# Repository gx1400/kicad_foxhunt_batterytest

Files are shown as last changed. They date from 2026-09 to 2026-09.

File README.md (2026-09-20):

# Fox Hunt Controller — Hardware Design

Custom amateur radio fox hunt (hidden transmitter) controller, aimed at being a flexible, dynamic platform for a wide range of fox-hunt formats — not just a fixed single-mode beacon. Built around an ESP32-S3, u-blox GPS module (MAX-M10S), and SA818S 2m RF module, with a WiFi/BLE web UI for configuration and "found" logging, RTOS-based scheduling, RTC-driven wake and precise TX timing, GPS-disciplined timekeeping, and APRS output capability. Firmware developed in PlatformIO. Boards fabricated and assembled via JLCPCB (including their SMT assembly service). Planned as an iterative multi-revision build, proving out core software before locking down hardware.

**Note:** this initial revision is a dev/learning board — built to test out the design, get hands-on with the parts and tooling, and work out mistakes before committing to a more polished revision.

## Contents

- [Setup](#setup)
- [Power architecture overview](#power-architecture-overview) (diagram — full detail in `_docs/`)
- **[Full docs index →](_docs/README.md)** — hardware design detail, controller/peripheral platform decisions, BOM sourcing/datasheets, open items

## Setup

All KiCad design files live under [`pcb/`](pcb/) — project file, schematics, PCB, and the vendored libraries. This project depends on three external symbol/footprint libraries, vendored as git submodules under `pcb/libs/` so the project is self-contained and doesn't require any machine-specific KiCad library setup. Project-level `sym-lib-table` and `fp-lib-table` files reference them via `${KIPRJMOD}`, so they resolve automatically once the submodules are checked out — no manual library registration needed.

Clone with submodules:

```sh
git clone --recurse-submodules https://github.com/gx1400/kicad_foxhunt_batterytest.git
```

The KiCad project file is at `pcb/foxhunt1.kicad_pro`.

Or, if already cloned:

```sh
git submodule update --init --recursive
```

Everything else (standard KiCad libraries: `Device`, `power`, `Resistor_SMD`, etc.) ships with any stock KiCad 10 install — no extra setup required.

## Power Architecture Overview

Two independent power sources feed the board, combined safely before regulation, then split into two independently-regulated rails:

```
18650 pack ──[MAX17320 protector]── +7.5V ──┐
                                              ├─[TPS2121 VCOMP]── VRAW ──[soft-latch FET]──┬─[Buck+LDO]── 5V  (SA818S)
12–14.5V input ──[fuse]── +12V ──────────────┘                                            └─[Buck+LDO]── 3.3V (ESP32-S3, GPS)
```

Full detail (battery protection, dual-input combining, regulation, the whole planned controller/peripheral platform, BOM sourcing, and open items) lives in **[`_docs/`](_docs/README.md)**.

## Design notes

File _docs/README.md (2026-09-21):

# Docs Index

Everything below the top-level [README](../README.md). Grouped by topic — add new docs to the
matching folder and list them here.

## Hardware (`hardware/`)

Design decisions and reference detail for the PCB. Start with the architecture overview, then
drill into whichever subsystem you need.

- [Power architecture overview](hardware/power_architecture.md) — the two-source-combine-then-regulate diagram, links to the three sections below
- [Battery protection & fuel gauge (MAX17320)](hardware/battery_protection.md)
- [Dual-input power combining](hardware/power_input_combining.md)
- [Regulation — VRAW → 5V/3.3V rails, downstream loads](hardware/regulation.md)
- [Controller & peripheral platform](hardware/controller_platform.md) — VRAW soft-latch, PCF8563 RTC, PCA9555 I2C GPIO expander, WS2812 status LED, CAT24C32YI-GT3 EEPROM, SD card (SPI), MCU (ESP32-S3 + dual-USB), USB power path, GPS, and audio/PTT DAC path implemented; SA818S itself, the external-HT jack, RF sensing, TX safety, frequency/tone plan, LoRa (skipped), enclosure still planned
- [ESP32-S3 pinout & interconnect plan](hardware/esp32s3_pinout.md)
- [Audio / PTT path — I2S DAC, ESP32-S3, SA818S, external HT](hardware/audio_ptt_path.md) — PCM5102A DAC + attenuator + switched external-HT jack (J11) + PTT FET (Q10) implemented
- [SA818S-V pinout & interconnect plan](hardware/sa818_pinout.md) — module placed with UART/PTT/MIC_IN wired; VBAT, ANT, PD, H/L still open
- [VHF matching network & RF forward-power detector](hardware/vhf_matching_detector.md) — parts, layout, and sourcing for the antenna matching ladder and diode-detector power-sensing tap; not yet in the schematic
- [GPS — u-blox MAX-M10S, ESP32-S3, backup power, SMA antenna](hardware/gps_path.md) — implemented, including the CR2032/supercap backup network and RF bias-tee
- [I2C bus — devices & addresses](hardware/i2c_bus.md)
- [IC inventory & alternatives](hardware/ic_inventory.md) — every IC/module used or planned, LCSC MPN/price/stock, and 1-4 scored alternates per chip
- [Open items / next steps](hardware/open_items.md) — living checklist

## Sourcing (`sourcing/`)

BOM verification and part-sourcing records — datasheets, 3D models, LCSC cross-reference.

- [Task 1 — LCSC/MPN/manufacturer cross-reference](sourcing/task1_lcsc_crossreference.md) — action-item checklist
- [kicad_gx_library datasheets](sourcing/kicad_gx_library_datasheets.md)
- [project_library datasheets](sourcing/project_library_datasheets.md)
- [3D models — search & download status](sourcing/3d_models.md)

## Firmware (`firmware/`)

Reserved for once the PlatformIO project (`src/`) exists — see [firmware/README.md](firmware/README.md).

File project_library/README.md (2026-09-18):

# Project Library

Local library resources for parts used in this project that are **not** part of the shared
`libs/kicad_gx_library/` (which holds reusable custom symbols/footprints/3D models
maintained across projects). Everything here is specific to `foxhunt1`.

## Structure

- `datasheets/` — PDF datasheets for placed components, organized into per-manufacturer
  subfolders (e.g. `Murata_Electronics/`, `YAGEO/`, `TI/`). Schematic component `Datasheet`
  fields reference these files via `${KIPRJMOD}`-relative paths. See
  `_docs/sourcing/project_library_datasheets.md` for the full part-to-file mapping, including two
  parts (BH-18650-PC, 1377G12-BK) with no available datasheet source.
- `symbols/` — reserved for project-specific KiCad symbols not in `kicad_gx_library`.
  Not yet populated.
- `footprints/` — reserved for project-specific KiCad footprints not in `kicad_gx_library`.
  Not yet populated.
- `3dmodels/` — downloaded 3D models (STEP preferred) for manual placement/alignment.
  Not linked to schematic/footprint parts automatically — see
  `_docs/sourcing/3d_models.md` for status (covers both `kicad_gx_library` and this directory).

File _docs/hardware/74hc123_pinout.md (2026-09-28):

# 74HC123 — Dual Retriggerable Monostable — Pinout & Planned Interconnects

Covers the dual retriggerable monostable multivibrator (Nexperia **74HC123D,653**, LCSC
`C5597`, SOIC-16/SOT109-1 — see `ic_inventory.md`) with **two independent planned uses on
this board**: one section as the TX-safety PTT hardware timeout (`controller_platform.md`
§ TX safety), the other — the "spare half" — as the hardware force-off failsafe
(`open_items.md`). KiCad symbol `74xx:74HC123` / footprint
`Package_SO:SOIC-16_3.9x9.9mm_P1.27mm` (stock libraries, both pin-verified against
Nexperia's own datasheet — no library fix needed).

**This part is not placed in the schematic yet** (`open_items.md`: "the 74HC123 isn't
placed in the schematic either way"). Everything below is a planning document, same rigor
level as `vhf_matching_detector.md` before that ladder existed: real pin functions from the
datasheet, but "planned tie/connection" is intent pulled from `controller_platform.md` /
`open_items.md` / `audio_ptt_path.md`, not something to treat as already wired. Two of the
four trigger nets involved (the retrigger source for the TX-timeout half, and the level of
    `POWER_PB_SIGNAL` feeding the force-off half) depend on design decisions that aren't made
yet either — flagged individually below, and again in § 4.

## 1. Full pin table

Reference: Nexperia `74HC_HCT123` datasheet Rev. 13 (2024-02-21), Table 2 (pin
description) and Table 3 (function table), SO16/SOT109-1 pinout.

| Pin | Name | I/O | Function (per Nexperia's own datasheet) | Planned tie/connection |
| --- | --- | --- | --- | --- |
| 1 | 1A | I | Negative-edge triggered input, unit A (Schmitt) | **Unit A = TX-safety timeout.** Not yet decided whether A or B is the active retrigger input for this half — see § 3. If unused, tie to the level the function table calls for with the other input active (function table: triggering needs `nRD`=H; with `nB`=H, a falling edge on `nA` triggers — so if B is the active input instead, tie `1A` low). |
| 2 | 1B | I | Positive-edge triggered input, unit A (Schmitt) | Mutual with `1A` above — whichever of A/B carries the periodic MCU "keep transmitting" pulse from the PTT-intent path; the other ties to its inactive level. |
| 3 | 1R̄D | I | Direct reset LOW (async, overrides everything) + positive-edge triggered input | Planned: pulled to VCC (inactive) unless a system-level "kill PTT now" reset source is defined. Also see the datasheet's own power-up-glitch note (§ Application information, Fig. 12) — an R̄D-side RC network held low briefly after power-up avoids a spurious startup pulse, which here would mean a spurious momentary PTT key. Not yet designed. |
| 4 | 1Q̄ | O | Active-LOW output, unit A | Planned, with `13`/`1Q`: series-gates the existing PTT path (`IO16` → `Q10` → `J11` → SA818S/HT `PTT`, see `sa818_pinout.md`/`audio_ptt_path.md`) per `controller_platform.md` § TX safety — "gates the PTT line in series with the MCU's own PTT-intent GPIO." Exact insertion point (ahead of `Q10`'s gate, in series with its drain, or ahead of the still-unselected PTT-keying optocoupler) is undecided — open item. |
| 13  | 1Q | O | Active-HIGH output, unit A | See `1Q̄` above — whichever polarity fits the eventual gate implementation. |
| 14  | 1CEXT | — | External timing capacitor connection, unit A | Planned RC timing network for the **2-minute hard TX ceiling** — see § 3 for calculated starting values. Per the datasheet's own app-note (Fig. 11): cap goes between this pin and `15`/`1REXT/CEXT`. |
| 15  | 1REXT/CEXT | — | External timing resistor+capacitor connection, unit A | Resistor to VCC, per the same app-note figure. See § 3 for values. |
| 5 | 2Q | O | Active-HIGH output, unit B | **Unit B = spare-half hardware force-off failsafe** (`open_items.md`). Planned to assert an override of `PWR_LATCH`/`Q6`'s hold (`controller_platform.md` § Power sequencing) if the software hold-to-power-off timeout is exceeded. The actual override mechanism — how a one-shot output edge forces `PWR_LATCH` low against a possibly-still-asserting `Q6` — is the main undecided piece here, not just an RC value. |
| 6 | 2CEXT | — | External timing capacitor connection, unit B | RC target: "longer than the software hold threshold" (`open_items.md`). That firmware threshold isn't documented yet (hold-to-power-off firmware is itself still TBD per the same doc), so no concrete value can be calculated for this half yet — blocked on a firmware constant, unlike unit A's timing. |
| 7 | 2REXT/CEXT | — | External timing resistor+capacitor connection, unit B | Same block as `2CEXT` above. |
| 8 | GND | — | Ground | Planned: `GND`. |
| 9 | 2A | I | Negative-edge triggered input, unit B (Schmitt) | Planned force-off trigger, per `open_items.md`'s leading option: "triggered directly by SW3 (or its isolated `POWER_PB_SIGNAL` node)." **See the voltage-domain flag in § 4 — this can't actually be direct.** |
| 10  | 2B | I | Positive-edge triggered input, unit B (Schmitt) | Mutual with `2A` — same flag applies. |
| 11  | 2R̄D | I | Direct reset LOW (async) + positive-edge triggered input, unit B | Same treatment as `1R̄D` (tie inactive, consider the Fig. 12 power-up RC). Also the natural place to let firmware abort the hardware failsafe once a normal software power-off succeeds in time, if that's ever wanted — not yet decided. |
| 12  | 2Q̄ | O | Active-LOW output, unit B | See `2Q` above. |
| 16  | VCC | — | Supply, 2.0–6.0V (74HC) | Planned: not yet decided which rail — see § 4. |

## 2. Trigger logic (datasheet Table 3, function table)

For either unit, with `nR̄D` = HIGH: a falling edge on `nA` while `nB` is HIGH triggers a
new pulse, or a rising edge on `nB` while `nA` is LOW triggers a new pulse — either
re-triggers (extends) an already-running pulse the same way. `nR̄D` = LOW forces `nQ` LOW /
`nQ̄` HIGH immediately regardless of `nA`/`nB`, overriding any in-progress pulse. This is
what makes it *retriggerable*: as long as the active input keeps getting valid edges before
the RC-timed pulse would otherwise end, the output stays asserted indefinitely — exactly
the property the TX-safety design in `controller_platform.md` depends on ("the MCU must
periodically retrigger it during a legitimate transmission").

## 3. Unit A — TX-safety timeout: starting RC values

Target: **2-minute (120s) hard ceiling** per `controller_platform.md` § TX safety.

Datasheet's own pulse-width formula (§10, footnote [2], valid for `CEXT` > 10nF):

```
tW (ns) = K × REXT (kΩ) × CEXT (pF)
K ≈ 0.45 at VCC = 5.0V, ≈ 0.55 at VCC = 2.0V (Fig. 6 — K drifts with VCC, "typical" only)
```

Recommended `REXT` range per the datasheet's own dynamic-characteristics table: 2kΩ–1000kΩ
at VCC = 5.0V. Solving for `tW` = 120s = 1.2×10¹¹ ns at K = 0.45:

| REXT | Required CEXT | Notes |
| --- | --- | --- |
| 470kΩ | ≈ 560µF | Mid-range R, needs a real electrolytic/tantalum at this value — not a ceramic. |
| 1MΩ (datasheet's own max) | ≈ 270µF | Smaller, cheaper cap; R right at the recommended ceiling. |

**Rigor note, same as this board's other tuned RC/LC values (matching network, mic
attenuator):** this is a calculated starting point from the datasheet's typical-K formula,
not a bench-verified number — `K` itself is only characterized at the 2V/6V endpoints in
the datasheet (Fig. 6), and electrolytic/tantalum tolerance at these values is loose.
Populate one of the pairs above, then verify the actual timeout against a bench timer
before trusting it for the real 2-minute ceiling. Per the datasheet's own app-note (Fig.
11): `CEXT` connects between pins 14/6 and 15/7, `REXT` from pin 15/7 to VCC.

Also relevant to the retrigger-pulse firmware: the datasheet gives a **minimum retrigger
interval** formula (§10, footnote [3]) — `t_rtrig ≈ 30 + 0.19×REXT×CEXT^0.9 +
13×REXT^1.05` ns (REXT in kΩ, CEXT in pF) — the MCU's periodic "still transmitting" pulses
need to be spaced at least this far apart to reliably retrigger rather than being missed;
at the values above this works out to a floor far below any sane firmware polling
interval, but it's a real constraint worth having in the design record.

## 4. Open design questions (nothing here is schematic yet)

- **`POWER_PB_SIGNAL` can't feed unit B directly, despite how `open_items.md` phrases it.**
  `POWER_PB_SIGNAL` is pulled up to `VRAW` through R45 (`controller_platform.md`), so it
  swings across `VRAW`'s full range (up to ~14.4V) — not a 3.3V/5V logic level. The
  74HC123's own absolute-max rating is `VI` ≤ `VCC` + 0.5V with `VCC` capped at 7V (Table 4,
  limiting values). Raw `POWER_PB_SIGNAL` already couldn't go straight into `GPIO38` for
  the same reason — that's exactly why `Q9` (BSS138) exists as a level-shift stage there
  (`esp32s3_pinout.md`, pin 31). Unit B's trigger will need the same kind of level-shift
  stage in front of it, not a direct wire.
- **VCC rail choice — 3.3V vs 5V — not yet decided.** Both are within the datasheet's
  2.0–6.0V recommended range. 3.3V would match the MCU GPIO logic that both trigger paths
  ultimately originate from (unit A's retrigger pulse, and a level-shifted `POWER_PB_SIGNAL`
  for unit B via a `Q9`-style stage); 5V would match the SA818S/`VBAT` domain the PTT
  circuit downstream of unit A ultimately touches. Pick one before laying out the timing
  RC networks, since it also shifts `K` slightly (§ 3).
- **Stale cross-reference:** `audio_ptt_path.md` § 3 still describes a "MCU PTT-intent GPIO
  (`IO15`) → 74HC123 TX-safety gating" chain. `esp32s3_pinout.md`'s own live-schematic audit
  (item 7 in its notes) says that two-GPIO AND-gate scheme isn't what got built — PTT today
  is a single GPIO (`IO16`) straight into `Q10`, and `IO15` is free again. Worth updating
  `audio_ptt_path.md` § 3 once the real 74HC123 gating point is designed, so it stops citing
  a scheme that was already abandoned.
- **Exact PTT-gating insertion point** (unit A) — series with `Q10`'s gate, its drain, or
  ahead of the still-unselected PTT-keying optocoupler (`ic_inventory.md`) — undecided.
- **Exact force-off override mechanism** (unit B) — how the output edge actually forces
  `PWR_LATCH` low against a possibly-still-asserting `Q6` — undecided; flagged in
  `open_items.md` as "next thing being worked on," not yet started.
- **Power-up glitch handling** (both halves) — the datasheet's own Fig. 12 circuit (an RC
  network holding `nR̄D` low briefly after power-up) prevents a spurious pulse at boot; for
  unit A that would mean a spurious momentary PTT key, for unit B a spurious force-off
  assertion. Not yet designed either.

## 5. Reference documents

- [`ic_inventory.md`](ic_inventory.md) — Nexperia `74HC123D,653` sourcing (LCSC `C5597`,
  SOIC-16/SOT109-1, $0.33 5pc).
- [`controller_platform.md`](controller_platform.md) § TX safety, § Power sequencing — the
  two design intents this part serves.
- [`open_items.md`](open_items.md) — the force-off item that names this part as the leading
  option.
- [`audio_ptt_path.md`](audio_ptt_path.md) § 3 — the PTT chain this gates into (see the
  staleness flag in § 4 above).
- [`esp32s3_pinout.md`](esp32s3_pinout.md) — `IO16`/`IO15` (PTT-intent), `IO38`/`IO48`
  (hold-to-power-off / self-latch) pin assignments.
- **[Nexperia 74HC123;74HCT123 datasheet](https://assets.nexperia.com/documents/data-sheet/74HC_HCT123.pdf)**,
  Rev. 13 (2024-02-21) — pin table (§5), function table (§6), timing/retrigger formulas
  (§10, footnotes [2]/[3]), application info and power-up circuit (§11, Fig. 11/12).

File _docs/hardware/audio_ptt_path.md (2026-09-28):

# Audio / PTT Path — I2S DAC ↔ ESP32-S3 ↔ SA818S / External HT

Not yet in the schematic — this is the interconnect plan for the next placement pass,
covering the I2S DAC (PCM5102APWR, already chosen — see `ic_inventory.md`), its link to the
ESP32-S3, and how its output (and the PTT-keying signal) reach both the onboard SA818S
footprint and the external-HT 3.5mm jack. See `controller_platform.md` § Audio / PTT path
for why this is one shared subsystem serving two destinations, not two separate designs.

## 1. DAC ↔ ESP32-S3 (I2S bus)

**Part: TI PCM5102A** (20-pin TSSOP, `C107671`). Real pin table, from TI's own datasheet
(PCM5100A/5101A/5102A family, SLAS859A):

| Pin | Name | Function | Planned tie/connection |
| --- | --- | --- | --- |
| 12 | SCK | System clock input | **Tie to GND.** Selects the DAC's internal PLL auto-clock mode — no master clock (MCLK) needed from the MCU. ESP32-S3's I2S peripheral doesn't need to supply one either; this is the standard simplified hookup used by every hobbyist PCM5102 breakout (Adafruit's included — see § 4). |
| 13 | BCK | Bit clock input | ESP32-S3 IO14 (`esp32s3_pinout.md` — currently documented as I2S BCLK) |
| 14 | DIN | Serial audio data input | ESP32-S3 IO47 (documented as I2S DOUT — MCU transmits, DAC receives) |
| 15 | LRCK | Word clock (L/R select) input | ESP32-S3 IO21 (documented as I2S LRCLK/WS) |
| 16 | FMT | Audio format select (Low = I2S, High = left-justified) | **Tie to GND** — I2S format, matches ESP32-S3's I2S peripheral default |
| 10 | DEMP | De-emphasis control (Low = off) | **Tie to GND** — no de-emphasis needed |
| 11 | FLT | Filter select (Low = normal latency, High = low latency) | **Tie to GND** — normal latency; nothing in this design needs low-latency monitoring |
| 17 | XSMT | Soft-mute control (Low = mute, High = un-mute) | **Needs a decision** — simplest is tie to `+3.3V` (always un-muted, matches PCM5102A's own DirectPath output design which needs no external mute circuit for pop-free power-up per TI's datasheet), but see § 3 for why the switching mechanism might want to drive this from a spare GPIO instead |
| 6 | OUTL | Analog output, 2.1V<sub>RMS</sub> line level | → level-matching network → SA818S/HT (§ 2) — SA818S is mono, only one channel is needed (confirmed: its `MIC_IN` and `AF_OUT` are each a single pin, no L/R pair, per its own datasheet) |
| 7 | OUTR | Analog output, 2.1V<sub>RMS</sub> line level | → standard RC output filter only (no attenuator — nothing mic-level on this leg) → spare JST breakout (§ 2), for future use |
| 1, 8, 20 | CPVDD, AVDD, DVDD | Power, 3.3V | `+3.3V` |
| 18 | LDOO | Internal LDO decoupling (or external 1.8V) | Decoupling cap only, per datasheet — not using external 1.8V supply mode |
| 3, 9, 19 | CPGND, AGND, DGND | Grounds | `GND` |
| 2, 4 | CAPP, CAPM | Charge-pump flying cap | Per datasheet's charge-pump cap network |
| 5 | VNEG | Charge-pump negative rail (-3.3V) | Decoupling only |

Recommended output filter, straight from TI's own datasheet (footnote on the dynamic
performance table): **470Ω series resistor + 2.2nF shunt cap** per channel, into a ≥10kΩ
load. This is the standard simple RC low-pass already anticipated in
`controller_platform.md` ("I2S DAC → RC filter").

**ESP32-S3 side**: IO14/IO21/IO47 already reserved in `esp32s3_pinout.md`. No MCLK pin
reserved — confirmed not needed per SCK-tied-low above.

## 2. DAC output ↔ SA818S / external HT (level matching + switching)

**Confirmed: SA818S is mono** — `MIC_IN` (pin 18) and `AF_OUT` (pin 3) are each a single
pin in its datasheet, no L/R pair. Only `OUTL` is needed for the SA818S/HT path. `OUTR`
is otherwise unused, so it gets the standard 470Ω + 2.2nF output filter (same as `OUTL`,
no attenuator — there's no mic-level target on this leg) and is broken out to its own
spare JST connector for future use.

**Now placed in the schematic** (`audio.kicad_sch`, verified 2026-09-20): both channels'
output filters and the charge-pump network are built and match this doc's plan —

- `OUTR` → R47 (470Ω) → C63 (2.2nF to GND) → **J9** (spare 3-pin JST, pins 2/3 to GND) — done.
- `OUTL` → R48 (470Ω) → C64 (2.2nF to GND) → currently ends at an open node, awaiting the
  attenuator network (§ below) and the SA818S/HT connection once placed.
- Charge pump: C55 (2.2µF, `CAPP`↔`CAPM` flying cap) and C56 (2.2µF, `VNEG`↔`GND`
  reservoir cap) — matches TI's Figure 39/41 reference circuit.
- `XSMT` is wired to a live hierarchical label (`I2S_XSMT`) back to the ESP32-S3 sheet
  rather than hard-tied — the tie-off decision below is resolved as GPIO-controlled,
  not tied high; not yet confirmed which physical GPIO drives it.

**OUTL → MIC_IN attenuator — now placed** (`audio.kicad_sch`, verified 2026-09-20):
`R49` (100kΩ, top fixed) → `RV1` (Bourns 3314G, 1kΩ single-turn trimmer,
`Potentiometer_SMD:Potentiometer_Bourns_3314G_Vertical` — real stocked footprint;
note it's single-turn, not 10-turn — no genuine 10-turn part in the LCSC list checked
had a matching KiCad footprint) → `R50` (150Ω floor) → GND. Trimmer's full travel spans
roughly 3–24mV (bracketing the SA818S datasheet's ~10mV reference point), never close to
overdriving the mic input even at either extreme. `R_top` at 100kΩ is comfortably above
the 470Ω filter resistor (won't detune its corner) and the PCM5102A's own ≥10kΩ minimum
load spec.

**DC-blocking cap — placed.** C65 (4.7µF, `Device:C_Small` — non-polarized ceramic, 0603)
sits correctly in series between `RV1`'s wiper and the net that will eventually reach
`MIC_IN`. Sized so the high-pass corner stays under ~70Hz even in a pessimistic
(~500Ω) assumption for the divider's output impedance plus `MIC_IN`'s undocumented input
impedance — comfortably below the ~300Hz low end of a voice/NBFM channel.

**`I2C_MIC_OUT` sheet pin — now added.** The net downstream of C65 has a real sheet pin
on the Audio sheet symbol (root level) exposing it out of the sheet. It currently ends
at a `no_connect` stub on the root sheet (nowhere to route it yet, since SA818S isn't
placed) — expected/fine for now, revisit once SA818S is placed. The `I2C_` prefix on
this net name is still misleading (this is analog audio, not the I2C bus) — rename
whenever convenient (e.g. `AUDIO_MIC_OUT`), no rush since nothing depends on the name yet.

**XSMT — now wired to the MCU, decision made and kept.** `I2S_XSMT` is wired across the
hierarchy to **ESP32-S3 GPIO3** (`I2C_MUTE_XSMT` net) — this was the project's one
remaining genuinely-spare GPIO (`esp32s3_pinout.md` previously flagged it as such); it's
now spent on this. `esp32s3_pinout.md`'s summary line and pin table should be updated to
reflect GPIO3 as used, not spare. Net name carries the same misleading `I2C_` prefix as
above — same low-priority rename recommendation.

**XSMT — placed, but the MCU-override path isn't live yet.** `R46` (10kΩ) pulls
`I2S_XSMT` up to `+3.3V` (matches PCM5102A's DirectPath default-unmuted design). The
hierarchical label exists in `audio.kicad_sch`, but the Audio sheet's parent instance
only exposes 3 sheet pins (`I2S_BCK`/`I2S_DIN`/`I2S_LRCK`) — no `I2S_XSMT` pin yet, so
right now this net is local to the sheet and behaves as a hard pull-up. Add a 4th sheet
pin + GPIO route later if MCU-controlled muting is wanted.

**Critical point, easy to miss:** PCM5102A's output is genuine **line level** (2.1V<sub>RMS</sub>
nominal). SA818S's `MIC_IN` (pin 18) is sized for **microphone-level** signals — its own
datasheet's modulation-frequency test table specifies only **~10mV** typical input for a
1.5/2.5kHz deviation test point. Feeding 2.1V<sub>RMS</sub> straight into `MIC_IN` would grossly
overdrive the modulator (excess deviation, splatter) even though the pin is nominally
labeled "Microphone or line in" — that label describes what it'll pass electrically, not
that it's correctly leveled for a line-level source. **A resistor-divider attenuator
between the DAC output (post-RC-filter) and `MIC_IN` is required**, not optional — exact
divider ratio is a TBD depending on the DAC's actual output swing at whatever digital
gain firmware uses; needs bench-tuning against a real deviation measurement, not just a
datasheet-derived guess.

**Switching between SA818S and the external HT jack — superseded plan, 2026-09-21.**
Earlier framing (jumper vs. PCA9555-controlled switch) is replaced by a simpler mechanical
approach using the external jack itself:

**External jack connector plan.** One standard 3.5mm TRS/TRRS jack (not the K1 module's own
2-jack 3.5mm+2.5mm split — that split exists on the *radio* side; off-the-shelf "K1 to
3.5mm" adapter cables, e.g. the BTECH one sold for Baofeng/Kenwood-style radios, bridge
between a standard PC/phone-style 3.5mm plug and the radio's actual K1 socket, so this
board only needs the standard-headset side). Real K1 pinout for reference (Wildtalk's
documented reference; clone radios vary): radio's own 3.5mm jack is Tip=PTT (short to
ground to transmit), Ring=Mic (radio provides phantom power), Sleeve=5V tap; radio's 2.5mm
jack is Ground/Program/Speaker-out — not replicated here since this design doesn't need the
speaker/program functions.

**Planned wiring**: Tip = attenuated mic-level audio (shared with SA818S `MIC_IN`), Ring =
PTT (shared with SA818S `PTT`), Sleeve = `GND`.

**Switching mechanism: a jack with two independent normally-closed switch contacts**, not
a jumper. Plugging in disconnects the SA818S from *both* the audio feed and the PTT feed
simultaneously (one NC contact per conductor) — important because PTT is otherwise wired
in parallel to both destinations, and without this, keying PTT while something's plugged in
would transmit on both the SA818S and the external radio at once (harmless if the SA818S
has no antenna connected, a real mutual-interference risk if it does). Look for a switched
3.5mm jack part (e.g. Cliff/CUI parts marketed with "SW"/detect contacts) with enough
independent switch poles for this. PTT is a direct short-to-ground per the real K1 spec —
compatible with the already-planned optocoupler/relay-style PTT output (not a raw GPIO
logic level), so the same PTT-keying hardware likely drives both destinations unmodified.

**Open assumption**: routing the SA818S-tuned attenuator output to an arbitrary external
radio assumes similar mic sensitivity — reasonable for most cheap HTs (similar electret-
level inputs) but not verified against a specific target radio.

**RX audio (the other direction)**: SA818S `AF_OUT` (pin 3) — typical 700mV amplitude,
200Ω output impedance per its own datasheet — feeds an external amplifier (SA818S's
`Audio ON` pin 1 auto-controls that amp: outputs LOW to enable it, HIGH to disable —
active-low enable, worth remembering when wiring). This project doesn't currently plan to
route RX audio back into the MCU (no on-board speaker amp chosen yet) — flagging as an
open item if audio monitoring/recording is ever wanted, out of scope for TX-path wiring.

## 3. PTT-keying path

**SA818S `PTT` (pin 5)**: active-low input — "0" forces TX, "1" is RX. Matches this
project's already-documented convention ("PTT line defaults to released... pull resistor
sized accordingly," per `controller_platform.md` § TX safety) — needs a pull-up to keep it
released (RX) whenever the driving GPIO/optocoupler output is undriven or in reset.

**Planned chain**: MCU PTT-intent GPIO (IO15, per `esp32s3_pinout.md`) → 74HC123 TX-safety
gating (not yet built — see `open_items.md`) → PTT-keying optocoupler (still unconfirmed
part — `ic_inventory.md` has 3 scored candidates, PC817-class) → `PTT` pin, isolating the
MCU's 3.3V domain from whatever the SA818S/external-HT PTT circuit actually needs
electrically. Same switching consideration as the audio path applies here too — if the
destination (SA818S vs. external HT) is jumper-selected, the keyed PTT signal needs to
reach whichever one is currently active, ideally through the same switching mechanism
rather than a second independent jumper.

**Two other SA818S pins worth remembering during layout** (not part of the audio/PTT path
itself, but adjacent, real constraints from its own datasheet):

- `PD` (pin 6) — power-down control, "0" = power down, "1" = normal work. Needs a defined
  level (not left floating) — likely tied to whatever gates the module's own power, or a
  simple pull-up if the module should always be enabled whenever its VBAT is present.
- `H/L` (pin 7) — output power select. Datasheet explicitly warns: **"this pin can NOT be
  connected to VDD or high level of CMOS output"** — leave open for high power, or pull to
  a level BELOW logic-high explicitly (not a GPIO driven high) if low power is ever wanted.
  Worth a note directly in the schematic once this is placed, since it's an easy-to-violate
  constraint.

## 4. Reference schematics

Real, open-source references worth reviewing before finalizing values:

- **[Adafruit PCM510x I2S DAC breakout](https://github.com/adafruit/Adafruit-PCM510x-I2S-DAC-PCB)**
  — real, fabricated open-hardware board using this exact chip family (PCM5102/PCM5100).
  Confirms the SCK-tied-low, no-MCLK-needed hookup in practice, not just datasheet theory.
  Full write-up: [Adafruit Learn guide](https://learn.adafruit.com/adafruit-pcm510x-i2s-dac)
  (PDF: [here](https://cdn-learn.adafruit.com/downloads/pdf/adafruit-pcm510x-i2s-dac.pdf)).
- **[NiceRF SA818 datasheet](https://logifind.com/u_file/2108/file/91fb17a776.pdf)** —
  manufacturer's own datasheet, includes a typical application schematic (§6, page 4) that
  is the closest thing to a manufacturer reference circuit for the MIC_IN/PTT/AF_OUT wiring
  — worth comparing against once the attenuator network is sized.
- **[jumbo5566/sa818 on GitHub](https://github.com/jumbo5566/sa818)** — a real open-source
  project ("USB audio CM108 Sound Card PTT Controller + SA818/SR-FRS Programming Tool")
  interfacing a sound-card-level audio output and a PTT control line to this exact module —
  a practical, working precedent for the same audio-level + PTT-isolation problem this
  design is solving, from a different host (PC sound card) instead of an I2S DAC, but the
  MIC_IN attenuation and PTT-isolation concerns are the same.
- **[TI PCM5102A/PCM5100A/PCM5101A datasheet](https://www.ti.com/lit/ds/symlink/pcm5102a.pdf)**
  — source for the pin table and output-filter values in § 1.

## Open items

- Attenuator network (`R49`/`RV1`/`R50`/`C65`, § 2) for `OUTL` → `MIC_IN` — placed in
  `audio.kicad_sch`. Exact trimmer setting still needs a real bench deviation measurement
  once SA818S is placed, not just the calculated nominal target.
- External HT jack: pick a real switched 3.5mm TRS/TRRS part (two independent NC contacts,
  one per audio/PTT conductor — see § 2) and verify it against a real datasheet, same rigor
  as this project's other connector choices. Not yet sourced.
- Confirm which ESP32-S3 GPIO drives `I2S_XSMT` (wired as a live net, not hard-tied —
  tie-off decision is resolved, just needs the specific pin documented here and in
  `esp32s3_pinout.md`).
- `PD` and `H/L` pin handling once SA818S is actually placed (DNP per `ic_inventory.md`,
  but still needs real net connections in the schematic).
- PTT-keying optocoupler part finalization (see `ic_inventory.md` § PTT-Keying Optocoupler).

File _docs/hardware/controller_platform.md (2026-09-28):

# Controller & Peripheral Platform

Design decisions for the controller section. **Power sequencing, Timekeeping, status
indication (I2C GPIO expander + WS2812 status LED), the EEPROM (storage), GPS, and the
audio/PTT DAC path are now implemented in the schematic** (`power.kicad_sch`'s soft-latch
stage; the `Peripherals` sheet's PCF8563 RTC, PCA9555 expander, and CAT24C32YI-GT3 EEPROM
circuits; the WS2812 LED on `mcu-esp32.kicad_sch`; the SD card interface, also on
`mcu-esp32.kicad_sch`; the `GPS` sheet's MAX-M10S + backup network + bias-tee; the `Audio`
sheet's PCM5102A + attenuator); the SA818S footprint, the external-HT jack, RF power
sensing, and TX-safety timeout are still planning-only. See [Open Items](open_items.md) for what's left. Target
capabilities:
audio/voice TX, CW ID keying, variable-duration/interval blipping, variable TX power, APRS
TX with GPS (dithered position optional), randomized CTCSS tone, frequency hopping, a
WiFi/BLE "found" log, RTC-scheduled precise-interval TX, and schedulable mode changes
(e.g. more frequent TX the longer a fox goes unfound).

## Power sequencing — discrete soft-latch (implemented)

MAX17320 protects/fuel-gauges the battery but doesn't gate system power — that's a separate circuit. A P-FET soft-latch (Q5, AO3407A — picked over AO3401A for its ±20V Vgs rating, comfortably covering VRAW's 7–14.4V swing with no gate-clamp zener needed) sits between VRAW and Power Regulation's input, gated by the shared wake node:

- **Wake sources are wire-ORed** (not literally diode-ORed — see below) onto one active-low node, pulled up to VRAW through R29 (1MΩ, sized to keep standby bleed in the single-digit µA range across VRAW's full voltage span rather than something that would meaningfully shorten shelf life): the power button (SW3), the RTC interrupt chain, and the MCU's own latch-hold output. Any of them pulling the node toward GND turns Q5 on.
- **MCU self-latch:** GPIO48 (open-drain intent, 3.3V logic) drives Q6 (BSS138) as a voltage-isolating buffer — GPIO48 can never be exposed to VRAW's up-to-14.4V swing, only ever sees 0–3.3V on its own side. Q6 pulls the wake node low to hold power on; releasing it (firmware shutdown housekeeping) lets R29 pull the node back to VRAW and the system goes fully dark — true zero-current off, not MCU sleep.
- **Hold-to-power-off detection — implemented.** SW3 needed its own isolated read of "is the button physically being held," independent of whatever else is currently asserting the shared wake node (RTC INT, or the MCU's own self-latch above) — reading the wake node directly would have made "button held" indistinguishable from "system is just normally running." Solved the same way as the RTC INT path: SW3's pin 2 now lands on its own node (`POWER_PB_SIGNAL`), pulled up to VRAW through R45 (1MΩ, same standby-current reasoning as R29) instead of tying directly to the wake node. D5 (BAS116LT1G, anode on the wake-node side / `PWR_LATCH`, cathode on `POWER_PB_SIGNAL`) diode-ORs SW3's press back into the wake node so it still asserts power-on as before, while blocking the reverse path — so nothing else asserting the wake node can pull `POWER_PB_SIGNAL` down. That isolated signal crosses the hierarchy (`POWER_PB_SIGNAL` → `MCU_IN_PWR_BTN`) to a BSS138 stage (Q9) on the `mcu-esp32` sheet, which level-shifts it into GPIO38 (R44, 10k pull-up) for firmware to poll. Verified: idle → GPIO38 low; SW3 held → GPIO38 high (active-high on this pin specifically, opposite the passive-pull-up-active-low convention used elsewhere — worth flagging clearly in firmware).
- **Still open:** the firmware itself (polling GPIO38, timing the hold, releasing GPIO48) hasn't been written — schematic only exposes the signal. And a **firmware-independent hardware force-off** is still unbuilt — see [Open Items](open_items.md) for the leading option (spare half of the TX-safety 74HC123).
- **RTC wake path:** PCF8563's `INT` is open-drain **active-low**, not active-high, and its own absolute max voltage rating (6.5V) is well under VRAW's range — so it can't be wired to the wake node directly either. The actual chain is `INT` → Q8 (AO3407A, a small 3.3V-domain inverter so the *sense* comes out right — INT low asserts, not releases) → Q7 (BSS138, the same voltage-isolating role as Q6) → wake node. R30 (10k) is INT's own pull-up; R31 (100k) holds Q7's gate at a defined low/off state whenever Q8 isn't actively driving it. This is more circuitry than "diode-ORed" implies, but the earlier plan's instinct was right — INT genuinely can't touch the high-voltage node without protection.
- Bench-test provision: JP24 (`usbc-programming-uart.kicad_sch`) can exclude USB from both TPS2121 rail muxes, so the whole sleep/wake cycle is testable on the bench with a debug USB cable still attached — gating downstream of the muxes instead was rejected because it would leave the
  bucks/LDOs always powered, defeating the standby-current point (this reasoning isn't
  separately written up in [usb_battery_power_mux.md](usb_battery_power_mux.md), noting
  here in case that doc is ever restructured).

## Timekeeping — PCF8563 RTC (implemented)

**PCF8563** (I2C, external 32.768kHz crystal — NDK NX3215SA-32.768K-STD-MUA-9, 9pF, matching the datasheet's CL=8pF characterization condition better than a 12.5pF part would), not DS3231. DS3231's integrated TCXO gives better standalone accuracy (±2ppm) and needs no external crystal, but costs ~15-20x more (~$9-10.50 vs. ~$0.50 at JLCPCB) for a benefit this design doesn't need — accuracy is maintained instead by periodically disciplining the RTC from GPS whenever it has a fix, and drift over a single unattended event is forgiving either way. PCF8563 has an integrated OSCO-side load capacitor, so no discrete load-cap pair is needed — just an optional DNP trim cap (C43) on OSCI if fine-tuning ever proves necessary.

Backup: **coin cell** (CR2032, BT3), diode-ORed at VDD with the main 3.3V rail (D2/D3, Nexperia BAS116 — genuinely low-leakage, ~3pA typical, verified against its own datasheet rather than assumed, since ordinary diode reverse leakage can be comparable to or exceed the RTC's own nanoamp-class backup draw). No supercap option for the RTC specifically — a supercap can't hold time across the months/years this board may sit idle between events (self-discharges in days-to-weeks), where a coin cell holds ~10 years. Losing RTC time after long storage is an accepted, low-consequence tradeoff (resolved for free by GPS resync at next power-up).

**Firmware note:** `CLKOUT` defaults to *enabled* (32.768kHz) at power-on per the register reset table (`CLKOUT_control`, address `0Dh`, bit `FE`) — unused in this design (left unconnected), but firmware must explicitly disable it (`FE=0`) or the RTC's backup current roughly doubles (500–750nA → 950–1700nA per the datasheet) for a pin nothing listens to.

I2C bus (`PERIPH_SDA`/`PERIPH_SCL`, shared with the MAX17320 fuel gauge and the EEPROM) has its one pull-up pair (R32/R33, 10k to 3.3V) on the `mcu-esp32` sheet, not duplicated per device.

## GPS — u-blox MAX-M10S (implemented)

UART+PPS (not I2C — see `gps_path.md`'s judgment call #1), external active antenna via **SMA connector** (not an integrated patch). Backup power kept **separate from the RTC's coin cell** — its own backup domain with a coin-cell holder (`BT4`) and a real supercapacitor (Cornell Dubilier/Knowles EDC474Z5R5V), a 3-diode network (not a straight mirror of the RTC's 2-diode pattern — the supercap needs to charge, so it can't share the coin cell's blocking diode), feeding `V_BCKP` so ephemeris/RTC survive short sleeps for a fast warm-start instead of a full cold-start reacquisition. Now placed and wired in `gps.kicad_sch`.

Full pin-by-pin interconnect plan (real pin table, backup-power sizing math, antenna
bias-tee reference circuit): [gps_path.md](gps_path.md).

## MCU — ESP32-S3-WROOM-1-N8R8

Module (not bare chip) — this board already has one RF section to get right (SA818S); a second self-laid-out antenna-matching problem on the MCU's WiFi/BLE radio isn't worth it for this revision. N8R8 (8MB flash + 8MB PSRAM) — PSRAM matters more than extra flash for the concurrent WiFi + audio buffering + SD card workload. **BLE enabled** alongside WiFi — free with the same radio, gives a lower-power/faster-handshake alternative to the WiFi captive portal for the "found" log.

Full pin-by-pin plan: [esp32s3_pinout.md](esp32s3_pinout.md).

**JTAG comes free over the native USB-C connector** — ESP32-S3's native USB includes a built-in USB Serial/JTAG peripheral (CDC serial + full OpenOCD-compatible debug access, simultaneously, no extra pins). No separate JTAG header needed. BOOT/RESET buttons are still included regardless as a manual fallback.

**Two USB connectors, not a hub chip: native USB direct to the module, plus a separate USB-UART bridge on its own port.** Considered mirroring Espressif's newer DevKitC-1 reference design (single USB-C → onboard USB hub chip → both a USB-UART bridge and the module's native USB), but that pattern earns its keep on a retail dev board where connector count matters to strangers unfamiliar with the board. Here it just adds a hub IC, its own layout/power budget, and another thing that can fail, for no benefit this project needs. Two small connectors is cheaper and simpler:

- **Native USB-C** — direct to IO19/IO20 (USB_D-/D+), as before: JTAG, native USB CDC, and esptool flashing.
- **USB-UART bridge (CP2102N-class), own connector** — solves two real annoyances with native-USB-only boards during active firmware iteration: (1) the native USB CDC device re-enumerates on every reset/flash cycle, which drops/delays the serial monitor and can eat early boot log lines; a UART bridge's virtual COM port stays enumerated across ESP32-S3 resets. (2) auto-reset-into-bootloader over native USB has known version-dependent quirks (esptool/OS-driver dependent) — a real bridge's DTR/RTS auto-reset into EN/IO0 (the standard two-transistor circuit) is reliable and well-established. Manual BOOT/RESET buttons remain as the ultimate fallback either way (e.g. no bridge cable plugged in).

## Audio / PTT path (shared by onboard SA818S and external HT)

Full pin-by-pin interconnect plan (DAC↔ESP32-S3, DAC↔SA818S/HT level matching, PTT
isolation, reference schematics): [audio_ptt_path.md](audio_ptt_path.md).

The SA818S has **no digital baseband input** — its UART is control-only (frequency, squelch, volume, CTCSS/DCS). Voice, CW tone, and AFSK for APRS all have to arrive as analog audio on its MIC pin, so an audio DAC (I2S DAC → RC filter, or PWM+filter) is required regardless of "digital vs. analog" framing.

This is one shared subsystem serving two destinations, not two separate designs: the same DAC output and PTT-keying circuit (optocoupler) route to *both* the onboard SA818S footprint (populated later for eval, unlikely at initial fab per original scope) *and* a 3.5mm jack for an external HT — not jumper-switched as originally planned, but via a jack with two independent normally-closed switch contacts that mechanically disconnect the SA818S's audio and PTT feeds the instant something is plugged in (see `audio_ptt_path.md` § 2 for the real K1-pinout-informed plan; PCM5102A + attenuator are placed in `audio.kicad_sch`, the jack itself is not yet sourced).

## Storage — SD card + EEPROM

- **SD card: SPI mode — implemented.** Not SDIO. No audio *recording* planned, and audio *playback* (voice IDs, custom clips) is a light, bufferable workload (~32KB/s for 16kHz/16-bit mono) well within SPI-mode throughput — SDIO's speed and extra GPIO cost isn't needed.
- **Connector: Molex 472192001** (LCSC `C164170`, ref `Card1` on `mcu-esp32.kicad_sch`) — flip-top/hinged microSD socket, 8-pin SMD, no card-detect pin, 1.9mm height above board, ~13.7k units in stock. Hinged style over push-push specifically requested — easier to swap cards during bench bring-up than a push-push socket's insert-to-eject action.
- **Wiring**: SPI2 (`FSPI`) peripheral, matching this project's IO-matrix pin plan — IO10 (`FSPICS0`) → `CD/DAT3` (CS), IO11 (`FSPID`) → `CMD` (MOSI/DI), IO12 (`FSPICLK`) → `CLK` (SCLK), IO13 (`FSPIQ`) → `DAT0` (MISO/DO). `DAT1`/`DAT2` correctly left unconnected (SD-native-mode-only signals, unused in SPI mode). Shield/mounting tabs (pins 9-12, renamed `SHLD` in the symbol) tied to GND for EMI shielding — the part is explicitly a *shielded* connector, so these are a real shield-ground connection, not inert mechanical pads. Local 0.1µF decoupling cap (C53) on VDD.
- **Open item**: no pull-up on the CS (`CD/DAT3`) line yet. Espressif's own SD pull-up requirements doc specifies 10kΩ on CMD/DAT0-3 for SPI mode — matches every other control-line pull-up already used on this board (I2C, PCA9555 INT, auto-reset network, RTC INT all use 10kΩ). Not strictly required since this SPI bus isn't shared with any other device, but recommended before final layout.
- **Config storage: I2C EEPROM — implemented.** onsemi **CAT24C32YI-GT3** (32Kbit, TSSOP-8, LCSC `C94264`), address pins grounded → `0x50`, placed on the `Peripherals` sheet (U16) with its own local 0.1µF decoupling cap. Picked over the originally-named Microchip AT24C32D-SSHM-T during layout — both are genuine drop-ins on the industry-standard 24Cxx pinout (see `ic_inventory.md`), this was just the one sourced. WP is wired to a solder jumper (open by default, floating → internal pull-down → write-protect disabled; bridge it to +3.3V to hardware-lock the EEPROM) rather than hard-tied, matching this board's bench-testable jumper-isolation convention. Not FRAM — FRAM (FM24C/MB85RC families) isn't available in JLCPCB's catalog, and EEPROM's ~1M write-cycle life is a non-issue for settings that change occasionally (schedule, frequency, TX power, tone), not continuously. Lives on the same I2C bus as the RTC/fuel-gauge, independent of the SD card, so critical operating parameters survive a missing/corrupt card.

## Onboard charging — none; USB powers logic only, via an isolated path

**No battery charging.** Investigated: TI **BQ25792** (I2C-configurable 1-4S buck-boost charger, in stock at JLCPCB) can charge the 2S1P pack directly from 5V USB without PD negotiation (internally boosts as needed) — a real, buildable option, not ruled out for cost/feasibility reasons. Decided against it for this revision anyway; charging stays external/separate as originally designed.

**USB VBUS is not left electrically dangling, though** — every USB connection carries 5V on VBUS regardless of intent, and if that were wired straight into the 3.3V rail or VRAW it would fight the battery-derived supply whenever both are present (e.g. flashing firmware on a board that's already powered — a completely normal case for a board that'll be reflashed constantly during bring-up). So there's a small dedicated path: **VBUS → a 3.3V LDO (TI LM1117IMPX-3.3/NOPB, the part now used for both the main and USB-side 3.3V rails — swapped from the originally-placed AMS1117-3.3, see `ic_inventory.md`) → a Schottky diode → the shared 3.3V rail.** The main regulation's 3.3V LDO output connects to that same shared rail directly, with no diode in series — asymmetric on purpose. If it had a diode too, the main rail would drop by the diode's forward voltage during *every* normal battery-powered run, not just when USB is present. With the diode only on the USB leg: whenever battery power is present, the main regulator's tightly-regulated output sits at or above the USB-LDO's output, which naturally reverse-biases (blocks) the USB diode with no active switching needed — no backfeed, full clean 3.3V preserved. When only USB is present (no battery), the diode conducts and the USB-LDO supplies the rail. This lets the board be flashed/debugged from USB alone on the bench with no battery connected, without any risk when both sources are live at once. Sized for logic-only loads (MCU + peripherals) — not intended to power the SA818S PA at TX current.

## RF power sensing — forward power only, dual-path (ADC + comparator)

Simple diode detector on the antenna line, forward power only (no reflected/SWR) for this revision. The detector's output feeds two parallel paths rather than just an ADC:

- **ADC1 (IO4)** — actual power-level readback, for calibration/verification of "variable TX power" (otherwise the PWM-based power setting is open-loop and unverified). Deliberately ADC1, not ADC2 — ADC2 is unreliable while WiFi is active.
- **Comparator (e.g. LM393-class) → digital GPIO (IO41)** — a fast, software-independent fault flag ("near-zero power leaving, probably an open/damaged antenna"). Reference threshold set via a resistor divider off 3.3V (exact values TBD during detector circuit design). Added specifically because a comparator's digital HIGH/LOW is far more noise-immune near an active RF PA than trying to resolve a precise analog level — the ADC path stays for the number you actually want (power level), the comparator adds a robust independent trip you can trust without relying on ADC averaging/timing.

This is the same pattern used in commercial RF gear: fast comparator trip for fault/protection, slower ADC readout for the calibrated value.

## Status indication

**Hardware debug LEDs** (footprints reserved, DNP by default — populate only for bench bring-up) at key power-section nodes: battery-protected output (`PWR_18650`), `+12V` (post-fuse), `PWR_IN_SELECT` (post-ORing), `5V_BUCK_OUT`, `3V3_BUCK_OUT`. **Exception:** the final `+3.3V` rail LED is hard-populated (always on) — it's the one purely passive "logic power present" indicator, since no MCU-driven LED can report anything if 3.3V never came up in the first place.

**MCU-driven status LEDs:** a dedicated TX-active LED (not folded into a color code — RF safety/awareness deserves an unambiguous indicator), a dedicated heartbeat LED (brief periodic blink, not solid, to confirm firmware is running without a continuous-draw cost), and one RGB/WS2812 LED encoding GPS search/lock, fault conditions (battery critical, antenna fault, SD error), and found-log mode active (WiFi/BLE on).

**I2C GPIO expander — implemented, but as a general-purpose expansion block, not a dedicated LED driver.** TI **PCA9555PWR** (U15, TSSOP-24, address pins grounded → `0x20`) is placed on the `Peripherals` sheet with its own `INT` output wired to the MCU (IO39, see `esp32s3_pinout.md`) so firmware can be notified on any input change instead of polling. What's actually behind it right now: 4 general-purpose LEDs (green/red/blue/yellow, real Vf-matched series resistors, see below) and 8 general-purpose switch inputs (a 4-position onboard DIP switch + 4 onboard pushbuttons + 4 external JST breakouts with pull-ups) — none of the 8 output or 8 input lines are wired to a specific "TX-active"/"heartbeat" role in the schematic; that assignment is now a firmware/config decision rather than a hardware one. This is what freed IO3 back to spare in `esp32s3_pinout.md` (IO39 itself is used by the expander's `INT`, not freed).

**RGB/WS2812 status LED — implemented.** D4, Worldsemi **WS2812B-B/W** (SMD5050-4P, LCSC `C114586`), on its own native GPIO (IO40/pin 33) rather than behind the expander — it needs a real serial protocol with strict bit timing (RMT peripheral), which a static-register expander can't produce. `DIN` wired to IO40; `DOUT` explicitly no-connect flagged since it's the only LED in the chain (safe to leave floating per the part's own datasheet — nothing downstream to feed). Local 0.1µF bypass cap (C52) at VDD/VSS.

## TX safety — watchdog + independent hardware PTT timeout

ESP32-S3's internal watchdog timers cover general firmware-hang protection — no separate general-purpose supervisor IC needed. **But** a stuck-transmitter fault (firmware hang *or* a logic bug that keeps PTT asserted while the CPU is otherwise fine) needs its own independent layer, since an MCU reset doesn't guarantee the PTT line de-asserts, and a pure software watchdog can't catch "firmware is running but wrongly still keying."

- **PTT line defaults to released** whenever its driving GPIO is undriven/in reset (pull resistor sized accordingly), so a reset transient can't leave the radio keyed.
- **Independent hardware TX-timeout:** a 74HC123 dual retriggerable monostable (RC-timed for a **2-minute hard ceiling**) gates the PTT line in series with the MCU's own PTT-intent GPIO. The MCU must periodically retrigger it during a legitimate transmission; if it stops (hang or logic bug), the 74HC123's timeout forces PTT release after 2 minutes regardless of MCU state — independent of whether the MCU's own watchdog even fires.

## Frequency / tone plan

Arbitrary **frequency register** (not a fixed channel list) — matches the "flexible and dynamic" goal. CTCSS/DCS tone supported by default, including **randomizing tone within a valid range** between transmission cycles. Both are SA818S UART commands (`AT+DMOSETGROUP` et al.) — zero hardware impact, pure firmware/config-data-model concerns (same EEPROM config bucket as storage, above).

## LoRa / remote telemetry — skipped

Considered for knowing the fox is still alive without physically visiting it, but skipped entirely for this revision (no reserved footprint) — not useful without a receiver/backbone plan (e.g. Meshtastic) already in place, which doesn't exist yet. Revisit if that infrastructure materializes.

## Board / enclosure

No size constraint for this revision — bare board, no enclosure, decided during layout. GPS antenna is external via SMA (see GPS section above); SA818S antenna presumably SMA as well (TBD at layout).

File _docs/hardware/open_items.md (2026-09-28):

# Open Items / Next Steps

- [ ] Populate downstream loads (SA818S, ESP32-S3, GPS) and re-verify rail current budgets against real hardware.
- [ ] First board bring-up: isolate each stage via the power-section jumpers, verify independently, then re-bridge for full-system test.

- [ ] Once the controller section has real current draws, re-verify the existing 5V/2A and 3.3V/1A [regulation](regulation.md) budget still covers it.

- [ ] Firmware for hold-to-power-off — poll GPIO38, time the hold, release GPIO48 when the threshold is met. Nothing here is schematic work; this is a firmware dependency on the hardware above.
- [ ] Firmware-independent hardware force-off — still open, no hardware built yet. If firmware hangs while GPIO48 is asserted, nothing currently overrides it. Leading option: reuse the *spare half* of the 74HC123 dual monostable already planned for TX-safety timeout (§ TX safety in `controller_platform.md`), triggered directly by SW3 (or its isolated `POWER_PB_SIGNAL` node), RC-timed longer than the software hold threshold — zero added GPIO, and the 74HC123 isn't placed in the schematic yet either way. Next thing being worked on.

See also: [`_docs/sourcing/task1_lcsc_crossreference.md`](../sourcing/task1_lcsc_crossreference.md) for the BOM-verification checklist (blank Value fields, footprint/manufacturer mismatches, missing LCSC data, and the per-sheet capacitor-voltage-is-a-minimum documentation task).

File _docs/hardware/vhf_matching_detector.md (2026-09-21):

# VHF Antenna Matching Network & RF Forward-Power Detector — Parts & Layout

Covers two RF circuits that sit between the SA818S-V (`U19`) and the antenna SMA
connector (`J10`-style, Amphenol 132289): the **7-element low-pass matching network**
(topology borrowed from the open-source [KV4P-HT v2.0e](https://github.com/VanceVagell/kv4p-ht)
reference design) and the **diode-detector forward-power sensing tap** feeding
`esp32s3_pinout.md`'s `IO4` (ADC) / `IO41` (comparator fault flag) pair, per
`controller_platform.md` § RF power sensing. Neither circuit is in the schematic yet —
this is the sourcing/topology plan for the next placement pass.

**Rigor note, read before ordering:** both circuits have values that are *starting
points*, not final — the matching network's element values come from a reference
design at a different board's layout/stray capacitance, and the detector's coupling
ratio depends on parasitics that only a real bench measurement will pin down. Treat
every value here as "populate this, then verify/tune on the bench," the same way this
project's mic-level attenuator trimmer (`audio_ptt_path.md`) needed a real deviation
measurement before the calculated nominal was trusted.

**Package size: 0805 throughout, with one deliberate exception.** Bench tuning means
repeated hand rework, so everything below is spec'd in 0805 rather than 0402 for
easier soldering/swapping. At 145MHz (λ ≈ 2.07m) an 0805 footprint is still a tiny
fraction of a wavelength, so this doesn't introduce a meaningful parasitic penalty —
ESL/ESR/SRF differences between 0402 and 0805 at this frequency are noise next to the
tolerances this whole design already assumes need bench tuning. **The one exception:
`C_couple` (1pF) in the detector circuit stays at 0402.** It's deliberately a tiny
value to set the RF sample ratio, and an 0805 pad's own parasitic capacitance-to-ground
is large enough *relative to 1pF* to meaningfully shift that ratio — the one part here
where package size is a real, not just theoretical, concern.

## 1. VHF matching network — SA818S `ANT` → `J10` (SMA)

7-element LC low-pass ladder, 4 shunt capacitors + 3 series inductors, tuned for
145MHz (2m VHF). Topology and starting values carried over from KV4P-HT v2.0e's own
antenna output stage (a real, fielded ESP32+SA818/DRA818 design), rendered and
inspected directly from its schematic earlier this project.

```
 U19            C1        L1        C2        L2        C3        L3        C4        J10
 ANT  o──────────┬────///────┬────///────┬────///────┬────///────┬──────────────o SMA (50Ω)
                 │    27nH   │    30nH   │    43nH*   │           │
               ──┴──       ──┴──       ──┴──       ──┴──         │
               10pF        18pF        16pF        5.1pF         │
                 │           │           │           │           │
                GND         GND         GND         GND         GND
```

*(ladder read left→right: shunt C1, series L1, shunt C2, series L2, shunt C3,
series L3, shunt C4 — 4 shunt + 3 series = 7 elements)*

| Ref (proposed) | Function | Value | MPN | Package | LCSC | Stock | Notes |
|---|---|---|---|---|---|---|---|
| C1 | Shunt | 10pF | YAGEO CC0805JRNPO9BN100 | 0805, C0G/NP0, 50V | `C107107` | 515,400 | Verified in stock. |
| L1 | Series | 27nH | Murata LQW2BAS-class (0805) | 0805, wirewound, ±5% | *unconfirmed* | — | Murata's `LQW2BAS`/`LQW2BH` 0805 wirewound families cover this value (2.7–820nH range, real product lines) — **exact LCSC C-number for the 27nH variant not confirmed this pass**; search LCSC directly before ordering. |
| C2 | Shunt | 18pF | YAGEO CC0805JRNPO9BN180 | 0805, C0G/NP0, 50V | *unconfirmed* | — | Real Yageo catalog part (multiple distributors confirm it) — **LCSC C-number not confirmed this pass**. |
| L2 | Series | 30nH | Murata LQW2BH-class (0805) | 0805, wirewound, ±5% | *unconfirmed* | — | Same family as L1 — value is within Murata's real 0805 product range, C-number not confirmed this pass. |
| C3 | Shunt | 16pF | YAGEO CC0805JRNPO9BN160 | 0805, C0G/NP0, 50V | *unconfirmed* | — | Real Yageo catalog part — **LCSC C-number not confirmed this pass**; search LCSC directly for `CC0805JRNPO9BN160`. |
| L3 | Series | 43nH* | *(no direct LCSC match found)* | 0805 | — | See note below — recommend substituting **47nH** (below) unless exact 43nH is bench-confirmed necessary. |
| C4 | Shunt | 5.1pF | YAGEO CC0805-class NP0 | 0805, C0G/NP0, 50V | *unconfirmed* | — | Real Yageo value/series — **LCSC C-number not confirmed this pass**. |

**L3 (43nH) substitution note:** no genuine 43nH chip inductor (0402 or 0805) turned up
on LCSC this pass. Coilcraft makes real, purpose-built high-Q parts at exactly 43nH
(`0402CS-43N`, `0402DC-43N`, `0402HP-43N`, and 0805-class equivalents) but Coilcraft
isn't an LCSC-stocked brand — sourcing those means going outside the normal JLCPCB
assembly flow, the same category as the SA818S-V module itself (`ic_inventory.md`'s
"DNP — sourced outside LCSC"). The practical alternative: **Murata LQW15AN47NJ00D**
(47nH, ±5%, 0402, LCSC `C192855`, in stock) is a real, in-stock, confirmed substitute —
about 9% off the reference design's 43nH, well within what a network that already needs
bench retuning can absorb. **This one is worth keeping at 0402** rather than chasing an
unconfirmed 0805 47nH part, since it's the one inductor position with a fully verified
LCSC listing already — a bench-tuning board can mix package sizes on a single part
without issue; populate 47nH unless the bench tuning pass specifically calls for the
exact reference value.

**Inductor sourcing gap, general note:** unlike the caps (Yageo's catalog is
comprehensive and every value above is a genuine, if not always LCSC-confirmed, part),
0805 RF inductors at these exact odd values (27nH, 30nH) didn't turn up specific LCSC
C-numbers this pass, only confirmation that Murata's real 0805 wirewound families cover
the range. Confirm exact part numbers on LCSC directly before ordering, or keep L1/L2 at
their already-fully-verified 0402 listings (`C113112`, `C329622` from the original pass)
if the 0805 lookup doesn't pan out — same "mixed package sizes are fine" reasoning as L3.

## 2. RF forward-power detector — tap after the matching network

Simple diode envelope detector, forward-power only (no reflected/SWR), per
`controller_platform.md`. Taps the antenna line *after* C4/L3 (closer to the actual
radiated signal than the SA818's raw unfiltered PA output), rectifies a small sampled
fraction into a DC level, and feeds both the ADC readback (`IO4`) and the comparator
fault flag (`IO41`, via `U`-tbd LM393).

```
                    C_couple                                    R_load      C_filter
 (after C4/L3) o──────||──────┬── R_series ──▶|── D1 ──┬───────/\/\/\──┬──────||──────┐
   ANT node         1pF       │      470Ω    (anode)   │      100kΩ    │    1nF       │
                               │                        │               │              │
                            C_shunt                     └── detector DC node ─────────┤
                             100pF                            │              │        │
                               │                               ▼              ▼        │
                              GND                         → IO4 (ADC1)   → LM393 (+)  GND
                                                                            │
                                                                     LM393 (−) ← 3.3V ÷ R_ref1/R_ref2
                                                                            │
                                                                            ▼
                                                                     → IO41 (digital fault flag)
```

| Ref (proposed) | Function | Value | MPN | Package | LCSC | Stock | Notes |
|---|---|---|---|---|---|---|---|
| C_couple | RF sample tap (series) | 1pF | YAGEO CC0402CRNPO9BN1R0 | **0402** (kept small — see note above), C0G/NP0, 50V, ±0.25pF | *unconfirmed* | — | Real Yageo part (Farnell/DigiKey/Mouser/RS all list it) — **LCSC C-number not confirmed this pass**; verify directly on LCSC before ordering. **Deliberately not respec'd to 0805** — see the package-size note at the top of this doc. |
| C_shunt | Divider reference (shunt) | 100pF | YAGEO CC0805JRNPO9BN101 | 0805, C0G/NP0, 50V | `C62768` | 630,100 | Sets the coupling ratio with `C_couple` (~1:100, ≈ -40dB) — **starting point only, needs bench tuning** against real measured TX power. |
| R_series | Diode protection/linearization | 470Ω | YAGEO RC0805FR-07470RL | 0805, thick film, ±1% | `C114564` | Verified listed | Same standard 470Ω already used elsewhere on this board (`R47`/`R48`, DAC output filters, though those are likely 0603 — reuse whatever MPN those turn out to already be sourced as, for consistency, if it matters more than the package-size goal here). |
| D1 | Envelope rectifier | — | High Diode BAT54 (or PC817C-S-class Schottky, single) | SOT-23 (discrete diode — package respec doesn't apply the same way) | `C466635` | 2,000 | Small-signal Schottky, not a specialized zero-bias RF part — deliberate: this circuit samples watts of real TX power, not microwatts, so a general-purpose Schottky (fast, low Vf) is the right fit, not an RFID-grade `HSMS-2850` (not LCSC-stocked anyway, and rated for signals far weaker than what's available here). Modest LCSC stock — confirm at build time. |
| R_load | Detector bleed/load | 100kΩ | YAGEO RC0805FR-07100KL | 0805, thick film, ±1% | `C96346` | 787,600 | Sets the RC decay time with `C_filter`. |
| C_filter | Envelope/lowpass filter | 1nF | YAGEO CC0805JRX7R9BB102 | 0805, X7R, 50V | `C277515` (unconfirmed vs. alt listing) | ~2,700 | Modest stock for an X7R part at this common value — worth double-checking at build time. X7R is fine here (this cap is doing DC/envelope filtering, not RF-critical), no need for the NP0 precision the matching network caps want. |
| R_ref1, R_ref2 | Comparator threshold divider | 10kΩ / 10kΩ (start) | YAGEO RC0805FR-0710KL | 0805, thick film, ±1% | `C84376` | Verified listed | Symmetric divider gives a ~1.65V starting threshold off `+3.3V` — **exact trip point is a bench-tuning decision** (per `controller_platform.md`, "exact values TBD during detector circuit design"), not a calculated final value. May end up asymmetric once a real "antenna disconnected" DC level is measured. |
| U (comparator) | Fault-flag comparator | — | onsemi LM393DR2G | SOIC-8 (IC — package respec doesn't apply) | `C7955` | 209,190 | Already the project's selected part for this role — see `ic_inventory.md` § Forward-Power Fault Comparator. Open-drain output needs its own pull-up to `+3.3V` before `IO41`. |

**Optional protection**, not yet in the table above: a small clamp (zener or resistor
sized to limit worst-case voltage) at the `IO4` ADC tap, cheap insurance against an
under-tuned coupling ratio overdriving the ESP32-S3's ADC input during bring-up —
worth adding once the divider's real DC output range is bench-measured.

## 3. Open items

- [ ] Confirm LCSC C-numbers for the 0805 caps flagged `*unconfirmed*` above (`C1`
  10pF's 0805 variant is confirmed; `C2` 18pF, `C3` 16pF, `C4` 5.1pF, and `C_couple`'s
  0402 part are real Yageo catalog parts but not confirmed against LCSC's own listing
  this pass) and for `L1`/`L2`'s 0805 Murata inductors — search LCSC directly rather
  than trusting an assumed number.
- [ ] Decide on `L3`: populate the confirmed 47nH substitute (`C192855`, 0402) or source
  genuine 43nH (Coilcraft, outside LCSC) — bench tuning may make this moot either way.
  This one's deliberately staying 0402 since it's the fully-verified listing.
- [ ] Bench-tune the actual matching network once populated (real VNA/return-loss
  measurement, not just the calculated ladder) — same caveat KV4P-HT's own design
  would have needed on a different board.
- [ ] Bench-tune the detector's coupling ratio (`C_couple`/`C_shunt`) and comparator
  threshold (`R_ref1`/`R_ref2`) against real measured TX power once both circuits are
  populated — this doc's values are calculated starting points, not final.
- [ ] Confirm `R47`/`R48`'s actual sourced 470Ω MPN (`audio_ptt_path.md`) and reuse it
  for `R_series` here if different from `RC0603JR-07470RL`, to avoid two part numbers
  for the same standard value on one board.

## 4. Reference documents

- [`controller_platform.md`](controller_platform.md) § RF power sensing — the
  ADC/comparator dual-path design this detector feeds.
- [`sa818_pinout.md`](sa818_pinout.md) — `ANT` pin, and the shared Amphenol 132289
  SMA connector choice.
- [`esp32s3_pinout.md`](esp32s3_pinout.md) — `IO4` (ADC1_CH3) and `IO41` (MTDI) pin
  assignments.
- [`ic_inventory.md`](ic_inventory.md) § Forward-Power Fault Comparator — `LM393DR2G`
  sourcing detail.
- [KV4P-HT v2.0e](https://github.com/VanceVagell/kv4p-ht) — real, fielded open-source
  ESP32+SA818/DRA818 project this matching network's topology and starting values are
  drawn from.

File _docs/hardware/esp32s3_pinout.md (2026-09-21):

# ESP32-S3-WROOM-1-N8R8 — Pinout & Interconnect Plan

Source: Espressif *ESP32-S3-WROOM-1 & WROOM-1U* datasheet v1.3 (pulled directly from the
module's LCSC-hosted datasheet PDF, not from memory — pin numbers/alt-functions below are
transcribed from the datasheet's own pin table).

**Module variant note:** our pick is the **R8** PSRAM variant (8MB Octal SPI PSRAM,
integrated in-module). On R8/R16V variants, **pins 28–30 (IO35/IO36/IO37) are internally
wired to that PSRAM and are not available for any other use** — they don't appear as
routable nets in the interconnect table below. This is easy to miss and would have been a
real problem if assigned to something.

## 1. Full reference pin table (as datasheet)

| Pin # | Name | Type | Datasheet alt-functions |
|---|---|---|---|
| 1 | GND | P | Ground |
| 2 | 3V3 | P | Supply |
| 3 | EN | I | Chip enable/reset (active high). Must not float. |
| 4 | IO4 | I/O/T | RTC_GPIO4, GPIO4, TOUCH4, ADC1_CH3 |
| 5 | IO5 | I/O/T | RTC_GPIO5, GPIO5, TOUCH5, ADC1_CH4 |
| 6 | IO6 | I/O/T | RTC_GPIO6, GPIO6, TOUCH6, ADC1_CH5 |
| 7 | IO7 | I/O/T | RTC_GPIO7, GPIO7, TOUCH7, ADC1_CH6 |
| 8 | IO15 | I/O/T | RTC_GPIO15, GPIO15, U0RTS, ADC2_CH4, XTAL_32K_P |
| 9 | IO16 | I/O/T | RTC_GPIO16, GPIO16, U0CTS, ADC2_CH5, XTAL_32K_N |
| 10 | IO17 | I/O/T | RTC_GPIO17, GPIO17, U1TXD, ADC2_CH6 |
| 11 | IO18 | I/O/T | RTC_GPIO18, GPIO18, U1RXD, ADC2_CH7, CLK_OUT3 |
| 12 | IO8 | I/O/T | RTC_GPIO8, GPIO8, TOUCH8, ADC1_CH7, SUBSPICS1 |
| 13 | IO19 | I/O/T | RTC_GPIO19, GPIO19, U1RTS, ADC2_CH8, CLK_OUT2, **USB_D-** |
| 14 | IO20 | I/O/T | RTC_GPIO20, GPIO20, U1CTS, ADC2_CH9, CLK_OUT1, **USB_D+** |
| 15 | IO3 | I/O/T | RTC_GPIO3, GPIO3, TOUCH3, ADC1_CH2 — **strapping: JTAG source** (default floating) |
| 16 | IO46 | I/O/T | GPIO46 — **strapping: boot mode / ROM log** (default pull-down) |
| 17 | IO9 | I/O/T | RTC_GPIO9, GPIO9, TOUCH9, ADC1_CH8, FSPIHD, SUBSPIHD |
| 18 | IO10 | I/O/T | RTC_GPIO10, GPIO10, TOUCH10, ADC1_CH9, FSPICS0, FSPIIO4, SUBSPICS0 |
| 19 | IO11 | I/O/T | RTC_GPIO11, GPIO11, TOUCH11, ADC2_CH0, FSPID, FSPIIO5, SUBSPID |
| 20 | IO12 | I/O/T | RTC_GPIO12, GPIO12, TOUCH12, ADC2_CH1, FSPICLK, FSPIIO6, SUBSPICLK |
| 21 | IO13 | I/O/T | RTC_GPIO13, GPIO13, TOUCH13, ADC2_CH2, FSPIQ, FSPIIO7, SUBSPIQ |
| 22 | IO14 | I/O/T | RTC_GPIO14, GPIO14, TOUCH14, ADC2_CH3, FSPIWP, FSPIDQS, SUBSPIWP |
| 23 | IO21 | I/O/T | RTC_GPIO21, GPIO21 |
| 24 | IO47 | I/O/T | SPICLK_P_DIFF, GPIO47, SUBSPICLK_P_DIFF |
| 25 | IO48 | I/O/T | SPICLK_N_DIFF, GPIO48, SUBSPICLK_N_DIFF |
| 26 | IO45 | I/O/T | GPIO45 — **strapping: VDD_SPI voltage** (default pull-down) |
| 27 | IO0 | I/O/T | RTC_GPIO0, GPIO0 — **strapping: boot mode** (default pull-up) |
| 28 | IO35 | I/O/T | **NOT AVAILABLE — internal Octal PSRAM (R8 module)** |
| 29 | IO36 | I/O/T | **NOT AVAILABLE — internal Octal PSRAM (R8 module)** |
| 30 | IO37 | I/O/T | **NOT AVAILABLE — internal Octal PSRAM (R8 module)** |
| 31 | IO38 | I/O/T | GPIO38, FSPIWP, SUBSPIWP |
| 32 | IO39 | I/O/T | MTCK, GPIO39, CLK_OUT3, SUBSPICS1 |
| 33 | IO40 | I/O/T | MTDO, GPIO40, CLK_OUT2 |
| 34 | IO41 | I/O/T | MTDI, GPIO41, CLK_OUT1 |
| 35 | IO42 | I/O/T | MTMS, GPIO42 |
| 36 | RXD0 | I/O/T | U0RXD, GPIO44, CLK_OUT2 |
| 37 | TXD0 | I/O/T | U0TXD, GPIO43, CLK_OUT1 |
| 38 | IO2 | I/O/T | RTC_GPIO2, GPIO2, TOUCH2, ADC1_CH1 |
| 39 | IO1 | I/O/T | RTC_GPIO1, GPIO1, TOUCH1, ADC1_CH0 |
| 40 | GND | P | Ground |
| 41 | EPAD | P | Ground (exposed thermal pad) |

Strapping pins (GPIO0, GPIO3, GPIO45, GPIO46) latch their value at reset and behave as
normal GPIO afterward — avoid strong external pulls on these unless deliberately changing
boot behavior.

## 2. Proposed interconnect assignment

Note on flexibility: except for **USB D+/D-** (hard-wired to IO19/IO20 on this chip) and the
UART0/strapping pins noted above, nearly everything below is GPIO-matrix-assignable —
these are *my proposed* pin choices for layout tidiness (grouping related signals,
matching datasheet alt-function labels where convenient, e.g. SD card on the FSPI-labeled
pins), not silicon requirements. Easy to reshuffle.

**Wired column (far right)** — cross-checked directly against the live `.kicad_sch` files
(pin-level net trace, not assumed from this table), not just this doc's own stated intent.

| Symbol | Meaning |
|---|---|
| ✅ | Wired — pin already lands on a real net in the schematic today |
| *(blank)* | Planned — signal/subsystem doesn't exist in the schematic yet; this doc's assignment is a reservation, not a fact about current hardware |
| ❓ | Not yet assigned — genuinely spare, no purpose decided |
| ❌ | Do not connect — strapping pin or internally-reserved pin that must stay floating/unavailable, not a candidate for wiring |

| Pin # | Signal | Connects to | Notes | Wired |
|---|---|---|---|---|
| 1 | GND | Ground plane | | ✅ |
| 2 | 3V3 | `+3.3V` rail | | ✅ |
| 3 | EN | Reset circuit: 10kΩ pull-up to 3V3 + 1µF to GND (power-on delay) + manual RESET button to GND + auto-reset transistor from the USB-UART bridge's DTR line (§ MCU in controller_platform.md) | Standard practice | ✅ |
| 4 | IO4 | Forward-power detector output (ADC, level readback) | **ADC1** channel — deliberately not ADC2; ADC2 is unreliable while WiFi is active. Paired with a comparator fault-flag on IO41 (pin 34) — see §4.8 in README for the dual-path design | |
| 5 | IO5 | GPS PPS input | Interrupt-capable, precise edge capture. `GPS_1PPS_IN`, confirmed wired to `U18` TIMEPULSE. | ✅ |
| 6 | IO6 | SA818S UART — MCU TX → SA818 RXD | UART2 (software-assigned). Verified correct crossover against the live schematic. | ✅ |
| 7 | IO7 | SA818S UART — MCU RX ← SA818 TXD | UART2 (software-assigned). Verified correct crossover against the live schematic. | ✅ |
| 8 | IO15 | *Spare (freed)* | Was planned as one leg of a PTT AND-gate (with a 74HC123 timeout output on IO16) — that scheme wasn't what got built. See pin 9: PTT ended up as a single direct GPIO into a FET, no second GPIO needed for now. Genuinely spare again until the TX-safety-timeout stage is actually designed. | ❓ |
| 9 | IO16 | SA818S/HT PTT-intent (MCU output) | Drives `Q10` (BSS138) gate directly — a simple low-side FET switch, not the AND-gate/74HC123 scheme originally planned here. `Q10`'s drain feeds the switched-jack circuit (`J11`) that auto-routes PTT to either the onboard SA818S or an external HT — see `audio_ptt_path.md` and `sa818_pinout.md`. TX-safety timeout (74HC123) is still a separate, not-yet-built stage; when added, it'll gate somewhere in this same path rather than needing a second GPIO here. | ✅ |
| 10 | IO17 (U1TXD) | GPS module RXD | UART1, matches datasheet's own U1TXD label. `MCU_GPS_TXD`, verified correct crossover into `U18` RXD. | ✅ |
| 11 | IO18 (U1RXD) | GPS module TXD | UART1. `MCU_GPS_RXD`, verified correct crossover from `U18` TXD. | ✅ |
| 12 | IO8 | I2C SDA | Shared bus: PCF8563 RTC (`0x51`), MAX17320 fuel gauge (`0x36` main / `0x0B` NVM), CAT24C32YI-GT3 EEPROM (`0x50`), and PCA9555PWR I2C GPIO expander (`0x20`) — all four placed and wired | ✅ |
| 13 | IO19 | **USB_D-** | Native USB, fixed pin | ✅ |
| 14 | IO20 | **USB_D+** | Native USB, fixed pin | ✅ |
| 15 | IO3 | I2S DAC `XSMT` mute control | Was TX-active LED, then freed (moved to the I2C GPIO expander), now spent on the audio circuit's XSMT net (`I2C_MUTE_XSMT`) — the board's last genuinely-spare pin, now used up. **Strapping pin (JTAG source, default floating)** — the audio sheet has a 10kΩ pull-up to `+3.3V` on this net (R46); worth double-checking against Espressif's own strapping table that a weak pull-up in this direction doesn't select a non-default JTAG-source state at boot, before this is relied on. | ✅ |
| 16 | IO46 | **Reserved / NC** | Strapping pin (boot mode + ROM log), leave floating for default boot behavior | ❌ |
| 17 | IO9 | I2C SCL | Shared bus, see pin 12 | ✅ |
| 18 | IO10 (FSPICS0) | SD card CS (`Card1` pin 2, `CD/DAT3`) | No CS pull-up yet — see `open_items.md`, recommend 10kΩ to `+3.3V` per Espressif's SD pull-up spec | ✅ |
| 19 | IO11 (FSPID) | SD card MOSI/DI (`Card1` pin 3, `CMD`) | `FSPID` = data-out-from-host per ESP32's SPI-flash-derived naming (D=MOSI, Q=MISO) — not obvious from the datasheet's own pin table | ✅ |
| 20 | IO12 (FSPICLK) | SD card SCLK (`Card1` pin 5, `CLK`) | | ✅ |
| 21 | IO13 (FSPIQ) | SD card MISO/DO (`Card1` pin 7, `DAT0`) | `DAT1`/`DAT2` (native-mode-only signals) correctly left unconnected — SPI mode doesn't use them | ✅ |
| 22 | IO14 | I2S BCLK → audio DAC | DAC is `U17` (PCM5102A), placed in `audio.kicad_sch`. `I2S_BCK`, confirmed wired. | ✅ |
| 23 | IO21 | I2S LRCLK/WS → audio DAC | `I2S_LRCK`, confirmed wired. | ✅ |
| 24 | IO47 | I2S DOUT → audio DAC | `I2S_DIN`, confirmed wired. No MCLK pin needed — PCM5102A runs its internal PLL off `SCK` tied low (see judgment call #2). | ✅ |
| 25 | IO48 | Power-latch hold (MCU output, open-drain) | Diode-ORed with button + PCF8563 INT at the soft-latch enable node (§4.1) | ✅ |
| 26 | IO45 | **Reserved / NC** | Strapping pin (VDD_SPI voltage), leave floating for default (3.3V) behavior | ❌ |
| 27 | IO0 | BOOT button (pull to GND) + auto-reset transistor from the USB-UART bridge's RTS line | Strapping pin (boot mode). Manual BOOT+RESET buttons stay as the fallback when the bridge isn't plugged in; the bridge's RTS/DTR pair drives the standard two-transistor auto-reset circuit for one-command `esptool`/PlatformIO uploads | ✅ |
| 28 | IO35 | — | Not available (internal PSRAM) | ❌ |
| 29 | IO36 | — | Not available (internal PSRAM) | ❌ |
| 30 | IO37 | — | Not available (internal PSRAM) | ❌ |
| 31 | IO38 | Hold-to-power-off detect (input, active-high) | Not a second switch pole — SW3 stays a plain SPST button. Its own node (`POWER_PB_SIGNAL`) is isolated from the shared wake node via R45 (1MΩ pull-up) + D5 (diode-OR back into `PWR_LATCH`), then level-shifted through Q9 (BSS138) into this pin (R44, 10k pull-up) — see § Power sequencing in controller_platform.md. Firmware still needs to poll and time the hold; a firmware-independent hardware force-off is still open (see `open_items.md`) | ✅ |
| 32 | IO39 (MTCK) | PCA9555 `INT` (`PERIPH_IO_INT`, input) | **Corrects an earlier version of this doc**, which called this pin spare/freed for a heartbeat LED that never materialized — live schematic trace shows it's actually wired to the I2C GPIO expander's own interrupt output, so firmware can be notified on any expander input change (DIP switches, buttons) instead of polling over I2C. No JTAG-header tradeoff either way — ESP32-S3's native USB has a built-in USB Serial/JTAG peripheral, full OpenOCD-compatible debug access over the same USB-C connector | ✅ |
| 33 | IO40 (MTDO) | WS2812/RGB status LED data (MCU output) | D4, Worldsemi WS2812B-B/W. `DIN` wired to this pin; `DOUT` explicitly no-connect flagged (last/only LED in the chain, safe to leave floating per the part's own datasheet convention); local 0.1µF bypass cap (C52) | ✅ |
| 34 | IO41 (MTDI) | Forward-power comparator output (input, digital) | Fault-flag path: same diode detector as IO4, through a comparator (e.g. LM393-class) against a fixed threshold — reliable "antenna fault, near-zero power leaving" detection independent of ADC noise/averaging | |
| 35 | IO42 (MTMS) | `IO_IN_ON_BATT` (input) | Status tap off the TPS2121 rail muxes — tells firmware whether the board is currently running on battery or USB, e.g. to gate whether a power-off attempt should even try (no point releasing the latch while USB keeps the rails up regardless) | ✅ |
| 36 | RXD0 | USB-UART bridge (CH340C) TX → MCU RX | Own USB connector, separate from native USB — see § MCU in controller_platform.md | ✅ |
| 37 | TXD0 | MCU TX → USB-UART bridge RX | | ✅ |
| 38 | IO2 | MAX17320 ALRT (input, interrupt) | | ✅ |
| 39 | IO1 | PCF8563 INT/alarm (input, interrupt) | Separate from that same INT line's direct hardware path into the power-latch wake-OR (§4.1) — MCU also wants to read it directly once awake | ✅ |
| 40 | GND | Ground plane | | ✅ |
| 41 | EPAD | Ground plane | Thermal/ground pad, solder down | ✅ |

## Open judgment calls (flagging, not blocking)

1. **GPS is UART-only** (no I2C) — simpler, and UART is the standard/expected interface for NMEA/UBX streams. Flag if you wanted I2C instead for some reason.
2. **I2S MCLK not reserved** — not needed: the chosen DAC (PCM5102A) runs its internal PLL off `SCK` tied low, no MCLK required from the MCU (see `audio_ptt_path.md` § 1). IO3, the one pin this would have used if a future DAC swap ever needed it, is now spent on XSMT mute control instead (item 6 below) — a future MCLK requirement would need to reclaim a GPIO from an existing assignment.
3. **Resolved: added a second USB connector for a USB-UART bridge** (CH340C, own port, DTR/RTS auto-reset into EN/IO0), instead of relying solely on native-USB auto-reset-into-bootloader — see § MCU in controller_platform.md for why (native-USB CDC re-enumerates on every reset, and its auto-reset has known version-dependent quirks). BOOT/RESET buttons stay regardless, as the fallback when the bridge isn't plugged in.
4. **Partially resolved: an I2C GPIO expander (PCA9555PWR, `0x20`) is now placed and wired** — but its actual role landed differently than originally planned. The LEDs behind it (4x, on `IO1_0`–`IO1_3`) and buttons (4x onboard + 4x external JST breakouts, on `IO0_x`) are wired as **generic-purpose I/O**, not specifically assigned to "TX-active" and "heartbeat" roles in the schematic — that mapping is now a firmware/config decision, not a hardware one. **The WS2812/RGB status LED (pin 33, D4) is now placed and wired** — it needed a real serial protocol with strict bit timing (RMT peripheral), which a static-register expander can't produce, so it stayed on its own native GPIO as planned.
5. **`IO42` was incorrectly listed as spare** in an earlier pass of this doc — it's actually already wired to `IO_IN_ON_BATT`, added after this table was first written and never back-filled here. Caught by cross-checking the live schematic rather than trusting this doc; worth remembering that this table can drift out of sync with the actual `.kicad_sch` files and should be spot-checked, not assumed current.
6. **`IO39` was also incorrectly listed as spare**, same root cause as item 5 — live schematic trace shows it's wired to the PCA9555's own `INT` output (`PERIPH_IO_INT`), not freed for a heartbeat LED (see the pin table, pin 32). `IO3` (pin 15, the GPIO reference here) is spent on the audio circuit's XSMT mute control — but see item 7 below, a different pin also freed back up since this was written.
7. **`IO15` (pin 8) is spare again** — originally reserved for one leg of a PTT AND-gate (paired with a 74HC123 retrigger pulse on `IO16`). The PTT circuit that actually got built is simpler: a single GPIO (`IO16`) drives a FET (`Q10`) directly, no second GPIO involved. `IO15` was never wired to anything, so it's genuinely available — worth keeping in mind for the still-unbuilt TX-safety timeout (74HC123) stage, though that may end up gating the existing PTT path in series rather than needing a dedicated GPIO of its own.
8. **SA818S `PD`/`H-L` control will reuse PCA9555 expander pins, not native ESP32-S3 GPIOs** — decided this session, not yet built in the schematic. Two of the expander's existing JST-connected channels (currently switch inputs) get reconfigured as outputs: `PD` direct (its existing pull-up conveniently defaults it safe), `H-L` through a small N-FET so the GPIO can only pull it low or let it float — never drive it high, per the SA818 datasheet's explicit "cannot connect to VDD or high CMOS output" constraint. See `sa818_pinout.md`. Doesn't consume a native GPIO, so no change to this table's pin count.
9. **GPS hardware backup-mode power gating (VCC/V_IO cutoff via a FET)** — discussed as the recommended way to force `U18` into its true low-power backup mode (vs. software standby), not yet built. Would use a spare GPIO or the PCA9555 expander to drive the gate — if a native GPIO ends up being used instead of the expander, that would consume `IO15`, the one currently-spare pin. Flagging so that's not forgotten if/when this gets implemented.

**Fresh audit this pass** (ERC-verified, not just net-name lookups — several genuinely-wired local nets don't resolve to a name via simple net queries and were double-checked against ERC's actual unconnected-pin list): confirmed exactly **4 unconnected pins** — `IO15` (spare), `IO46` (strapping, intentionally floating), `IO4` and `IO41` (forward-power ADC/comparator pair, still planning-only). Six other rows (`IO5`, `IO17`, `IO18`, `IO14`, `IO21`, `IO47`) had drifted stale — wired in the schematic but still shown blank/planning here — now corrected to ✅.

35 of 36 available GPIOs now assigned a purpose; **`IO15` (pin 8) is the one genuinely spare pin**. Cross-checking the live schematic (not just this doc) shows all but 4 pins are actually wired today — see the **Wired** column in the table above for the pin-by-pin breakdown; `IO4`/`IO41` (forward-power ADC/comparator) remain the only planning-only reservations among the assigned pins. `PD`/`H-L` on the SA818S itself are separate, non-ESP32-S3 pins (see item 8 above).

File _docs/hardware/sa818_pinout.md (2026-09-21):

# SA818S-V — Pinout & Interconnect Plan

Covers the onboard VHF transceiver module (G-NiceRF SA818S-V, `U19`, placed as the
`SA818S-V` sheet — `SA818V.kicad_sch`). Real pin table, from NiceRF's own datasheet
(SA818S Rev 1.3 — see § 3). See `audio_ptt_path.md` for the shared DAC/PTT subsystem this
module is one of two destinations for, and `gps_path.md` for the sibling RF module this
board also carries.

## 1. Full real pin table

| Pin | Name | I/O | Function (per NiceRF's own datasheet) | Planned tie/connection |
|---|---|---|---|---|
| 1 | Audio ON | O | Auto-controls an external audio amp — outputs **low** to enable it, **high** to disable. Active whenever the module is powered, regardless of RX/TX state. | Not used this design — no onboard speaker amp. Leave open. |
| 2 | NC | – | Not connected | Leave open |
| 3 | AF_OUT | O | RX audio out (~700mV typ, 200Ω output impedance per earlier research) | Not routed back into the MCU this pass — no onboard speaker amp/audio-monitoring path chosen yet. Leave open; revisit if RX audio monitoring/recording is ever wanted (flagged as an open item in `audio_ptt_path.md`). |
| 4 | NC | – | Not connected | Leave open |
| 5 | PTT | I | Active-low: **"0" forces TX, "1" is RX** | **Wired.** `SA818_PTT_IN` ← shared PTT node (`Q10`/`J11` circuit, see `audio_ptt_path.md`) |
| 6 | PD | I | Power-down control: **"0" = power down, "1" = normal work** | **Not yet wired.** Needs a defined level — floating is not safe (indeterminate power state). Tie high (pull-up to `+3.3V`, or a GPIO if software-controlled power-down is ever wanted) so the module defaults to normal operation. |
| 7 | H/L | I | Output power select. Datasheet's own explicit warning: **"this pin can NOT be connected to VDD or high level of cmos output."** Leave open = high power; pull to a level *below* logic-high (not a GPIO driven high) = low power. | **Not yet wired.** Leave open for high power (simplest, safest choice) unless low-power mode is specifically wanted — and if so, use a passive pull-down/resistor network, never a GPIO output, per the datasheet's explicit constraint. |
| 8 | VBAT | I | Main module supply, **3.3–5.5V** (3.3V min / 4.2V typ / 5.5V max) | **Not yet wired.** Connect to this board's dedicated 5V rail — already sized for this exact module in `regulation.md` (LM1085-5.0, 2A budget, "5V rail (→ SA818S)"). Do not use the 3.3V rail; the 5V rail's current budget was specifically calculated around this module's TX current draw. |
| 9, 10 | GND | – | Ground | **Wired.** → `GND` |
| 11 | NC | – | Not connected | Leave open |
| 12 | ANT | I/O | RF signal, connect to 50Ω antenna | **Not yet wired.** Direct 50Ω trace to the SMA connector (Amphenol 132289, `C3172723`, same part now used for GPS's `J10`) — no bias-tee needed here (unlike GPS's active-antenna feed), this is a passive/direct antenna connection per the datasheet's own "connect 50 ohm antenna" description. |
| 13, 14, 15 | NC | – | Not connected | Leave open |
| 16 | RXD | I | Module UART RX (external TXD → here) | **Wired.** ← `SA818_UART_RXD` ← ESP32-S3 IO6 (verified correct crossover — MCU TX → module RX). **Datasheet caveat**: "before enter sleep mode, user need to pull low RXD pin to prevent current leakage or poor reset in the next time" — a firmware-level requirement (drive this line low before commanding the module to sleep), not a hardware change; worth flagging for firmware. |
| 17 | TXD | O | Module UART TX (→ external RXD) | **Wired.** → `SA818_UART_TXD` → ESP32-S3 IO7 (verified correct crossover — module TX → MCU RX). |
| 18 | MIC_IN | I | Microphone or line in — sized for mic-level signals, **not** line level (see `audio_ptt_path.md`'s attenuator writeup) | **Wired.** ← `SA818_MIC_IN` ← shared DAC/attenuator/jack circuit. |
| EP1, EP2 | — | Exposed pads on the `kicad_gx_library` footprint (`WIRELM-SMD_G-NICERF_SA818S-X`) | Not part of NiceRF's own functional pin table — these look like mechanical/shield-ground tabs, common on shielded RF modules of this type. | **Not yet wired.** Recommend tying to `GND` for proper shield grounding, but this is inferred from common practice for shielded-can modules, not confirmed by NiceRF's datasheet text directly — worth a quick sanity check against the footprint's own land-pattern documentation before committing. |

## 2. What's placed and verified correct so far

Traced directly against the live schematic (`SA818V.kicad_sch` + root-level cross-sheet
wiring), not assumed:

- **UART crossover**: correct. ESP32-S3 IO6 (`MCU_SA818_UART_TXD`) → module `RXD`;
  module `TXD` → ESP32-S3 IO7 (`MCU_SA818_UART_RXD`). Not a straight-through mistake.
- **PTT**: correct. Module `PTT` ← `SA818_PTT_IN` ← the shared PTT node driven by `Q10`
  (BSS138) and routed through the switched jack (`J11`) per `audio_ptt_path.md`.
- **MIC_IN**: correct. Module `MIC_IN` ← `SA818_MIC_IN` ← the shared DAC/attenuator/jack
  audio path.
- **GND**: correct, both ground pins tied.

## 3. Still open

- **`VBAT` unconnected** — needs the board's 5V rail. This is the biggest remaining gap;
  the module has no power yet.
- **`ANT` unconnected** — needs the 50Ω trace to the SMA connector (Amphenol 132289,
  matching `J10` on the GPS sheet).
- **`PD` unconnected** — needs a defined level (recommend tie high).
- **`H/L` unconnected** — needs a defined level (recommend leave open for high power;
  never tie to a GPIO-driven high per the datasheet's explicit warning).
- **`EP1`/`EP2` unconnected** — recommend `GND`, pending a quick footprint-documentation
  sanity check.
- **`AudioON`/`AF_OUT`** — deliberately left open this pass (no onboard speaker amp);
  already tracked as an open item in `audio_ptt_path.md`.
- **TX-safety timeout (74HC123) and PTT-keying optocoupler** — still not in this path;
  PTT currently runs directly from ESP32-S3 IO16 through `Q10`, no gating/isolation stage
  yet. Tracked in `open_items.md` and `ic_inventory.md`.

## 4. Reference documents

- **[NiceRF SA818S datasheet](https://logifind.com/u_file/2108/file/91fb17a776.pdf)**
  (Rev 1.3) — source for the full pin table, electrical specs (VBAT 3.3–5.5V, current
  consumption), and the PD/H-L/RXD-sleep caveats in this doc.
- [`audio_ptt_path.md`](audio_ptt_path.md) — the shared DAC/PTT subsystem feeding this
  module's `MIC_IN` and `PTT` pins.
- [`gps_path.md`](gps_path.md) — the sibling RF module sharing the same SMA connector
  part choice.
- [`regulation.md`](regulation.md) — the 5V rail this module's `VBAT` needs to land on.

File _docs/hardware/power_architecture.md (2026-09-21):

# Power Architecture Overview

**Three** independent power sources feed the board — updated from an earlier two-source
version of this diagram once the USB/battery priority mux (Stages 2/3 below) was built:

1. **2S1P 18650 Li-ion pack** (4.2V/cell max, 8.4V max stack), protected and fuel-gauged by a MAX17320.
2. **External 12–14.5V input** (lead-acid or LiFePO4), arriving via Anderson Powerpoles, fused.
3. **USB VBUS** (via the CH334R hub's upstream port), only able to power the board when no battery is present — see [usb_battery_power_mux.md](usb_battery_power_mux.md).

Sources 1 and 2 are **fully isolated from each other on the charge path** — the 18650 pack is charged externally/separately, not through this circuit. This board's MAX17320 section handles protection and fuel gauging only. Their *outputs* are combined at Stage 1 below; USB is combined separately, downstream of regulation, at Stages 2/3.

```
18650 pack ──[MAX17320]── +7.5V ──┐
                                    ├─[Stage 1: TPS2121 VCOMP]── VRAW ──[soft-latch FET]──┬─[Buck+LDO]──[Stage 2: TPS2121]── SYSTEM_5V   (SA818S)
12–14.5V input ──[fuse]── +12V ────┘                                                      └─[Buck+LDO]──[Stage 3: TPS2121]── SYSTEM_3.3V (ESP32-S3, GPS)
                                                                                                              ↑                    ↑
                                                              USB VBUS (CH334R) ── USB_5V (raw) ──────────────┘                    │
                                                              USB VBUS (CH334R) ──[LM1117-3.3]── USB_3.3V ──────────────────────────┘
```

Stages 2/3 are set to **priority = battery** — a present, healthy battery always wins over
USB (e.g. a debug USB cable plugged in for flashing doesn't silently cut TX power). Details,
including the `ST`-pin USB-detect signal and its AND-gate combiner: [usb_battery_power_mux.md](usb_battery_power_mux.md).

The soft-latch stage (button/RTC-alarm/MCU-latch, gating VRAW before it reaches
regulation) is the mechanism behind the RTC-scheduled wake/sleep behavior described in
[controller_platform.md](controller_platform.md#power-sequencing--discrete-soft-latch) —
implemented, not just planned, as of the RTC peripheral work.

See:
- [Battery protection & fuel gauge (MAX17320)](battery_protection.md)
- [Dual-input power combining — Stage 1](power_input_combining.md)
- [Battery/USB power mux — Stages 2/3](usb_battery_power_mux.md)
- [Regulation — VRAW → 5V and 3.3V rails](regulation.md)
- [Controller & peripheral platform — soft-latch, RTC](controller_platform.md)

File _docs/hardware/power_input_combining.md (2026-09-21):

# Dual-Input Power Combining

- **TPS2121RUXR** (U3 in `power.kicad_sch`) combines the two input branches into VRAW,
  operating in VCOMP (voltage-comparator/priority) mode — it picks whichever of its two
  inputs is higher and passes that through, no external FETs or ORing controller needed.
  Superseded an earlier LM74610-Q1 + external-N-FET (AO3400A) ideal-diode design; this
  doc previously described that superseded approach and was out of date.
- IN1 = `PWR_18650` (2S1P pack, via the battery-sensing divider network), IN2 =
  `PWR_POWERPOLE` (external 12–14.5V input) — see [power_architecture.md](power_architecture.md)
  for the overall signal flow. Output (`OUT`) is VRAW, feeding the [VRAW soft-latch](controller_platform.md#power-sequencing--discrete-soft-latch)
  and then Power Regulation.
- Same TPS2121 part (in a separate VCOMP-mode instance per rail) is reused downstream for
  USB-vs-battery priority muxing on the regulated 5V/3.3V rails — see
  [usb_battery_power_mux.md](usb_battery_power_mux.md).
- Extensive solder-jumper isolation points throughout this section and the regulation
  stages, letting each stage — battery branch, 12V branch, buck input, buck-to-LDO
  handoff — be bench-tested independently before trusting the full chain.

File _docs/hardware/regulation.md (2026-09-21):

# Regulation — VRAW → 5V and 3.3V Rails

Two **independent** buck (TPS563201) + linear-LDO cascades, rather than one shared intermediate rail, so each LDO stage runs close to its own output voltage and wastes minimal power as heat.

| | 5V rail (→ SA818S) | 3.3V rail (→ ESP32-S3, GPS) |
|---|---|---|
| Buck stage | TPS563201, 6.67V intermediate | TPS563201, 4.78V intermediate |
| Inductor | 3.3µH (Chilisin MHCI06030-3R3M-R8) | 3.3µH (same part) |
| Feedback (R_top / R_bottom) | 76.8kΩ / 10kΩ, both ±0.1% thin film (Yageo RT0603, matched tolerance) | 52.3kΩ / 10kΩ, both ±0.1% thin film (Yageo RT0603, matched tolerance) |
| Output caps | 2× 22µF/16V X7R ceramic | 2× 22µF/16V X7R ceramic |
| LDO | LM1085-5.0 | LM1117IMPX-3.3/NOPB |
| LDO output cap | 22µF/16V **aluminum electrolytic** (~200mΩ ESR) | 0.1µF ceramic + 22µF/16V aluminum electrolytic (~200mΩ ESR) |
| Design current | 2A (SA818S TX peak ~750mA + margin) | 1A (real worst-case ~470mA) |
| Peak inductor current | ~2.92A | ~1.82A |
| Inductor RMS current | ~2.07A | ~1.11A |
| Output cap ripple current | ~0.531A | ~0.475A |

**Intermediate voltages were bumped up from the original 6V/4.3V targets** (68.1k/46.4k dividers) after checking LDO dropout margin — LM1085's dropout is 1.5V max (spec'd over the full current range) and LM1117's is 1.2V typ / 1.3V max, but only characterized up to its rated 800mA max output current (this rail's *design-current budget* is 1A, netclass-named `Power_3V3_1A` — see below on what the realistic load actually is). At 6V/4.3V the 5V rail had just 1.0V of raw headroom — under the LM1085's own spec — so both dividers were recalculated for 0.768V·(1+R_top/R_bottom) against actual TPS563201 reference voltage and re-sourced as precision (±0.1%) matched-tolerance pairs rather than the original 1% singles, so the divider itself no longer adds meaningfully to the output-voltage error budget.

**Margin is still tight, worst case:** at the buck's own ±2% feedback tolerance, the 5V rail's worst-case low intermediate (~6.53V) leaves only ~30mV over the LM1085's 1.5V max dropout spec. **The 3.3V rail's LDO (LM1117IMPX-3.3/NOPB) is only rated/characterized up to 800mA output current at all** — verified directly against TI's datasheet: max output current 800mA, dropout 1.2V typ/1.3V max at that same 800mA test point, and current-limit spec'd MIN 800mA (TYP 1200mA, MAX 1500mA at VIN−VOUT=5V) — meaning a worst-case unit could begin current-limiting right at 800mA. This isn't a new problem from the swap (AMS1117-3.3, the part previously used here, shares the same 800mA-family characterization — TI's own recommended AMS1117→LM1117 swap didn't change this), but it's worth being precise about: the rail's real-world worst-case load is **~470mA** (see Downstream Loads below), comfortably inside the LM1117's 800mA rating with margin to spare — it's only the netclass's nominal **1A design-current budget label** that exceeds the part's rated/characterized range, not the actual expected peripheral load. **Bench-verify both rails hold regulation at their real worst-case currents before trusting these margins in the field**, and don't plan for genuine 1A continuous draw on the 3.3V rail without reconsidering the LDO.

**Note on LDO output caps:** both LM1085 and LM1117 rely on the output cap's ESR for loop stability (opposite requirement from the buck stage's low-ESR-ceramic-friendly D-CAP2 topology) — a low-ESR ceramic reused from the buck section risks oscillation. Aluminum electrolytics in the ~100–300mΩ ESR range satisfy both LDOs' requirements.

**Implemented:** 200mA test-load jumpers with an in-line DMM measurement header on each
LDO output, for bench current verification ahead of the real downstream loads reaching
full current draw.
- 5V rail: `R22`, 24.9Ω, 2W
- 3.3V rail: `R23`, 16.5Ω, **2W** (corrected — an earlier version of this doc said 1W;
  the actual placed part is rated 2W, same as the 5V rail's)

## Downstream Loads

| Device | Rail | Typical | Peak | Placement status |
|---|---|---|---|---|
| SA818S (2m RF module) | 5V | ~60mA RX | ~750mA TX | DNP — see `ic_inventory.md` |
| ESP32-S3-WROOM-1-N8R8 | 3.3V | ~20–80mA | ~300–400mA (radio TX burst) | Placed (`mcu-esp32.kicad_sch`) |
| u-blox MAX-M10S GPS | 3.3V | ~25–45mA | ~50–70mA (acquisition) | Placed (`gps.kicad_sch`) |
| PCM5102A I2S audio DAC | 3.3V | low-mA class | — | Placed (`audio.kicad_sch`) |

Controller-section peripherals (RTC, GPS, EEPROM, SD card, audio DAC, status LEDs, 74HC123) are all low-current (µA–low-mA class) individually; a full current budget for the controller section is still TBD once that schematic exists and real component picks are finalized. See [Open Items](open_items.md).

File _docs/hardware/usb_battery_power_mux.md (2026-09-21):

# Battery/USB Power Mux (TPS2121) — Implemented

**Status: implemented.** All three TPS2121s are placed and wired in `power.kicad_sch`:
`U3` (Stage 1, VRAW combining), `U2` (Stage 2, 5V rail), `U1` (Stage 3, 3.3V rail). The
`ST`-combiner AND gate is also placed: `U4` (74LVC1G08). See
[power_input_combining.md](power_input_combining.md) for Stage 1's own write-up (that doc
already reflects the current as-built schematic).

## Why replace the LM74610 pair

The board now has three possible power sources instead of two: the 18650 pack, the
12–14.5V Powerpole input, and USB VBUS (via the CH334R hub's upstream port — see
[controller_platform.md](controller_platform.md)). The requirement driving this change:
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

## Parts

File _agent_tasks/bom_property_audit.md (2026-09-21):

# Agent Task: BOM Property Audit

Recurring task — re-run this whenever asked for a "fresh" BOM/property audit, and periodically
as the design changes (new parts added, reference designators renumbered, etc.). Each run should
treat prior results as stale rather than trusted; re-derive everything against the current
schematic state.

## Goal

For every real component across the schematic: confirm `Manf`, `MPN`, and `LCSC Part #` are set,
and for anything with an `LCSC Part #`, verify the real LCSC/JLCPCB part actually matches what
the schematic's `Value` field (and `MPN`) claims.

## Method

**Do not use `get_schematic_component` or `list_schematic_components`** — neither exposes custom
fields (Manf/MPN/LCSC Part #), only Value/footprint/position.

Instead, for each `.kicad_sch` file in `pcb/` (currently: `foxhunt1.kicad_sch`, `power.kicad_sch`,
`battery_18650_input.kicad_sch`, `battery_powerpole_input.kicad_sch`, `power_regulation.kicad_sch`,
`mcu-esp32.kicad_sch`, `usbc-programming-uart.kicad_sch` — check for new sheets added since):

1. Call `mcp__konnect__generate_netlist(schematic=<path>, output=<scratchpad>/<name>.net, format="kicad")`.
2. Read the resulting `.net` file. Each component appears as a `(comp (ref ...) (value ...)
   (footprint ...) (fields (field (name "Manf") "...") (field (name "MPN") "...")
   (field (name "LCSC Part #") "...") ...))` block — everything needed is right there, no other
   tool call required per component.

## Step 1 — Completeness check

For every real component, note whether `Manf`, `MPN`, and `LCSC Part #` are each present and
non-empty.

**Skip:**
- Power symbols (`#PWR*`, `#FLG*`).
- Pure mechanical items with no sourcing intent (solder jumpers, test points) *unless* they
  already have LCSC/MPN data set, in which case audit them too.

Produce a list of references missing one or more of the three fields, grouped by file.

## Step 2 — Cross-reference

For every component with an `LCSC Part #`, call `mcp__konnect__get_jlcpcb_part(lcsc_id=...)` and
compare the real part's description/specs against the schematic's own `Value` and `MPN` fields.
Flag a genuine mismatch only — e.g. Value says "10k" but the LCSC part is actually 4.7kΩ, or the
`MPN` field names one part but the LCSC ID resolves to something else entirely. Also flag an LCSC
ID that comes back not-found/delisted.

## Standing exceptions — do not flag these

- **Capacitor voltage in `Value` is a documented minimum, not exact.** A part rated higher than
  the labeled value (e.g. Value says "0.1u/25V", sourced part is 50V-rated) is correct.
- **Standard company-name abbreviations are equivalent**: TI/Texas Instruments, muRata/Murata
  Electronics, AOS/Alpha & Omega Semiconductor, MAXIM/Analog Devices-Maxim, and similarly obvious
  abbreviation/full-name pairs. Use judgment; don't nitpick naming style.
- **Non-LCSC-sourced parts are fine as-is** (Digikey/Mouser/Newark/SparkFun, etc.) as long as
  their own `MPN`/`Manf` fields are self-consistent. Note them as non-LCSC-sourced in the
  completeness accounting, don't flag missing `LCSC Part #` as an error for these.
- **BT1: LCSC Part# `C5339083` is delisted/not found in the JLCPCB catalog.** Known and accepted —
  don't re-flag as a "not found" defect until it's deliberately re-sourced.
- **BT2: carries the same LCSC Part# as BT1 (`C5339083`)**, the known-delisted MPD BH-18650-PC
  holder — this is correct/intentional (same physical part), not a completeness gap.
- **The two 2W THT power resistors (bleed/pre-load resistors on the 5V/3.3V LDO outputs —
  R13/R14 as of the 2nd audit pass, R22/R23 as of the 3rd; check current designators each run,
  don't trust either pair blindly) are intentionally sourced via SparkFun's own catalog
  (`PROD_ID`), not LCSC/JLCPCB.** Not JLCPCB-verifiable by design — don't flag missing
  Manf/MPN/LCSC Part# for these. Identify by description/value/position (2W THT, on the
  regulated-output bleed network), not by reference designator alone — this design has been
  through three renumbering passes and counting.

<!--
  Add newly-agreed exceptions above this line as they come up, in the same style as the three
  above (what the exception is, and why it's not a defect) — this is the list a future audit
  pass should treat as settled, not re-litigate every time.
-->

## Reporting

Structured, not narrative:

1. Overall stats — total real components audited, how many have all three fields complete, how
   many are legitimately non-LCSC-sourced.
2. Completeness gaps — references missing Manf/MPN/LCSC Part #, per file, naming which field(s).
3. Genuine mismatches — schematic claim vs. actual LCSC data, specifics only, high confidence.
4. Anything else notable that doesn't fit the above (e.g. a footprint implying one manufacturer's
   pad geometry while the sourced part is from a different manufacturer — a real physical risk,
   not just a naming inconsistency).

## Scale note

This covers ~100+ components across 7 files and one JLCPCB lookup per LCSC-sourced part — treat
as a background/forked task rather than doing it inline, to keep the bulk tool output out of the
main conversation's context.

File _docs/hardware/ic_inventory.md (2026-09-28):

# IC Inventory

Every IC (and RF module, treated the same way here) used or planned in the design.
Pricing/stock snapshotted 2026-09-20 — LCSC prices and stock move constantly, re-check
before actually ordering. Brand-preference rule applied throughout (per your stated
criteria): reputable global brands (TI, onsemi, NXP, Nexperia, Microchip, u-blox, etc.)
preferred over Asian-market-only brands when the price point is reasonable (under ~$1–2)
and the reputable option isn't meaningfully worse on stock. Cheaper Asian-market brands
are kept where the price gap is real and material (WCH's USB-UART/hub parts, already
placed — several dollars cheaper than CP2102N/FTDI-class equivalents for equivalent
function, a good call).

# Inventory

## Placed (in the schematic today)

| Function | Qty | Manufacturer | MPN | Package | LCSC Part # | LCSC Price (unit) | LCSC Stock | Refs |
| --- | --- | --- | --- | --- | --- | --- | --- | --- |
| Battery fuel gauge/protector | 1 | Maxim (Analog Devices) | MAX17320G22+ | TQFN-24 (4×4mm) | `C2914309`  | $5.86 (1pc) | 376 | U5 |
| Battery/PowerPole input mux (VCOMP) | 3 | TI | TPS2121RUXR | VQFN-12 (2.5×2.0mm) | `C485916` | $1.06 (1pc) | 39,768 | U1, U2, U3 |
| Logic AND gate (latch wake-OR support) | 1 | TI | SN74LVC1G08DBVR | SOT-23-5 | `C7666` | $0.049 (10+; MOQ 10) | 88,180 | U4 |
| Buck converter, 5V/3.3V pre-regulation | 2 | TI | TPS563201DDCR | SOT-23-6 | `C116592` | $0.063 (10+; MOQ 10) | 73,660 | U6, U7 |
| LDO, 5V rail cleanup | 1 | HANSCHIP Semiconductor | LM1085IS-5.0RG | TO-263-3 | `C5145336`  | $0.30 (1pc) | 980 | U8 |
| LDO, 3.3V rail cleanup + USB-side 3.3V | 2 | TI | LM1117IMPX-3.3/NOPB | SOT-223-3 | `C23984` | $0.134 (1pc) | in stock | U9, U12 |
| MCU module | 1 | Espressif | ESP32-S3-WROOM-1-N8R8 | RF module | `C2913201`  | $5.04 (1pc) | 722 | U10 |
| USB hub | 1 | WCH | CH334R | QSOP-16 | `C4154405`  | $0.57 (1pc) | 19,833 | U11 |
| USB-UART bridge | 1 | WCH | CH340C | SOIC-16 | `C84681` | $0.59 (1pc) | 106,811 | U13 |
| RTC | 1 | NXP | PCF8563T/5,518 | SOIC-8 | `C7440` | $0.63 (1pc) | 13,425 | U14 |
| I2C GPIO expander | 1 | TI | PCA9555PWR | TSSOP-24 | `C2864778`  | $0.73 (1pc) | 14,239 | U15 |
| I2C EEPROM (config storage) | 1 | onsemi | CAT24C32YI-GT3 | SOIC/TSSOP-8 | `C94264` | $0.187 (1pc) | in stock | U16 |
| RGB status LED (WS2812-class) | 1 | Worldsemi | WS2812B-B/W | SMD5050-4P | `C114586` | $0.1042 (1pc) | 351,335 | D4 |
| GPS/GNSS module | 1 | u-blox | MAX-M10S-00B | Module | `C4153167`  | $9.81 (1pc) | 763 | U18 |
| I2S audio DAC | 1 | TI | PCM5102APWR | TSSOP-20 | `C107671` | $0.83 (1pc) | in stock | U17 |

**Flag on the LDO (U8):** HANSCHIP Semiconductor is a smaller Chinese manufacturer, not in
the same reputation tier as the rest of this list — an existing pick from before this
inventory pass, not something chosen against the stated brand preference. See the LDO —
5V Rail section below for a same-price-tier, reputable-brand swap option. (The equivalent
flag on the 3.3V LDO has since been resolved — swapped from AMS1117-3.3 to TI
LM1117IMPX-3.3/NOPB.)

## Planned (chosen part, not yet placed)

| Function | Qty | Manufacturer  | MPN | Package | LCSC Part # | LCSC Price (unit)  | LCSC Stock | Notes |
| --- | --- | --- | --- | --- | --- | --- | --- | --- |
| VHF RF transceiver module | 1 (DNP) | G-NiceRF | SA818S-V | Module | — | — | — | **DNP — sourced outside LCSC**, not part of the JLCPCB assembly BOM. See below. |
| Dual retriggerable monostable (TX-safety timeout) | 1 | Nexperia | `74HC123D`,653 | SOIC-16 | `C5597` | $0.33 (5pc, MOQ 5) | 24,075 | Genuine dual-section part — needed, since one section is reserved for the hold-to-power-off hardware failsafe. |
| Forward-power fault comparator | 1 | onsemi | LM393DR2G | SOIC-8 | `C7955` | $0.032 (1pc) | 209,190 | Cheapest, best-stocked, and a named-preferred brand — no tradeoff. |
| PTT-keying optocoupler | 1 | *unconfirmed* | *(PC817-class, single-channel)* | SOP-4/DIP-4 | — | ~$0.02–0.06 | varies | Not finalized — see its own section below. |

# Alternatives

**Compatibility rating** used throughout this section: three sub-scores, 0–2 each, summed
to a /6 total.

- **Pin/Footprint** — 2 = identical footprint *and* pinout (true drop-in); 1 = same
  package family but a pin function or pitch differs; 0 = different package entirely.
- **Electrical/Functional** — 2 = same core function and comparable specs, no circuit
  changes needed; 1 = same function, some parameter difference needing minor passive/BOM
  rework (different divider resistors, different caps, etc.); 0 = different topology,
  needs a real redesign.
- **Sourcing** — 2 = well-stocked (>1,000 units) *and* a reputable brand; 1 = one of the
  two but not both; 0 = low stock and/or an unverified/no-name brand.

| Total | Tier |
| ----- | --- |
| 5–6 | **Drop-in** — swap with no board changes |
| 3–4 | **Compatible, minor rework** — same footprint or function, expect small BOM/value changes |
| 1–2 | **Functional alternative, redesign needed** — different footprint or topology |
| 0 | **Not recommended** |

---

## Battery Fuel Gauge / Protector

2S–4S Li-ion pack protection (over/under-voltage, over-current, temperature) plus
ModelGauge m5 EZ fuel gauging, driving external high-side N-FETs for CHG/DIS control.
This is a fairly specialized combined function — genuine drop-in alternates are scarce.

| | Manufacturer | MPN | Package | LCSC Part # | Price | Stock | Compat. |
| --- | --- | --- | --- | --- | --- | --- | --- |
| **Selected** | **Maxim (ADI)** | **MAX17320G22+** | **TQFN-24** | **`C2914309`** | **$5.86** | **376** | — |
| Alt. 1 | Maxim (ADI) | MAX17205 | Different pin-count | *not priced this pass* | — | — | 2/6 — same family, but a monitor/balance IC without the integrated protector; needs a separate protection path. Different pinout, partial function match, sourcing unconfirmed. |
| Alt. 2 | TI | BQ76942 | Different package | *not priced this pass* | — | — | 1/6 — analog front-end architecture, not a fuel gauge; would need a separate gauge IC alongside it. Real redesign, not a substitution. |

**Bottom line:** no real drop-in exists for this exact part at this price/stock tier;
if `MAX17320` ever becomes unavailable, budget for a redesign, not a swap.

## Power Mux (VCOMP)

2:1 priority power multiplexer — automatically selects and seamlessly switches between
two input sources via ideal-diode operation. One instance combines the battery vs.
PowerPole 12V input into VRAW; two more instances mux USB vs. battery-regulated output on
the 5V and 3.3V rails.

| | Manufacturer | MPN | Package | LCSC Part # | Price | Stock | Compat. |
| --- | --- | --- | --- | --- | --- | --- | --- |
| **Selected** | **TI** | **TPS2121RUXR** | **VQFN-12** | **`C485916`** | **$1.06** | **39,768** | — |
| Alt. 1 | TI | TPS2116 | Different package | *not priced this pass* | — | — | 2/6 — newer-generation TI part, but only rated 1.6–5.5V input; fine for the 3.3V/5V rail-mux instances, **not usable** for the raw battery-mux instance (VRAW reaches ~14.4V). Different footprint too. |

**Bottom line:** worth checking `TPS2116` specifically for the two rail-mux instances
(cheaper, lower Rds(on), same brand) as a *partial* swap, but the battery-mux instance
needs `TPS2121`'s higher voltage headroom regardless.

## Logic AND Gate (latch wake-OR support)

Single 2-input AND gate supporting the VRAW soft-latch wake network.

| | Manufacturer | MPN | Package | LCSC Part # | Price | Stock | Compat. |
| --- | --- | --- | --- | --- | --- | --- | --- |
| **Selected** | **TI** | **SN74LVC1G08DBVR** | **SOT-23-5** | **`C7666`** | **$0.049 (10+)** | **88,180** | — |
| Alt. 1 | Nexperia | 74LVC1G08GW,125 | SOT-23-5 (TSOP-5) | `C12512` | $0.067 (1pc) | 13,365 | 6/6 — industry-standard single-gate pinout, identical package, same reputable-brand tier. True drop-in. |

## Buck Converter (VRAW → 5V/3.3V pre-regulation)

Synchronous step-down converter, D-CAP2 control, SOT-23-6. Two instances (5V and 3.3V
pre-regulation stages, both feeding their respective LDO).

| | Manufacturer | MPN | Package | LCSC Part # | Price | Stock | Compat. |
| --- | --- | --- | --- | --- | --- | --- | --- |
| **Selected** | **TI** | **TPS563201DDCR** | **SOT-23-6** | **`C116592`** | **$0.063 (10+)** | **73,660** | — |
| Alt. 1 | Diodes Incorporated | AP62200WU-7 | SOT-23-6 (similar) | `C1323282` | $0.091 (est.) | 41,605 | 4/6 — similar 6-pin footprint and function, but 2A rated vs. TPS563201's 3A (this design's actual draw is 2A per `regulation.md`, so likely fine in practice) — different control architecture/switching frequency means it's not a blind pin-swap, verify loop stability with the existing LC values. |
| Alt. 2 | Richtek | RT8059 | **SOT-23-5** | — | — | — | 1/6 — wrong pin count (5 vs. 6), excluded as a footprint match despite similar function. |
| Alt. 3 | Monolithic Power Systems | MP2315 | **TSOT-23-8** | — | — | — | 1/6 — wrong package entirely. |

## LDO — 5V Rail

Linear regulator, TO-263, cleaning up the 5V buck's output for the SA818S.

| | Manufacturer | MPN | Package | LCSC Part # | Price | Stock | Compat. |
| --- | --- | --- | --- | --- | --- | --- | --- |
| **Selected** | **HANSCHIP Semiconductor**  | **LM1085IS-5.0RG** | **TO-263-3** | **`C5145336`** | **$0.30** | **980** | — |
| Alt. 1 | TI | LM1085IT-5.0/NOPB | **TO-220**, not TO-263 | `C9721` | $2.32 | 0 (out of stock) | 2/6 — genuine TI part, but wrong package *and* out of stock at LCSC right now. Not a practical swap today. |
| Alt. 2 | TI | LM1084IRTG3-5.0 (5A version) | TO-263-3 | *not priced this pass* | — | — | 5/6 — TI states this shares LM317's pinout, same as LM1085's; more current headroom than needed (5A vs. this design's 2A). Likely the best reputable-brand swap if you want to move off HANSCHIP, pending a price/stock re-check. |
| Alt. 3 | Advanced Monolithic Systems | AMS1085CM-5.0 (if stocked; only the -3.3 variant was confirmed this pass) | TO-263 | *not priced this pass* | — | — | 4/6 — same brand family already used elsewhere in this design (U9/U12), genuinely pin-compatible per AMS's own datasheet claims; voltage variant not independently confirmed in stock this pass. |

## LDO — 3.3V Rail (main + USB-side)

Linear regulator, SOT-223, fixed 3.3V — used for both the main 3.3V rail cleanup and the
USB-VBUS-derived logic-only 3.3V path.

| | Manufacturer | MPN | Package | LCSC Part #  | Price | Stock | Compat. |
| --- | --- | --- | --- | --- | --- | --- | --- |
| **Selected (placed, U9/U12)** | **TI** | **LM1117IMPX-3.3/NOPB** | **SOT-223-3** | **`C23984`** | **$0.134 (1pc)** | **in stock** | — |
| Former pick | Advanced Monolithic Systems | AMS1117-3.3 | SOT-223-3 | `C6186` | $0.22 (5pc) | 881,175 | 6/6 — genuinely pin-to-pin and electrically compatible with the current pick per TI's own datasheet (same SOT-223 1117-family pinout); kept here since it's still a valid fallback if TI stock ever tightens. |
| Alt. 1 | onsemi | NCP1117ST33T3G | SOT-223-3 | `C26537` | $0.099 (1pc) | in stock | 6/6 — same 1117-family drop-in pinout, cheaper still, onsemi is equally reputable. |
| Alt. 2 | Richtek | RT9193 | **SOT-23-5**  | — | — | — | 1/6 — different, smaller package; not a footprint match despite similar low-dropout function. |

**Bottom line:** resolved — swapped from AMS1117-3.3 to TI LM1117IMPX-3.3/NOPB on both
U9 and U12, cheaper and a more reputable brand with no footprint change.

## MCU Module

ESP32-S3 with 8MB flash + 8MB octal PSRAM (PSRAM matters for concurrent WiFi + audio +
SD workload, see `controller_platform.md`).

| | Manufacturer  | MPN | Package | LCSC Part # | Price | Stock | Compat. |
| --- | --- | --- | --- | --- | --- | --- | --- |
| **Selected** | **Espressif** | **ESP32-S3-WROOM-1-N8R8** | **Module, 56 pads** | **`C2913201`** | **$5.04** | **722**  | — |
| Alt. 1 | Espressif | ESP32-S3-MINI-1-N8 | Smaller module, different footprint/pad count | `C2913206` | $3.14 | 2,084 | 2/6 — cheaper and better-stocked, but a genuinely different footprint (smaller module, fewer castellated pads) — real board rework, not a swap. Also lacks octal PSRAM in the plain `-N8` variant (check `-N8R2`/similar if PSRAM is still wanted). |
| Alt. 2 | Espressif | ESP32-S3-WROOM-2-N32R8V | Same WROOM-2 footprint family, larger flash/PSRAM | `C3021270` | $13.74 | in stock | 3/6 — likely closer to pin-compatible (same WROOM form factor lineage) but meaningfully more expensive for capability this design doesn't need. Not independently confirmed pin-identical to WROOM-1 this pass. |

**Bottom line:** this module's footprint is effectively a one-off within this design —
no meaningfully cheaper drop-in exists; the MINI variant is the real cost/size lever, but
it's a layout change, not a swap.

## USB Hub

Splits one USB-C connection between the MCU's native USB and the USB-UART bridge.

| | Manufacturer | MPN | Package | LCSC Part # | Price | Stock | Compat. |
| --- | --- | --- | --- | --- | --- | --- | --- |
| **Selected** | **WCH** | **CH334R** | **QSOP-16** | **`C4154405`** | **$0.57** | **19,833** | — |
| Alt. 1 | Microchip | USB2513B-AEZC-TR | Different package/pinout | `C219466` | $1.25 | reported out of stock | 1/6 — reputable brand, but ~2x the price *and* not currently stocked; also a 3-port hub architecture, not a direct pin match. |
| Alt. 2 | Microchip | USB2517-JZX | Different package/pinout, 7-port | *(see below)*  | $2.52 | in stock | 1/6 — genuine global brand and in stock, but ~4.4x the price for a 7-port hub this design doesn't need — the WCH price/function fit is clearly better here. |

**Bottom line:** this is the case referenced in your own message — WCH is the right call;
the "reputable brand" alternates cost multiples more for capability this design doesn't
use.

## USB-UART Bridge

Standalone USB-to-UART bridge for a stable serial console across MCU resets (native-USB
CDC re-enumerates on every reset, this doesn't).

| | Manufacturer | MPN | Package | LCSC Part #  | Price | Stock | Compat. |
| --- | --- | --- | --- | --- | --- | --- | --- |
| **Selected** | **WCH** | **CH340C** | **SOIC-16** | **`C84681`** | **$0.59**  | **106,811** | — |
| Alt. 1 | Silicon Labs | CP2102N-A02-GQFN28R | **QFN-28**, different footprint | `C964632` | $1.02–1.22 | 40,646 | 2/6 — the "professional-grade" alternative (better driver polish, configurable GPIOs), but ~2x the price and a completely different QFN footprint — real rework, not a swap. |

**Bottom line:** same story as the hub — WCH wins on price for equivalent function;
CP2102N would be the pick only if driver/GPIO features become worth the cost and layout
change.

## RTC

I2C real-time clock/calendar, external 32.768kHz crystal, coin-cell-backed.

| | Manufacturer  | MPN | Package | LCSC Part # | Price | Stock | Compat. |
| --- | --- | --- | --- | --- | --- | --- | --- |
| **Selected** | **NXP** | **PCF8563T/5,518** | **SOIC-8** | **`C7440`** | **$0.63** | **13,425** | — |
| Alt. 1 | NXP | PCF8523T/1,118 | SOIC-8 | `C2651516`  | $0.56 | in stock | 3/6 — same brand, same 8-pin SO package, newer/lower-power design — but a *different* pin function layout and a 1MHz vs. 400kHz I2C spec, so not pin-identical despite matching package. Would need re-checking the crystal load-cap requirement too. |
| Alt. 2 | Micro Crystal | RV-3028-C7-32.768kHz-1ppm-TA-QC | Different package | `C3019759`  | $1.40 | in stock | 2/6 — far better accuracy (±1ppm vs. PCF8563's crystal-dependent accuracy) and only 45nA backup draw, but a different footprint and meaningfully pricier — this design already accepts PCF8563's accuracy since GPS periodically disciplines it, so the upgrade isn't needed, just noting it exists. |
| Alt. 3 | Maxim (ADI) | DS3231 | Different package, integrated TCXO | — | ~$9–10.50 | — | 1/6 — already considered and rejected in `controller_platform.md` for cost; included here only for completeness. |

## GPS/GNSS Module

Standard-precision GNSS, UART+PPS (deliberately not I2C — see `gps_path.md` § 2), external active antenna via SMA.

| | Manufacturer | MPN | Package | LCSC Part # | Price | Stock | Compat. |
| --- | --- | --- | --- | --- | --- | --- | --- |
| **Selected** | **u-blox** | **MAX-M10S-00B** | **Module (LCC)** | **`C4153167`** | **$9.81** | **763** | — |
| Alt. 1 | u-blox | NEO-M9N-00B | Larger module, different footprint | `C5119087` | $15.96 | **2 — effectively out of stock** | 2/6 — same brand, but a different (larger, older-generation) module footprint, more expensive, and barely stocked. Not a good swap right now. |
| Alt. 2 | Quectel | L76-K | Different footprint | — | ~$12.50–15.90 | — | 2/6 — reputable global brand (Quectel), meter-level accuracy similar class, but different module footprint and pricier — real board rework, not a swap. |

**Bottom line:** `MAX-M10S` is already the best price/stock/capability fit in its class;
the alternates are strictly worse on at least two axes each.

## VHF RF Transceiver Module

The onboard SA818S footprint (and the shared audio/PTT path also serving an external HT
jack) — see `controller_platform.md`.

**Status: DNP, part locked in — 5x already purchased.** Confirmed not sourced through
LCSC — this footprint won't be part of the JLCPCB assembly BOM. When this footprint is
added to the schematic, place it with `(dnp yes)` from the start rather than defaulting
to populated and fixing it later.

**Re-confirmed 2026-09-21** after a fresh (bias-free) lifecycle/availability review across
SA818S/SA818Pro/SA828/SA828Pro/SA868S — SA818S remained the right pick on its own merits
(lowest current draw of the viable options, richest hobbyist tooling ecosystem, cheapest,
and the architecture already has its own MCU driving the module over UART, so SA828's
onboard multi-channel memory would be unused capability paid for at ~2x cost and higher
current draw). Full comparison in this session's conversation history if revisited later.

**Purchased**: 5x, from G-NiceRF's own official Tindie store
(tindie.com/products/nicerf/sa818s-walkie-talkie-module-with-rda1846s-chip/), VHF variant
(134–174MHz, matching this project's 2m fox-hunting band), $8.50/unit, real manufacturer-
direct source (35 reviews, 1,632 orders on that listing at time of purchase).

| | Manufacturer | MPN | Package | Notes |
| --- | --- | --- | --- | --- |
| **Selected (DNP), 5x purchased** | **G-NiceRF** | **SA818S-V** | **Module** | Not sourced via LCSC — see status note above. Real datasheet specs: 500mW/1W selectable output, 3.3–5.5V, ≤1µA sleep / 60mA RX / 450–750mA TX current, -124dBm sensitivity. |

No alternates researched further — decision re-confirmed and closed, see note above.

## I2S Audio DAC

Simple stereo I2S DAC for voice-ID/CW-tone audio, feeding the SA818S/HT MIC path.

| | Manufacturer | MPN | Package | LCSC Part # | Price | Stock | Compat. |
| --- | --- | --- | --- | --- | --- | --- | --- |
| **Selected** | **TI** | **PCM5102APWR** | **TSSOP-20** | **`C107671`** | **$0.83** | in stock | — |
| Alt. 1 | NXP | UDA1334ATS/N2,118 | Different package, similar pin-count | `C494494` | $0.70 | in stock | 3/6 — equally reputable brand, cheaper, same core I2S-DAC function — but a different physical package/pinout (not independently confirmed pin-identical), so likely a footprint change even though electrically a straightforward swap. |
| Alt. 2 | TI | PCM5122 | Different, larger pinout | — | — | — | 2/6 — same family, more features (headphone amp, etc.) this design doesn't need, different pinout — not a drop-in. |

## RGB Status LED (WS2812-class)

**Placed (D4).** Single addressable RGB LED, native GPIO (RMT peripheral, IO40/pin 33 —
see `esp32s3_pinout.md`), not behind the I2C expander since it needs real serial-protocol
bit timing a static register can't produce. `DOUT` explicitly no-connect flagged (only LED
in the chain). Encodes GPS search/lock, fault conditions, and found-log mode active (see
`controller_platform.md` § Status indication).

| | Manufacturer  | MPN | Package | LCSC Part # | Price | Stock | Compat. |
| --- | --- | --- | --- | --- | --- | --- | --- |
| **Selected (placed, D4)** | **Worldsemi** | **WS2812B-B/W** | **SMD5050-4P** | **`C114586`** | **$0.1042**  | **351,335** | — |
| Alt. 1 | XINGLIGHT | XL-5050RGBC-2812B | SMD5050-4P | `C2843785` | $0.059 (10+) | 627,390 | 6/6 — same footprint and the same WS2812B protocol/timing (industry-standard clone), cheaper and even better-stocked — but Worldsemi is the originating manufacturer of the WS2812B part itself, so it's the more canonical pick even though this clone is a genuine drop-in. |
| Alt. 2 | Worldsemi | WS2812B-V5/W | SMD5050-4P | `C2874885` | $0.0566 | 247,045 | 6/6 — same manufacturer, newer die revision (V5), same footprint/protocol — a slightly cheaper same-brand option if the -B/W's exact bin/revision doesn't matter. |

**Bottom line:** Worldsemi WS2812B-B/W is the standard, most widely-supported pick for
this exact part family (matches the huge base of existing WS2812B firmware
libraries/timing tables); XINGLIGHT's clone is a legitimate cost-down if stock/price ever
matters more than sticking with the originating manufacturer.

## I2C GPIO Expander

**Placed (U15).** Drives 4 general-purpose LEDs and 8 general-purpose switch inputs from
register writes instead of native GPIOs (see `esp32s3_pinout.md` and `controller_platform.md`
§ Status indication — the original TX-active/heartbeat-specific plan turned into a
general-purpose expansion block; role assignment is now firmware's job).

| | Manufacturer | MPN | Package | LCSC Part # | Price | Stock | Compat. |
| --- | --- | --- | --- | --- | --- | --- | --- |
| **Selected (placed, U15)** | **TI** | **PCA9555PWR** | **TSSOP-24** | **`C2864778`** | **$0.73** | **14,239** | — |
| Alt. 1 | NXP | PCF8574T/3,518 | **SOIC-8**, 8-bit | `C7605` | $1.17 | 2,991 | 2/6 — half the I/O (8-bit vs. 16-bit), smaller/different package, pricier, and capped at 100kHz I2C — strictly worse on every axis for this use case. |
| Alt. 2 | TI | PCA9535RGER | Different package (VQFN) | `C2873080` | *not priced this pass* | — | 4/6 — same 16-bit register model and TI brand, functionally near-identical to PCA9555 (minor pull-up-config register differences), but a different QFN footprint. |

## I2C EEPROM

**Placed (U16).** 32Kbit config storage — schedule, frequency, TX power, tone settings —
independent of the SD card.

| | Manufacturer | MPN | Package | LCSC Part #  | Price | Stock | Compat. |
| --- | --- | --- | --- | --- | --- | --- | --- |
| **Selected (placed, U16)** | **onsemi** | **CAT24C32YI-GT3** | **TSSOP-8** | **`C94264`** | **$0.187** | in stock | — |
| Alt. 1 | Microchip | AT24C32D-SSHM-T | SOIC-8 | `C60583` | $0.154 | in stock | 6/6 — originally-named part in the docs; the 24Cxx family pinout is an industry standard across every manufacturer, so this is a true drop-in either direction. |
| Alt. 2 | STMicroelectronics | M24C32-FMN6TP | SOIC-8 | `C2061453` | $0.079 | in stock | 6/6 — same standard pinout, cheapest of the three, equally reputable brand. |

**Bottom line:** all three are genuinely interchangeable; the onsemi part is the one
actually placed on the board. ST's is the cheapest if cost ever becomes the deciding
factor.

## Dual Retriggerable Monostable (TX-safety timeout)

RC-timed hardware watchdog gating the PTT line — one section for the 2-minute TX
ceiling, the other reserved for the hold-to-power-off hardware failsafe.

| | Manufacturer | MPN | Package | LCSC Part # | Price | Stock | Compat. |
| --- | --- | --- | --- | --- | --- | --- | --- |
| **Selected** | **Nexperia** | **74HC123D,653** | **SOIC-16** | **`C5597`** | **$0.33 (5pc)** | **24,075** | — |
| Alt. 1 | TI | CD74HCT123E | SOIC-16 | `C2872602`  | $0.39 (list) | **out of stock at LCSC when checked** | 4/6 — same standard 74x123 pinout (industry-standard across HC/HCT/LS variants) and a reputable brand, but unavailable right now — otherwise a clean swap. |
| Alt. 2 | onsemi | 74VHC123AMX | SOIC-16 | `C6636` | *not priced this pass* | 74 (very low) | 3/6 — same pinout family, reputable brand, but stock is too thin to rely on. |
| Alt. 3 | TI | SN74LVC1G123DCUR | **Single-section, SC-70/SOT** | `C123302` | $1.04 | 664 | 0/6 — wrong part shape entirely: single monostable, not dual. This design specifically needs the second section for the power-off failsafe — excluded despite being a genuine TI part. |

## Forward-Power Fault Comparator

Fast, ADC-independent "antenna fault / near-zero power" digital trip, paired with the
ADC-based power-level readback.

| | Manufacturer | MPN | Package | LCSC Part # | Price | Stock | Compat. |
| --- | --- | --- | --- | --- | --- | --- | --- |
| **Selected** | **onsemi** | **LM393DR2G** | **SOIC-8** | **`C7955`** | **$0.032** | **209,190** | — |
| Alt. 1 | STMicroelectronics | LM393ADT | SOIC-8 | `C136033` | $0.137 | 42,510 | 6/6 — LM393 is an industry-standard dual-comparator pinout duplicated across essentially every analog manufacturer; genuine drop-in, just pricier than the onsemi pick. |
| Alt. 2 | TI | LM393DR | SOIC-8 | *not priced this pass* | — | — | 6/6 (expected) — same standard part, TI's own version; not independently priced this pass but functionally identical to the above. |

**Bottom line:** already the best pick — cheapest, best-stocked, reputable brand, and
the alternates only exist to confirm there's no compatibility risk if onsemi's ever runs
short.

## PTT-Keying Optocoupler

Isolates the MCU's PTT-intent signal from the SA818S/HT keying line.

| | Manufacturer | MPN | Package | LCSC Part # | Price | Stock | Compat. |
| --- | --- | --- | --- | --- | --- | --- | --- |
| **Selected** | *unconfirmed* | *(PC817-class, single-channel)* | SOP-4/DIP-4 | — | — | — | — |
| Alt. 1 | Sharp | PC817X3NSZW(C) | DIP-4, single-channel | `C4075` | $0.146 (5pc) | **out of stock** | 5/6 if in stock — genuine reputable-brand single-channel part, standard PC817 footprint; just unavailable right now. |
| Alt. 2 | Toshiba (via licensed manufacture) | TLP621-1 | DIP-4, single-channel | `C84568` (ISOCOM-branded listing) | $0.115 | in stock | 4/6 — standard PC817-equivalent footprint, single-channel, in stock — but this specific LCSC listing is ISOCOM's own manufacture of the TLP621 part number, not genuine Toshiba; still a reputable specialist opto brand, not a no-name clone. |
| Alt. 3 | UMW / generic | PC817C | DIP-4, single-channel | `C3008368` | $0.015 | 172,080 | 3/6 — correct footprint and function, huge stock, trivial cost — but an unverified/no-name-tier brand. Given the entire PC817 class costs a few cents regardless of brand, the "under $1–2" brand-preference threshold barely bites here; Alt. 2 is the more defensible pick if brand matters, Alt. 3 if it's purely a cost/stock decision. |

**Bottom line:** none of these is a slam dunk — recommend confirming stock on `TLP621-1`
(Alt. 2) at actual build time rather than locking in a choice now.

---

## Verification note

Placed-row data is copied from the schematic's own properties (already individually
datasheet/LCSC-verified earlier in this project's history — see
`_docs/sourcing/task1_lcsc_crossreference.md`), not re-verified here. Planned-row parts and
every alternate above were checked against LCSC search results this pass; a few alternates
are explicitly marked "not priced this pass" or "not independently confirmed" rather than
given invented numbers — treat those as leads to verify, not settled facts, before acting
on them.

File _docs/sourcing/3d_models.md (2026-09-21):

# 3D models — search & download status

Task 4 deliverable. Scope: custom (non-stock) footprints used across `kicad_gx_library` and the
project's libraries. Download only — no linking/alignment, per the task's explicit instruction
(that's a manual step).

**Format policy (updated): STEP (.stp/.step) is priority, IGES (.igs/.iges) is the only
acceptable fallback. VRML (.wrl) is explicitly excluded — not downloaded even when it's the
only thing available.**

## Already covered, no action needed

| Part | Footprint | Status |
|---|---|---|
| Anderson Powerpole connector (J3, 1377G12-BK) | `kicad_gx_library:Connector_Anderson_PP25_RA_1377g12-bk` | **Already present**, and already compliant with the STEP/IGES policy — `pcb/libs/kicad_gx_library/3dmodels/GX.3dshapes/Anderson_PP25_1377G12_Housing.igs` and `Anderson_PP_15-45_Std.step`. Footprint doesn't reference them yet (manual linking step, out of scope here). |
| Chilisin inductor (L3/L4, MHCI06030-3R3M-R8) | `kicad_gx_library:L_Chilisin_MHCI06030` | **Already linked** to a stock KiCad model (`.step`) — footprint's own `(model ...)` block points at `${KICAD10_3DMODEL_DIR}/Inductor_SMD.3dshapes/L_Chilisin_BMRA00040415.step`. Compliant, nothing to do. |
| 8205A dual-FET (Q2) | `digikey-kicad-library:SOT23-6L` | Standard SOT-23-6 package — **`/usr/share/kicad/3dmodels/Package_TO_SOT_SMD.3dshapes/SOT-23-6.step`** confirmed present on disk. Compliant, nothing to do. |
| MAX17320 (U2, QFN-24-1EP 4x4mm EP2.1x2.1mm) | `Package_DFN_QFN:TQFN-24-1EP_4x4mm_P0.5mm_EP2.1x2.1mm` | **Verified present**: `/usr/share/kicad/3dmodels/Package_DFN_QFN.3dshapes/Texas_RGE0024C_VQFN-24-1EP_4x4mm_P0.5mm_EP2.1x2.1mm.step` (exact EP-size match) and a generic `HVQFN-24-1EP_4x4mm_P0.5mm_EP2.1x2.1mm.step` in the same folder. |
| LM74610 (U7/U10, VSSOP-8 3x3mm) | `Package_SO:VSSOP-8_3x3mm_P0.65mm` | **Verified present**: `/usr/share/kicad/3dmodels/Package_SO.3dshapes/VSSOP-8_3x3mm_P0.65mm.step` — exact match. |
| TPS563201 (U1/U3, SOT-23-6) | `Package_TO_SOT_SMD:SOT-23-6` | Same stock model as the 8205A entry above — already covered. |
| LM1117IMPX-3.3/NOPB (U9, U12 — swapped from AMS1117-3.3, SOT-223-3) | `Package_TO_SOT_SMD:SOT-223` | **Verified present**: `/usr/share/kicad/3dmodels/Package_TO_SOT_SMD.3dshapes/SOT-223.step` — exact name match now (footprint changed to the plain `SOT-223` name as part of the part swap; previously a same-shape stand-in for a differently-named footprint). |
| LM1085-5.0 (U8, TO-263-3) | `Package_TO_SOT_SMD:TO-263-3_TabPin2` | **Verified present**: `/usr/share/kicad/3dmodels/Package_TO_SOT_SMD.3dshapes/TO-263-3_TabPin2.step` — exact match. |

All 5 standard-package ICs from the original task list are confirmed (file paths checked directly
on disk, not just assumed) to already have compliant STEP models bundled with the stock KiCad 10
install. No download action needed for any of them.

## Genuinely missing — searched again, still gated/unreachable

| Part | Footprint | Sources tried this pass | Result |
|---|---|---|---|
| Polytronics CLM1612P1412 PTC fuse (F2) | `kicad_gx_library:Fuse_PTCC_CLM1612` | Mouser product page (timeout), Polytronics' own site `polytronics.com.tw` (connection refused — site appears unreachable from this environment) | Not found. Previously also checked: LCSC/EasyEDA (requires JS session or a conversion tool like `easyeda2kicad`, no plain download link). |
| Multicomp Pro MCCQ-122 mini-blade fuseholder (F3) | `kicad_gx_library:Fuse_MCCQ-122` | Digikey product page (HTTP 403 Forbidden), Farnell datasheet page (timeout) | Not found. Previously also checked: Component Search Engine, SnapEDA, Ultra Librarian — all require account sign-in or are JS-rendered with no static download link. |

Both parts have real STEP/IGES models that exist somewhere (confirmed by name/listing on the
gated sites), but no plain, unauthenticated `curl`-able URL was found across two search passes
and 8+ distinct sources. A human can retrieve either in under a minute via a browser session
(the Component Search Engine link for MCCQ-122, and Mouser's product page for the Polytronics
fuse, are both quick manual downloads) — that's the practical path forward rather than further
automated attempts.

## Recommendation

For the two remaining gated fuse models: download manually via a browser (links above), or set up
`easyeda2kicad` (a real, actively maintained CLI tool) as a one-time integration if this project
ends up needing many more EasyEDA/LCSC-sourced 3D models going forward.

## Uncommitted state

No git commits made. Files present on disk from this pass: none newly downloaded (everything
in scope was either already present/linked, or remains gated after a genuine retry). The 5
standard-IC entries above are newly *verified* (file existence confirmed) but were not new
downloads — they were already part of the stock KiCad install.

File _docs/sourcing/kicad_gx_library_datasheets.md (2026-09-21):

# kicad_gx_library — Symbol Datasheets

For each symbol whose definition lives in `pcb/libs/kicad_gx_library/GX.kicad_sym` (not to be
confused with symbols that merely *use a footprint* from that library — see
`project_library_datasheets.md` for those), confirm/fetch an English-language datasheet, store
it under `pcb/libs/kicad_gx_library/datasheets/`, and link it both at the library-symbol-default
level and at each placed schematic instance.

8 symbols now live in this library. The first 4 (Results table below) were done in an earlier
pass; `BAS116LT1G`, `BS-08-B2AA020-R`, `CAT24C32YI-GT3`, and `TPS2121RUXR` were added since, and
localized in the most recent datasheet-localization run (see
`_agent_tasks/datasheet_localization.md`).

## Results

| Symbol | Refs (sheet) | MPN | Manf | LCSC# | Local path | Library-level linked | Instance-level linked |
|---|---|---|---|---|---|---|---|
| `8205A` | Q2 (battery_18650_input) | 8205A | ALJ | C22458966 | `pcb/libs/kicad_gx_library/datasheets/JSMICRO/8205A.pdf` | ✅ | ✅ |
| `LM74610` | U7, U10 (foxhunt1) | LM74610QDGKRQ1 | TI | C2649431 | `pcb/libs/kicad_gx_library/datasheets/Texas_Instruments/LM74610QDGKRQ1.pdf` | ✅ | ✅ (both refs) |
| `MAX17320` | U2 (battery_18650_input) | MAX17320G22+ | MAXIM | C2914309 | `pcb/libs/kicad_gx_library/datasheets/Analog_Devices/max17320.pdf` | ✅ | ✅ |
| `POLY_FUSE` | F2 (battery_18650_input) | CLM1612P1412 | PTTC(Polytronics Tech) | C5353611 | `pcb/libs/kicad_gx_library/datasheets/Polytronics/CLM1612-12A.pdf` | ✅ | ✅ |
| `BAS116LT1G` | D2, D3 (peripherals) | BAS116LT1G | onsemi | C232527 | `pcb/libs/kicad_gx_library/datasheets/onsemi/BAS116LT1G.pdf` | ✅ | ✅ (both refs) |
| `BS-08-B2AA020-R` | BT3 (peripherals) | BS-08-B2AA020-R | MYOUNG(美阳) | C964787 | `pcb/libs/kicad_gx_library/datasheets/MYOUNG/BS-08-B2AA020-R.pdf` | ✅ | ✅ |
| `CAT24C32YI-GT3` | U16 (peripherals) | CAT24C32YI-GT3 | onsemi | C94264 | `pcb/libs/kicad_gx_library/datasheets/onsemi/CAT24C32YI-GT3.pdf` | ✅ | ✅ |
| `TPS2121RUXR` | U1, U2, U3 (power) | TPS2121RUXR | TI | C485916 | `pcb/libs/kicad_gx_library/datasheets/Texas_Instruments/TPS2121RUXR.pdf` | ✅ | ✅ (all 3 refs) |

All `Datasheet` properties (library-default and per-instance) now use
`${KIPRJMOD}/libs/kicad_gx_library/datasheets/...` relative paths — self-contained, matches
this project's established submodule-portability convention, no absolute paths or external
URLs left in the design.

Verified with `run_erc` on the project root after linking: **19 pre-existing errors** (unused
ESP32-S3 GPIOs, unrelated to this task), **0 warnings**.

## What was downloaded vs. already present (most recent pass)

- All 4 new symbols' original schematic `Datasheet` fields were LCSC `product-detail` pages
  (JS-rendered viewer wrappers), not direct files, or (for `BS-08-B2AA020-R`) an
  `lcsc.com/datasheet/*.pdf` redirect page — same pattern as the original 4. Resolved by
  extracting the real `datasheet.lcsc.com/datasheet/pdf/<hash>.pdf` CDN link embedded in each
  page's HTML and downloading that directly.
- `BAS116LT1G`, `CAT24C32YI-GT3`, `TPS2121RUXR` — all confirmed genuinely English on download,
  no substitution needed.
- `BS-08-B2AA020-R` — a mechanical drawing (MYOUNG battery holder), not prose; predominantly
  English (all dimensions, ordering info, tolerances, material notes), with a handful of small
  Chinese annotations (department stamp, a couple of field labels) alongside their English
  equivalents. Accepted as-is — same judgment call as the two bilingual/mixed datasheets noted
  below, not treated as a fallback-required case since the technical content is fully usable in
  English.

## Language caveat (not blocking, worth knowing)

Three of these datasheets are **bilingual/mixed**, not pure English:
- `8205A.pdf` (ALJ) — English title/headline, but the features section and some body text
  is Chinese. ALJ is a Chinese manufacturer; a pure-English alternate wasn't readily found.
- `CLM1612-12A.pdf` (Polytronics) — appears to be primarily a Chinese-market document. An
  attempt to fetch Polytronics' own English literature timed out (network); not replaced.
- `BS-08-B2AA020-R.pdf` (MYOUNG) — see above; mostly-English mechanical drawing with minor
  Chinese annotations.

Neither blocks usability (key tables/pinouts are numeric/English-labeled either way), but
flagging per the task's "prefer English" instruction in case a cleaner English source is
wanted later.

## Note for the coordinator

`pcb/libs/kicad_gx_library` is a git submodule with its own remote (`gx1400/kicad_gx_library`).
The datasheet additions and the `GX.kicad_sym` property edits (both the original 4-symbol pass
and the most recent 4-symbol addition) are uncommitted changes in that submodule's working
tree — per this project's established two-repo pattern (see `CLAUDE.md`), these need their own
commit+push inside the submodule, then a submodule-pointer bump commit in the parent repo. Not
done here per instructions (no commits from this task).

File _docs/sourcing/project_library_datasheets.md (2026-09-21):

# Project Library Datasheets

Datasheets for every placed-component part that is **not** one of the symbols in
`pcb/libs/kicad_gx_library/` (those are documented separately in
`_docs/sourcing/kicad_gx_library_datasheets.md`). Files live under `pcb/project_library/datasheets/`,
organized into per-manufacturer subfolders. All schematic `Datasheet` fields below use the
`${KIPRJMOD}`-relative path convention.

**Scope update:** the original pass covered 23 unique parts / 27 instances across 4 schematic
sheets. A subsequent datasheet-localization run (see `_agent_tasks/datasheet_localization.md`)
covered the full 8-sheet hierarchy and localized every remaining part whose `Datasheet` field
was still a live remote URL — 41 unique parts across `power.kicad_sch`,
`battery_18650_input.kicad_sch`, `power_regulation.kicad_sch`, `mcu-esp32.kicad_sch`,
`usbc-programming-uart.kicad_sch`, and `peripherals.kicad_sch`. Two parts could not be resolved
(see Gaps). The table below now mixes both passes; rows added/updated in the most recent run are
marked accordingly.

| Symbol (lib_id) | Refs | MPN | Manf | LCSC # | Source URL | Local path | Linked |
|---|---|---|---|---|---|---|---|
| `Device:C_Small` | C8, C11, C35, C7, C1, C34, C33, C2, C15, C32 | GRM188R71H104KA93D | Murata Electronics | C57112 | https://www.lcsc.com/datasheet/lcsc_datasheet_... (via wmsc.lcsc.com CDN) | `pcb/project_library/datasheets/Murata_Electronics/GRM188R71H104KA93D.pdf` | Yes — all 10 refs *(ref list predates later renumbering passes — identify by MPN, not designator, per this doc's own repeated caveat)* |
| `Device:C_Small` | C29, C31, C30, C28 | GRM31CZ71C226ME15L | Murata Electronics | — | LCSC (wmsc.lcsc.com CDN) | `pcb/project_library/datasheets/Murata_Electronics/GRM31CZ71C226ME15L.pdf` | Yes — all 4 refs |
| `PCM_SparkFun-Resistor:R` | R4, R2, R1, R3 | RC0805FR-0710KL | YAGEO | — | LCSC (wmsc.lcsc.com CDN) | `pcb/project_library/datasheets/YAGEO/RC0805FR-0710KL.pdf` | Yes — all 4 refs |
| `Device:C_Small` | C14, C16, C13 | GRM188R71A474KA61D | Murata Electronics | — | LCSC (wmsc.lcsc.com CDN) | `pcb/project_library/datasheets/Murata_Electronics/GRM188R71A474KA61D.pdf` | Yes — all 3 refs |
| `Device:C_Small` | C18, C19 | GRM21BR71C105KA01L | Murata Electronics | — | LCSC (wmsc.lcsc.com CDN) | `pcb/project_library/datasheets/Murata_Electronics/GRM21BR71C105KA01L.pdf` | Yes — both refs |
| `Device:C_Small` | C5, C4, C6, C3 | GRM21BZ71E106KE15L | muRata | C237493 | LCSC (wmsc.lcsc.com CDN) | `pcb/project_library/datasheets/Murata_Electronics/GRM21BZ71E106KE15L.pdf` | Yes — all 4 refs |
| `Device:C_Small` | C12 | GCM219R71E474KA55D | Murata Electronics | — | LCSC (wmsc.lcsc.com CDN) | `pcb/project_library/datasheets/Murata_Electronics/GCM219R71E474KA55D.pdf` | Yes |
| `Device:C_Small` | C37, C36 | XT1C220M0506 | JARSON | C5260805 | LCSC (wmsc.lcsc.com CDN, numeric prefix 2304140030) | `pcb/project_library/datasheets/JARSON/XT1C220M0506.pdf` | Yes — both refs |
| `Device:Thermistor` | TH1 | NCP15XH103F03RC | Murata Electronics | — | LCSC (wmsc.lcsc.com CDN) | `pcb/project_library/datasheets/Murata_Electronics/NCP15XH103F03RC.pdf` | Yes |
| `PCM_SparkFun-Resistor:R` | R13 | RC0805FR-07820RL | YAGEO | — | LCSC (wmsc.lcsc.com CDN) | `pcb/project_library/datasheets/YAGEO/RC0805FR-07820RL.pdf` | Yes |
| `PCM_SparkFun-Resistor:R` | R8 | RC0805FR-0710RL | YAGEO | — | LCSC (wmsc.lcsc.com CDN) | `pcb/project_library/datasheets/YAGEO/RC0805FR-0710RL.pdf` | Yes |
| `PCM_SparkFun-Resistor:R` | R9, R10 | RT1206BRD07150RL | YAGEO | — | LCSC (wmsc.lcsc.com CDN) | `pcb/project_library/datasheets/YAGEO/RT1206BRD07150RL.pdf` | Yes — both refs |
| `PCM_SparkFun-Resistor:R` | R12 | RC0805FR-071KL | YAGEO | *(none — Task 1 finding: LCSC field empty; confirmed C95781 is the correct matching part via `get_jlcpcb_part`, not written to schematic — out of this task's scope)* | LCSC (wmsc.lcsc.com CDN) | `pcb/project_library/datasheets/YAGEO/RC0805FR-071KL.pdf` | Yes |
| `PCM_SparkFun-Resistor:R` | R11 | HoJLR2512-3W-2.5mR-1% | Milliohm | — | LCSC (wmsc.lcsc.com CDN) | `pcb/project_library/datasheets/Milliohm/HoJLR2512-3W-2.5mR-1_.pdf` | Yes |
| `PCM_SparkFun-Resistor:R` | R5 | AC0603FR-0768K1L | YAGEO | C228015 | LCSC (wmsc.lcsc.com CDN) | `pcb/project_library/datasheets/YAGEO/AC0603FR-0768K1L.pdf` | Yes |
| `PCM_SparkFun-Resistor:R` | R6 | RC0805FR-0746K4L | YAGEO | C483162 | LCSC (wmsc.lcsc.com CDN) | `pcb/project_library/datasheets/YAGEO/RC0805FR-0746K4L.pdf` | Yes |
| `PCM_SparkFun-Resistor:R` | R16, R7 | *(none — no confirmed specific MPN/LCSC; "PROD_ID" field only: RES-07856)* | Vishay (series-level only) | — | Vishay DCRCWE3 series page (generic, not part-specific) | `pcb/project_library/datasheets/Vishay/dcrcwe3_series_generic.pdf` | Yes, but flagged **unconfirmed/generic** — both refs *(note: current live schematic has R7 re-sourced to a real YAGEO part, RT0603BRE0780K6L — see new row below; this old row's "R7" reference is stale, kept for R16 only going forward)* |
| `Regulator_Switching:TPS563201` | U3, U1 | TPS563201DDCR | TI | C116592 | LCSC (wmsc.lcsc.com CDN) | `pcb/project_library/datasheets/TI/TPS563201DDCR.pdf` | Yes — both refs *(ref list is stale — current U1/U3 are TPS2121RUXR, see `kicad_gx_library_datasheets.md`; identify this row by MPN)* |
| `Device:L` | L4, L3 | MHCI06030-3R3M-R8 | Chilisin | C108294 | LCSC (wmsc.lcsc.com CDN) | `pcb/project_library/datasheets/Chilisin/MHCI06030-3R3M-R8.pdf` | Yes — both refs |
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

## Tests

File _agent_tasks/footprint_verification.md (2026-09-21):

# Agent Task: Footprint Verification

Recurring task — re-run this whenever asked for a "footprint audit" or similar, and
periodically as new parts get added to the schematic. Unlike the other two recurring
audit tasks, this one is **differential**: it maintains a persistent log
(`_docs/sourcing/footprint_verification_log.md`) across runs, and a repeat run only needs
to fully re-analyze parts that are new or changed since the last pass — see "Repeated
runs" below.

**This task never edits any footprint, symbol, or schematic file.** It is read-only
end to end — its entire output is the log table plus a findings summary for a human to
act on. If you find a real mismatch, write it down clearly; do not attempt to fix it.

## Goal

For every unique placed part (by MPN/footprint, not by reference designator), answer
three questions in order and record the result:

1. **Does the declared package match the real part?** Cross-reference the part's real
   package (from its datasheet and/or LCSC listing) against what the schematic assumes
   (the `Package` property if set, and/or what the `Footprint` property's name implies).
2. **Is the footprint used a known, standard one for that package?** i.e. is it one of
   KiCad's own stock library footprints (`Package_TO_SOT_SMD:*`, `Resistor_SMD:*`,
   `Capacitor_SMD:*`, `Package_SO:*`, etc.) that's a well-established, community-vetted
   match for the declared package — or is it a one-off/custom footprint?
3. **For anything that isn't a standard stock footprint** (see "Focus areas" below) —
   does the footprint's actual pad geometry (pitch, pad size, overall body/courtyard
   dimensions, pad count) match the datasheet's own mechanical/package-outline drawing?
4. **For anything `easyeda2kicad`-migrated specifically** — does the resulting
   `.kicad_mod`'s geometry faithfully preserve the *original* EasyEDA source footprint's
   geometry, independent of whatever the datasheet says? This isolates conversion-tool
   errors from datasheet-mismatch errors — two different failure modes, see "Quantitative
   method" below.

**All of the above must be answered with real numbers, not adjectives.** "Pad envelope
looks plausible" is not an acceptable cross-reference result on its own — report the
actual measured value, the actual datasheet-stated value (with its tolerance), and the
delta or ratio between them. A reviewer should be able to see the two numbers and judge
the match themselves, not just trust a verdict word.

## Focus areas — where the real risk is

Standard KiCad stock library footprints (anything under a well-known stock library like
`Package_TO_SOT_SMD`, `Resistor_SMD`, `Capacitor_SMD`, `Package_SO`, `Package_DFN_QFN`,
etc.) are heavily community-vetted — for these, a package-family match (question 2) is
normally enough; don't burn time re-deriving pad pitch from scratch for a plain SOT-23 or
0603 unless something about the specific part looks unusual.

**Spend the real effort on:**
- Anything with a `kicad_gx_library:` footprint (hand-authored or `easyeda2kicad`-migrated
  — check `Source` property; `"easyeda2kicad"` means auto-migrated, no `Source` property
  usually means hand-authored for this project).
- Anything with a `project_library:` or other non-stock footprint reference.
- Any stock-library footprint that seems like an unusual pick for its declared package
  (flag for a closer look even if you don't have time to fully dimension-check it).

## Method

Use the same per-file netlist approach as `_agent_tasks/bom_property_audit.md` for
enumerating parts and their `Manf`/`MPN`/`LCSC Part #`/`Footprint`/`Package` fields. Cover
the same file list (check for new sheets): `foxhunt1.kicad_sch`, `power.kicad_sch`,
`battery_18650_input.kicad_sch`, `battery_powerpole_input.kicad_sch`,
`power_regulation.kicad_sch`, `mcu-esp32.kicad_sch`, `usbc-programming-uart.kicad_sch`,
`peripherals.kicad_sch`.

For each unique part:

1. **Determine the real package.** Check the datasheet (already localized under
   `pcb/project_library/datasheets/` or `pcb/libs/kicad_gx_library/datasheets/` per the
   datasheet-localization task — read it directly rather than re-fetching) and/or the
   LCSC listing for the part's actual package designation. Compare against the
   schematic's own `Package` property (if set) and what the `Footprint` name implies.
2. **Get the footprint's actual geometry.** `get_footprint_info(footprint_path="<lib
   nickname>:<footprint name>", include_pads=true, include_graphics=true)` — takes the
   exact `Library:Footprint` string straight from the component's `Footprint` property,
   no need to resolve a file path yourself. Gives pad positions/sizes (compute pitch from
   consecutive pad centers) and courtyard/silkscreen graphics.
3. **Cross-reference against known footprints (question 2).** `search_footprints(query=
   "<package name>")` or `list_library_footprints` on relevant stock libraries to see
   what KiCad's own standard footprint would be for this package, and compare.
4. **For focus-area parts (question 3): read the datasheet's mechanical/package-outline
   page** (usually near the end, titled something like "Package Outline Dimensions,"
   "Mechanical Data," or a JEDEC drawing) and compare pitch, body size, pad count, and
   overall footprint dimensions against what step 2 returned. Note the datasheet's stated
   tolerance/range, not just a single number, when judging a match. Write the actual
   numbers down (e.g. "pitch: KiCad 1.90mm vs. datasheet 1.90mm±0.10mm → match"), not a
   prose conclusion alone.
5. **For `easyeda2kicad`-migrated parts specifically (question 4) — cross-reference
   against the original EasyEDA source, not just the datasheet:**
   - Fetch `https://easyeda.com/api/products/<LCSC_ID>/components?version=6.4.19`
     (public, unauthenticated, no key needed — the same endpoint `easyeda2kicad` itself
     uses; confirmed reachable in this environment). The footprint's raw pad geometry is
     under `result.packageDetail.dataStr` (`shape` entries for pads, `head` for canvas
     scale info) — in EasyEDA's own internal units, not mm.
   - **Do not assume a fixed EasyEDA-unit-to-mm scale constant** — that just substitutes
     one unverified number for another. Instead, compute **relative dimensions (ratios)**
     from the raw EasyEDA pad coordinates that need no unit conversion at all: e.g.
     pitch÷pad-width, or (pad1-to-pad2 distance)÷(pad2-to-pad3 distance). Compute the
     identical ratios from the real-mm `.kicad_mod` geometry (step 2). Matching ratios
     mean the conversion preserved proportions correctly; diverging ratios mean the
     conversion tool distorted the geometry, regardless of what the datasheet says.
   - This is a second, independent check from step 4 — a part can pass one and fail the
     other (e.g. conversion preserved proportions perfectly, but the *original* EasyEDA
     footprint itself didn't match the real part; or conversion distorted an
     otherwise-correct source). Report both results distinctly, don't merge them into one
     verdict.
6. **Score confidence** per the rubric below and write the row.

## Confidence rubric (0-100%, single number per row)

Start from the applicable band, adjust for real findings:

- **95-100%** — Standard KiCad stock footprint, package family clearly matches the real
  part, nothing unusual. (Dimension-level check not required to reach this band.)
- **70-94%** — Footprint family is right and plausible, but either (a) it's a stock
  footprint for a part with a slightly unusual variant/pinout not independently checked,
  or (b) it's a focus-area footprint (gx-library/easyeda-migrated/custom) whose measured
  dimensions matched the datasheet within its stated tolerance (and, for
  `easyeda2kicad`-migrated parts, whose relative-dimension ratios also matched the
  original EasyEDA source — both checks, not just one).
- **40-69%** — Focus-area footprint that could not be fully dimension-verified (datasheet
  lacked a clear mechanical drawing, EasyEDA source data was unavailable/malformed, or a
  ratio check was inconclusive) — flag for manual review, not confirmed wrong, just not
  confirmed right either.
- **10-39%** — A real, specific numeric discrepancy was found (measured pitch/pad-size/
  body-size outside the datasheet's stated tolerance, *or* a relative-dimension ratio that
  diverges from the original EasyEDA source beyond plausible rounding) but it might still
  function (e.g. a slightly oversized courtyard) — needs a human look before layout.
- **0-9%** — Pad count or fundamental package family mismatch (e.g. footprint is a 3-pin
  SOT-23 for a part that's actually SOT-223-4, or a 0603 footprint on a part that's
  actually SOIC-8) — flag prominently, this would fail assembly.

Always report the actual numbers next to the percentage (measured value, datasheet value
with tolerance, and/or the ratio comparison), not just a prose verdict — the number alone
doesn't tell a reviewer what to go check, and two numbers side by side let them verify
your conclusion without repeating the work.

## Log format

`_docs/sourcing/footprint_verification_log.md`, one row per unique part:

| Manf | MPN | LCSC Part # | Refs | Package (declared/real) | Footprint used | Source | Cross-reference result | Confidence | Last audit |
|---|---|---|---|---|---|---|---|---|---|

- **Source** — `stock` / `kicad_gx_library (hand-authored)` / `kicad_gx_library
  (easyeda2kicad)` / `project_library` / other.
- **Cross-reference result** — the actual numbers, not just a verdict word: measured
  dimension(s) vs. datasheet-stated value with tolerance, and, for
  `easyeda2kicad`-migrated parts, the relative-dimension ratio comparison against the
  original EasyEDA source (report both checks distinctly if both apply — datasheet-match
  and conversion-fidelity are independent questions, one can pass while the other fails).
- **Last audit** — the date of the run that produced or last confirmed this row.

Append a short **Findings** section above the table on every run: anything scoring below
70%, called out explicitly with the ref designators, so it's visible without reading the
whole table.

## Repeated runs — differential, not full re-analysis

On every run after the first:

1. Read the existing log first.
2. Re-enumerate current parts (step 1 above is cheap — always do this fresh, reference
   designators and part lists both drift in this project).
3. For a part whose `MPN`, `LCSC Part #`, and `Footprint` are **unchanged** from its
   existing log row: just bump `Last audit` to today's date and copy the row forward —
   don't re-open its datasheet or re-run `get_footprint_info` on it.
4. For a part that's **new** (no existing row) or **changed** (any of those three fields
   differ from the log) — run the full method above and write a fresh row.
5. For a logged part that **no longer appears** in any schematic — remove its row (or
   move it to a small "no longer placed" note at the bottom, your judgment on which reads
   better) rather than leaving it silently stale.

## Scale note

First run is the expensive one — every unique part gets the full treatment, similar
shape to the other two recurring audits (~60-70 unique parts, one or two datasheet
mechanical-page reads plus one `get_footprint_info` call for anything in a focus area).
Treat it as a background/forked task. Repeat runs should be much cheaper given the
differential behavior above — still fine to fork, but don't expect the same depth of
tool calls unless a lot changed.

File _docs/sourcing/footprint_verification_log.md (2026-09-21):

# Footprint Verification Log

Generated/maintained by `_agent_tasks/footprint_verification.md`. Read-only audit — no
footprint, symbol, or schematic file is ever edited by this task. Anything scoring below
70% needs a human look before layout; see Findings below.

Method note: `get_jlcpcb_part`/the `integration` toolset was not invocable this run
(consistent with the other two recurring audits this session) — used direct
`get_footprint_info` calls against library footprints, plus WebFetch/WebSearch for
datasheet mechanical pages, instead.

## Findings (anything below 70%)

1. **F1 (Fuse_PTCC_CLM1612, Polytronics CLM1612P1412) — 45%.** The footprint has 3 pads
   of two different sizes (two 2.4×1.55mm pads + one 1.2×1.6mm pad, asymmetric), but
   LCSC's own listing describes CLM1612P1412 as a compact 3.2×1.6×0.65mm SMD part with no
   confirmed pin count. Polytronics' own datasheet couldn't be fetched (site unreachable,
   consistent with the datasheet-localization task's own finding for this same part) to
   settle whether this is genuinely a 3-terminal "current limiting module" (plausible —
   the part name itself suggests more than a plain 2-terminal PTC fuse) or a wrong
   footprint. Inconclusive, not confirmed wrong — needs the real datasheet in hand.
2. **L1, L2 (L_Chilisin_MHCI06030, MHCI06030-3R3M-R8) — 55%.** The footprint's own
   embedded description string cites a *different* Chilisin part number entirely
   (`BMRA00040415`, 4.6×4.1×1.5mm) instead of the real placed part. Fetched Chilisin's
   real MHCI06030-series mechanical spec directly: body is A=6.6±0.2mm × C=3.0mm max,
   noticeably bigger than the BMRA part the description names. The footprint's actual
   pad geometry (2.35×3.5mm pads, ~8.4mm outer span) is a plausible, generously-sized
   land pattern for the real 6.6×3.0mm-class part — so this is very likely fine
   electrically/mechanically, but the footprint's self-documentation names the wrong
   part, which is a real traceability bug (already flagged once before in
   `_docs/sourcing/3d_models.md`, still unresolved).
3. **BT3 (BAT-SMD_BS-08-B2AA016, actual MPN BS-08-B2AA020-R) — 60%.** The footprint file
   itself is named after a *sibling* MYOUNG part number (`...016`) that differs from the
   MPN actually in the schematic (`...020-R`). These look like same-family
   plating/packaging variants (MYOUNG's `BS-08-B2AA0xx` line), which often share an
   identical physical footprint, but that wasn't independently confirmed against a real
   MYOUNG mechanical drawing this pass — flagging the name mismatch for a human check
   rather than assuming they're identical.
4. **Fuse_MCCQ-122 (F2, Multicomp Pro MCCQ-122) — 65%.** Footprint has 4 physical pads
   but only 2 distinct pad numbers (two pads each tied to "1", two to "2") — plausible
   for a mini-blade fuseholder clip (twin prongs per terminal for grip strength), and
   internally consistent (duplicate-numbered pads share a net by KiCad convention), but
   Multicomp's own datasheet wasn't available to independently confirm this exact
   4-contact/2-net topology is correct for MCCQ-122 specifically.

## Log

| Manf | MPN | LCSC Part # | Refs | Package (declared/real) | Footprint used | Source | Cross-reference result | Confidence | Last audit |
|---|---|---|---|---|---|---|---|---|---|
| TI | SN74LVC1G08DBVR | C7666 | U4 | SOT-23-5 / SOT-23-5 | `Package_TO_SOT_SMD:SOT-23-5` | stock | Standard single-gate logic footprint, exact package match. | 98% | 2026-09-20 |
| HCTL | HC-TYPE-C-16P-01A | C2894897 | J3 | USB-C receptacle / same | `Connector_USB:USB_C_Receptacle_HCTL_HC-TYPE-C-16P-01A` | stock | Footprint literally named after this exact vendor+part number. | 98% | 2026-09-20 |
| JST | B3B-PH-SM4-TB(LF)(SN) | C160353 | J4,J5,J6,J7 | 3-pin PH / same | `Connector_JST:JST_PH_B3B-PH-SM4-TB_1x03-1MP_P2.00mm_Vertical` | stock | Footprint name is the exact JST part number. | 98% | 2026-09-20 |
| Phoenix Contact | MCV 1,5/2-GF-3,81 | — | J2 | 2-pos terminal block / same | `Connector_Phoenix_MC:PhoenixContact_MCV_1,5_2-GF-3.81_1x02_...` | stock | Footprint name is the exact Phoenix part number. | 97% | 2026-09-20 |
| Anderson Power Products | 1377G12-BK | — | J1 | PowerPole PCB-mount / same | `kicad_gx_library:Connector_Anderson_PP25_RA_1377g12-bk` | kicad_gx_library (hand-authored) | 2 THT pads, 7.9mm pitch, 1.8mm drill — close to Anderson's official 0.31"/7.874mm ganged-housing pitch (~0.03mm off). A real 3D model for this exact part was independently matched in this project's history (`3d_models.md`). Plausible and likely correct; not re-derived pin-by-pin from Anderson's own PCB dimension drawing this pass. | 80% | 2026-09-20 |
| MPD (Memory Protection Devices) | BH-18650-PC | C5339083 (delisted) | BT1,BT2 | 18650 holder / same | `Battery:BatteryHolder_MPD_BH-18650-PC` | stock | Stock KiCad footprint literally named after this exact manufacturer+MPN. | 96% | 2026-09-20 |
| muRata | GRM1885C1H103JA01D | C85973 | C1,C2,C3 | 0603 / same | `Capacitor_SMD:C_0603_1608Metric` | stock | Standard 0603 ceramic cap footprint, package matches MPN's own "1885" (0603 metric) code. | 97% | 2026-09-20 |
| muRata | GRM188R71H104KA93D | C77055 | C42,C50,C4,C5,C11,C12,C13,C18,C19,C24,C25,C26,C27,C44,C45,C46,C47,C48,C49,C51,C31,C33,C35,C37,C38,C39,C41,C30,C52 | 0603 / same | `Capacitor_SMD:C_0603_1608Metric` | stock | Standard 0603 ceramic cap footprint, matches "188" package code. | 97% | 2026-09-20 |
| muRata | GRM188R71A474KA61D | C435402 | C7,C8,C9 | 0603 / same | `Capacitor_SMD:C_0603_1608Metric` | stock | Same family as above. | 97% | 2026-09-20 |
| — (DNP) | — | — | C43 | n/a | `Capacitor_SMD:C_0603_1608Metric` | stock | Deliberate DNP placeholder, not a real sourced part — nothing to cross-reference. | n/a | 2026-09-20 |
| muRata | GCM219R71E474KA55D | C437481 | C6 | 0805 / same | `Capacitor_SMD:C_0805_2012Metric` | stock | Standard 0805 ceramic cap footprint, "219" = 0805 metric code. | 97% | 2026-09-20 |
| muRata | GRM21BZ71E106KE15L | C237493 | C14,C15,C16,C17,C34 | 0805 / same | `Capacitor_SMD:C_0805_2012Metric` | stock | Same family, "21B" = 0805 metric code. | 97% | 2026-09-20 |
| muRata | GRM21BR71H105KA12L | C77083 | C32,C36 | 0805 / same | `Capacitor_SMD:C_0805_2012Metric` | stock | Same family. | 97% | 2026-09-20 |
| muRata | GRM31CZ71C226ME15L | C909845 | C10,C20,C21,C22,C23 | 1206 / same | `Capacitor_SMD:C_1206_3216Metric` | stock | "31C" = 1206 metric code, matches. | 96% | 2026-09-20 |
| JARSON | XT1C220M0506 | C5260805 | C28,C29,C40 | SMD electrolytic / same | `Capacitor_SMD:C_Elec_5x5.8` | stock | MPN's own "0506" size code (5x6mm-class) matches the 5x5.8mm stock footprint reasonably closely. | 88% | 2026-09-20 |
| LUTE | 0805L050/16XR | C22435898 | F3 | 0805 fuse / same | `Fuse:Fuse_0805_2012Metric` | stock | MPN's own "0805" prefix matches the stock 0805 fuse footprint exactly. | 95% | 2026-09-20 |
| Kingbright | APT2012LZGCK | C5569446 | D7 | 0805 LED / same | `LED_SMD:LED_0805_2012Metric` | stock | MPN's "2012" = 0805 metric, matches. | 96% | 2026-09-20 |
| Kingbright | APTD2012LSURCK | C5366382 | D8 | 0805 LED / same | `LED_SMD:LED_0805_2012Metric` | stock | Same family. | 96% | 2026-09-20 |
| Kingbright | APTD2012LQBC/D | C5879058 | D9 | 0805 LED / same | `LED_SMD:LED_0805_2012Metric` | stock | Same family. | 96% | 2026-09-20 |
| Kingbright | APTD2012LSYCK | C5588998 | D10 | 0805 LED / same | `LED_SMD:LED_0805_2012Metric` | stock | Same family. | 96% | 2026-09-20 |
| Worldsemi | WS2812B-B/W | C114586 | D4 | PLCC-4 5.0x5.0mm / same | `LED_SMD:LED_WS2812B_PLCC4_5.0x5.0mm_P3.2mm` | stock | Stock footprint specifically named for this exact part family (WS2812B PLCC-4). | 97% | 2026-09-20 |
| Littelfuse | SMAJ18A | C148219 | D1 | SMA / same | `Diode_SMD:D_SMA` | stock | "SMAJ" prefix = SMA package, matches. | 96% | 2026-09-20 |
| YAGEO | RT0603BRE075KL | C862232 | R1,R4 | 0603 / same | `Resistor_SMD:R_0201_0603Metric` | stock | KiCad's dual-standard 0201/0603 footprint name; MPN's "0603" prefix confirms 0603. | 93% | 2026-09-20 |
| muRata | NCP15XH103F03RC | C77131 | TH1 | 0402 thermistor / same | `Resistor_SMD:R_0402_1005Metric` | stock | "XH" 0402-class Murata thermistor on the matching 0402 footprint. | 94% | 2026-09-20 |
| UNI-ROYAL | 0603WAF2372T5E | C22912 | R2,R3 | 0603 / same | `Resistor_SMD:R_0603_1608Metric` | stock | MPN's own "0603" prefix matches. | 96% | 2026-09-20 |
| YAGEO | RC0603FR-0730K1L, RT0603BRE0780K6L, RC0603FR-071ML, RT0603BRD0710KL, RT0603BRD0776K8L, RT0603BRD0752K3L, RC0603FR-07100KL, RC0603FR-07750RL, RC0603FR-07330RL, RC0603DR-07590RL, RC0603FR-071KL, RC0603JR-075K1L | (per-part, see Refs) | R5,R8,R7,R29,R18,R19,R30,R34,R32,R33,R20,R21,R31,R35,R36,R38,R37,R39,R40,R41,R42,R24,R25 | 0603 / same | `Resistor_SMD:R_0603_1608Metric` | stock | All YAGEO "0603" family MPNs on the matching 0603 footprint — consistent block, grouped here for brevity. | 96% | 2026-09-20 |
| YAGEO | RC0805FR-0710KL, RC0805FR-0710RL, RC0805FR-071KL, RC0805FR-07820RL | (per-part) | R6,R9,R16,R17,R26,R27,R28,R10,R14,R15 | 0805 / same | `Resistor_SMD:R_0805_2012Metric` | stock | All YAGEO "0805" family MPNs on the matching 0805 footprint. | 96% | 2026-09-20 |
| YAGEO | RT1206BRD07150RL | C870430 | R11,R12 | 1206 / same | `Resistor_SMD:R_1206_3216Metric` | stock | MPN's "1206" prefix matches. | 96% | 2026-09-20 |
| (SparkFun-catalog, no MPN/LCSC) | — | — | R22,R23 | 2W axial THT / same | `Resistor_THT:R_Axial_Power_L20.0mm_W6.4mm_P5.08mm_Vertical` | stock | Not JLCPCB-verifiable by design (standing BOM-audit exception) — generic parametric THT axial-power shape is a reasonable, standard choice for a 2W bleed resistor; can't cross-check against a real datasheet without an MPN/LCSC ID. | 75% | 2026-09-20 |
| Milliohm | HoJLR2512-3W-2.5mR-1% | C2904234 | R13 | 2512 4-pad Kelvin sense / same | `kicad_gx_library:RES-SMD_L6.4-W3.2-R2512_Sense4Pin` | kicad_gx_library (hand-authored) | Confirmed force pads 2.0×3.3mm + sense pads 0.5×0.5mm — matches this project's own prior direct verification against the Milliohm datasheet (`task1_lcsc_crossreference.md`). Re-confirmed, not re-derived from scratch. | 92% | 2026-09-20 |
| Multicomp Pro | MCCQ-122 | — | F2 | mini-blade fuseholder / plausible | `kicad_gx_library:Fuse_MCCQ-122` | kicad_gx_library (hand-authored) | See Findings #4 above. | 65% | 2026-09-20 |
| Polytronics (PTTC) | CLM1612P1412 | C5353611 | F1 | 3.2×1.6mm SMD / pin count unconfirmed | `kicad_gx_library:Fuse_PTCC_CLM1612` | kicad_gx_library (hand-authored) | See Findings #1 above. | 45% | 2026-09-20 |
| Chilisin | MHCI06030-3R3M-R8 | C108294 | L1,L2 | 6.6×3.0mm power inductor / footprint envelope plausible | `kicad_gx_library:L_Chilisin_MHCI06030` | kicad_gx_library (hand-authored) | See Findings #2 above. | 55% | 2026-09-20 |
| MYOUNG(美阳) | BS-08-B2AA020-R | C964787 | BT3 | CR2032 SMD holder / sibling-part footprint name | `kicad_gx_library:BAT-SMD_BS-08-B2AA016` | kicad_gx_library (easyeda2kicad) | See Findings #3 above. | 60% | 2026-09-20 |
| onsemi | BAS116LT1G | C232527 | D2,D3 | SOT-23 / same | `kicad_gx_library:SOT-23_L2.9-W1.3-P1.90-LS2.4-BR` | kicad_gx_library (easyeda2kicad) | Pad pitch is exactly 1.9mm — the real JEDEC SOT-23 (TO-236) standard — and the footprint's own name states it. Dimensionally correct standard SOT-23. | 92% | 2026-09-20 |
| onsemi | CAT24C32YI-GT3 | C94264 | U16 | TSSOP-8 / same | `kicad_gx_library:TSSOP-8_L4.4-W3.0-P0.65-LS6.4-BL` | kicad_gx_library (easyeda2kicad) | Pad pitch 0.65mm, body width 3.0mm — exact JEDEC MO-153 TSSOP-8 standard, matches the footprint's own name and the real part's confirmed TSSOP-8 package (verified via LCSC earlier this project). | 93% | 2026-09-20 |
| TI | TPS2121RUXR | C485916 | U1,U2,U3 | VQFN-12 2.5×2.0mm / same | `kicad_gx_library:VQFN-HR-12_L2.5-W2.0-P0.50-BL` | kicad_gx_library (easyeda2kicad) | Body envelope (2.5×2.0mm) and pitch (0.5mm) match this project's own already-researched TI package spec for this exact part (`ic_inventory.md`: "VQFN-12 (2.5×2.0mm)"). Pad-level detail (mixed side/thermal pad shapes) is plausible for TI's small "RUX" QFN variant but wasn't independently re-derived pin-by-pin from TI's own mechanical drawing this pass. | 80% | 2026-09-20 |
| ALJ | 8205A | C22458966 | Q2 | SOT-23-6 / same | `digikey-kicad-library:SOT23-6L` | other (vendored digikey-kicad-library, non-stock) | Standard 0.95mm-pitch SOT-23-6, footprint's own embedded description cites ST's generic SOT-23-6 mechanical reference (CD00047494) — a well-known industry-standard shape; 8205A is a common SOT-23-6 dual MOSFET. | 90% | 2026-09-20 |
| TI | PCA9555PWR | C2864778 | U15 | TSSOP-24 / same | `Package_SO:TSSOP-24_4.4x7.8mm_P0.65mm` | stock | Genuine stock KiCad symbol+footprint (`Interface_Expansion:PCA9555PW`), standard JEDEC TSSOP-24 pitch/body. Not a `kicad_gx_library` part despite initial suspicion. | 97% | 2026-09-20 |
| WCH | CH334R | C4154405 | U11 | QSOP-16 / same | `Package_SO:QSOP-16_3.9x4.9mm_P0.635mm` | stock | Standard QSOP-16, 0.635mm pitch matches JEDEC MO-137. | 95% | 2026-09-20 |
| WCH | CH340C | C84681 | U13 | SOIC-16 / same | `Package_SO:SOIC-16_3.9x9.9mm_P1.27mm` | stock | Standard SOIC-16. | 96% | 2026-09-20 |
| NXP | PCF8563T/5,518 | C7440 | U14 | SOIC-8 / same | `Package_SO:SOIC-8_3.9x4.9mm_P1.27mm` | stock | Standard SOIC-8, matches NXP's real package. | 97% | 2026-09-20 |
| MAXIM (ADI) | MAX17320G22+ | C2914309 | U5 | TQFN-24-1EP 4x4mm EP2.1x2.1mm / same | `Package_DFN_QFN:TQFN-24-1EP_4x4mm_P0.5mm_EP2.1x2.1mm` | stock | Exact-EP-size match already independently confirmed in this project's history (`3d_models.md`). | 97% | 2026-09-20 |
| Espressif | ESP32-S3-WROOM-1-N8R8 | C2913201 | U10 | RF module / same | `RF_Module:ESP32-S3-WROOM-1` | stock | Stock KiCad footprint specifically for this exact module family. | 96% | 2026-09-20 |
| Yajingxin | TXM12M0004252DBCEO00T | C284154 | Y1 | SMD 2520 crystal / same | `Crystal:Crystal_SMD_2520-4Pin_2.5x2.0mm` | stock | Standard 2520 4-pad crystal footprint, plausible for a 12MHz SMD crystal of this class; not independently re-derived from Yajingxin's own drawing this pass. | 85% | 2026-09-20 |
| NDK | NX3215SA-32.768K-STD-MUA-9 | C519280 | Y2 | 3215 2-pad tuning fork / same | `Crystal:Crystal_SMD_3215-2Pin_3.2x1.5mm` | stock | NDK's own part-number prefix "NX3215" directly encodes the 3.2×1.5mm package — exact name-embedded match, this is NDK's textbook standard package for this part family. | 96% | 2026-09-20 |
| TI | LM1117IMPX-3.3/NOPB | C23984 | U9,U12 | SOT-223-3/4 / same | `Package_TO_SOT_SMD:SOT-223` | stock | 4-pad layout (3 small leads + 1 large tab) matches TI's own datasheet package table for the DCY/SOT-223 variant (independently read this project's history — "DCY (SOT-223, 4)", 6.50×3.50mm body). Already package-confirmed via a live TI datasheet read earlier this session. | 95% | 2026-09-20 |
| TI | LM1085IS-5.0RG | C2865978 | U8 | TO-263-3 / same | `Package_TO_SOT_SMD:TO-263-3_TabPin2` | stock | Exact-match 3D model already independently confirmed in this project's history (`3d_models.md`). | 96% | 2026-09-20 |
| TI | TPS563201DDCR | C116592 | U6,U7 | SOT-23-6 / same | `Package_TO_SOT_SMD:SOT-23-6` | stock | Standard, well-known TI buck-converter SOT-23-6 package. | 95% | 2026-09-20 |
| XKB Connection | DSHP04TS-S | C319050 | SW4 | 4-position DIP slide / same | `Button_Switch_SMD:SW_DIP_SPSTx04_Slide_KingTek_DSHP04TS_W7.62mm_P1.27mm` | stock | Footprint name is the exact KingTek part number this session already directly confirmed against (earlier conversation: "Does C319050 match with...DSHP04TS..." — confirmed yes). | 95% | 2026-09-20 |
| Korean Hroparts Elec | K2-1102SP-A4SC-04 | C83916 | SW1,SW2,SW3,SW7,SW8,SW9,SW10 | SMD tact switch / plausible generic match | `Button_Switch_SMD:SW_SPST_PTS645Sx43SMTR92` | stock | Uses the common "PTS645"-style generic tact-switch footprint name for a different manufacturer's (Korean Hroparts) compatible part — a very standard, widely-reused footprint convention for this switch shape, but not an exact vendor-name match like most other rows here. | 80% | 2026-09-20 |
| onsemi | MMBT2222ALT1G | C82460 | Q3,Q4 | SOT-23 / same | `Package_TO_SOT_SMD:SOT-23` | stock | Classic SOT-23 BJT, standard. | 95% | 2026-09-20 |
| AOS | AO3407A | C15155 | Q5,Q8 | SOT-23 / same | `Package_TO_SOT_SMD:SOT-23` | stock | Standard SOT-23 MOSFET package. | 94% | 2026-09-20 |
| AOS | AO3400A | C20917 | Q1 | SOT-23 / same | `Package_TO_SOT_SMD:SOT-23` | stock | Same family. | 94% | 2026-09-20 |
| onsemi | BSS138LT1G | C82045 | Q6,Q7 | SOT-23 / same | `Package_TO_SOT_SMD:SOT-23` | stock | Package directly confirmed via LCSC earlier this session (SOT-23). | 96% | 2026-09-20 |

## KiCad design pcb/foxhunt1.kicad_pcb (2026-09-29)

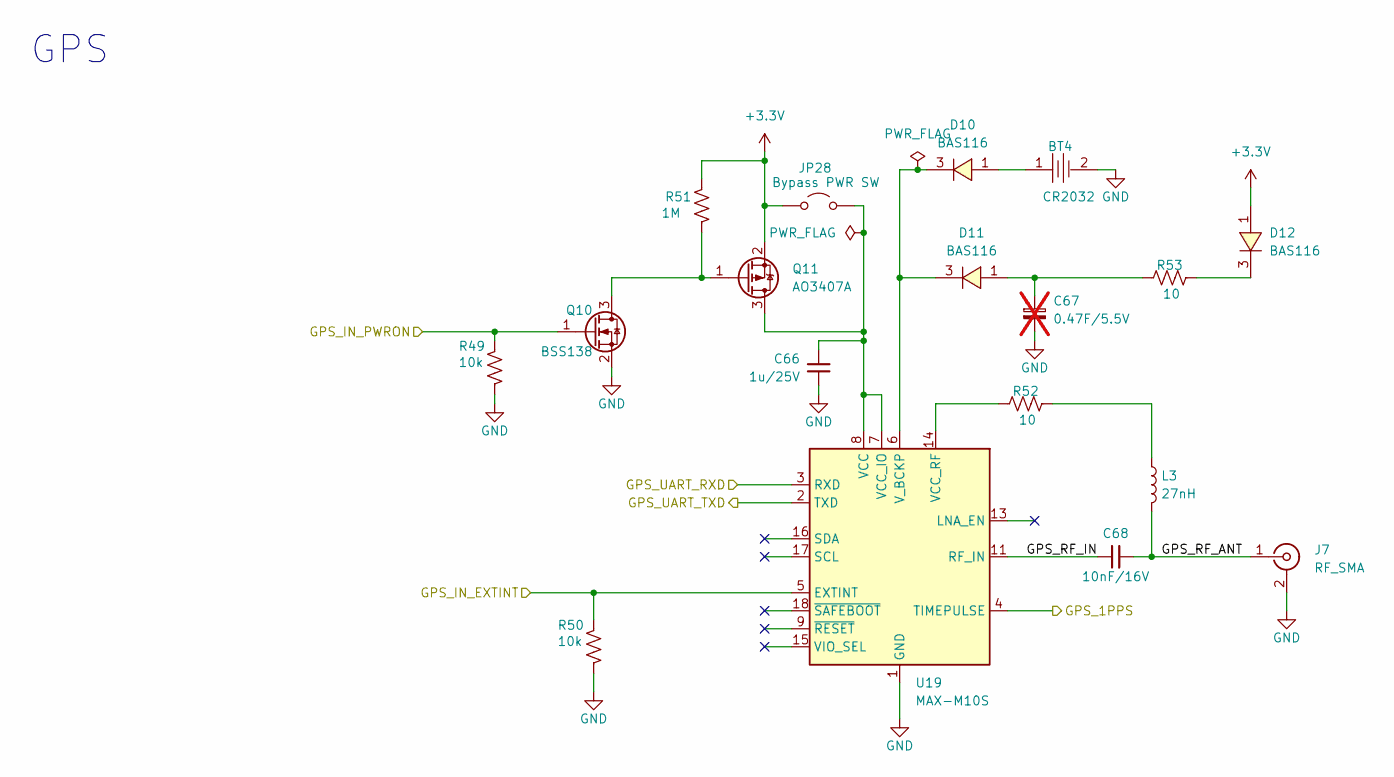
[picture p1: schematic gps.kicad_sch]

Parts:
BT4: CR2032; BAT-SMD_BS-08-B2AA016; MPN BS-08-B2AA020-R; LCSC Part C964787
C66: 1u/25V; C_0805_2012Metric; MPN GRM21BR71H105KA12L; LCSC Part # C77083
C67: 0.47F/5.5V; CP_Supercap_EDC474Z5R5V_0.2x5mm; MPN EDC474Z5R5V; LCSC Part # N/A; not fitted
C68: 10nF/16V; C_0603_1608Metric; MPN GRM188R71H103KA01D; LCSC Part # C77053
D10, D11, D12: BAS116; SOT-23_L2.9-W1.3-P1.90-LS2.4-BR; MPN BAS116LT1G; LCSC Part # C232527
J7: RF_SMA; SMA_Amphenol_132134-11_Vertical; MPN 132289; LCSC Part # C3172723
JP28: Bypass PWR SW; TestPoint_2Pads_Pitch2.54mm_Drill0.8mm
L3: 27nH; L_0402_1005Metric; MPN LQG15HS27NG02D; LCSC Part # C3910610
Q10: BSS138; SOT-23
Q11: AO3407A; SOT-23; MPN AO3407A; LCSC Part # C15155
R49, R50: 10k; R_0603_1608Metric; MPN RT0603BRD0710KL; LCSC Part # C95204
R51: 1M; R_0603_1608Metric; MPN RC0603FR-071ML; LCSC Part # C105578
R52: 10; R_1206_3216Metric; MPN RC1206FR-0710RL; LCSC Part # C108080
R53: 10; R_0603_1608Metric; MPN RC0603FR-0710RL; LCSC Part # C109318
U19: MAX-M10S; ublox_MAX; MPN MAX-M10S-00B; LCSC Part # C4153167

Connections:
+3.3V: D12.1, JP28.1 (A), Q11.2 (S), R51.2; also elsewhere on the board
/GPS/GPS_1PPS: U19.4 (TIMEPULSE); also elsewhere on the board
/GPS/GPS_IN_EXTINT: R50.2, U19.5 (EXTINT); also elsewhere on the board
/GPS/GPS_IN_PWRON: Q10.1 (G), R49.2; also elsewhere on the board
/GPS/GPS_RF_ANT: C68.2, J7.1 (In), L3.2
/GPS/GPS_RF_IN: C68.1, U19.11 (RF_IN)
/GPS/GPS_UART_RXD: U19.3 (RXD); also elsewhere on the board
/GPS/GPS_UART_TXD: U19.2 (TXD); also elsewhere on the board
GND: BT4.2, C66.2, C67.2, J7.2 (Ext), Q10.2 (S), R49.1, R50.1, U19.1 (GND), U19.10 (GND), U19.12 (GND); also elsewhere on the board
unnamed: BT4.1, D10.1
unnamed: C67.1, D11.1, R53.2
unnamed: D12.3, R53.1
unnamed: C66.1, JP28.2 (B), Q11.3 (D), U19.7 (VCC_IO), U19.8 (VCC)
unnamed: L3.1, R52.1
unnamed: Q10.3 (D), Q11.1 (G), R51.1
unnamed: R52.2, U19.14 (VCC_RF)
unnamed: D10.3, D11.3, U19.6 (V_BCKP)

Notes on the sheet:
GPS

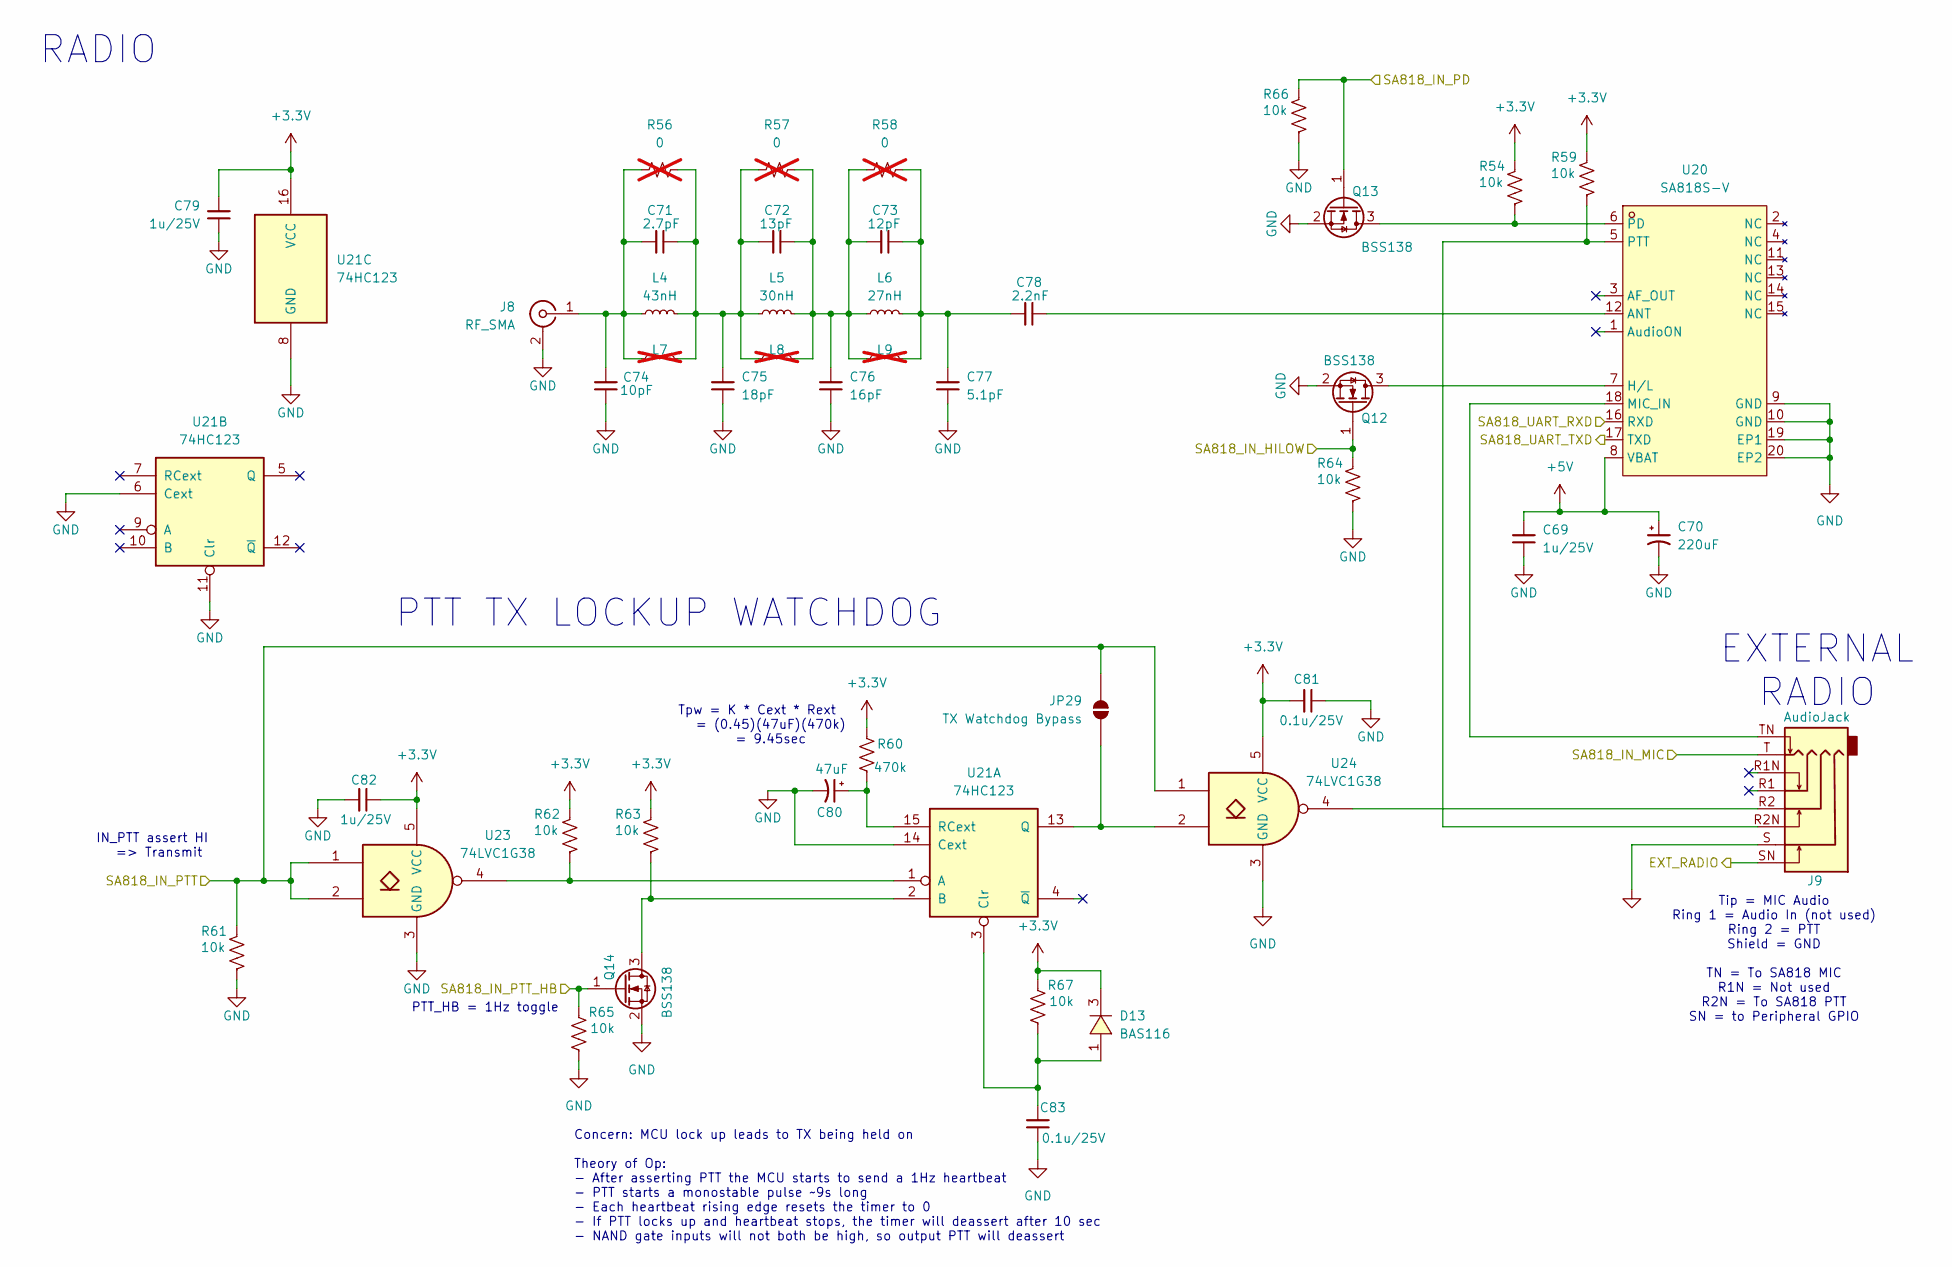
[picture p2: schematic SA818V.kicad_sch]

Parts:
C69, C79, C82: 1u/25V; C_0805_2012Metric; MPN GRM21BR71H105KA12L; LCSC Part # C77083
C70: 220uF; CP_Elec_6.3x7.7; MPN DMBJ; LCSC Part # C970695
C71: 2.7pF; C_0603_1608Metric_Pad1.08x0.95mm_HandSolder; MPN GRM1885C1H2R7BA01D; LCSC Part # C162221
C72: 13pF; C_0201_0603Metric_Pad0.64x0.40mm_HandSolder; MPN 0603CG130J500NT; LCSC Part # C34243
C73: 12pF; C_0603_1608Metric_Pad1.08x0.95mm_HandSolder; MPN 0603CG120J500NT; LCSC Part # C1642
C74: 10pF; C_0603_1608Metric_Pad1.08x0.95mm_HandSolder; MPN GRM1885C1H100JA01D; LCSC Part # C84498
C75: 18pF; C_0603_1608Metric_Pad1.08x0.95mm_HandSolder; MPN 0603CG180J500NT; LCSC Part # C92671
C76: 16pF; C_0603_1608Metric_Pad1.08x0.95mm_HandSolder; MPN 0603CG160J500NT; LCSC Part # C1646
C77: 5.1pF; C_0603_1608Metric_Pad1.08x0.95mm_HandSolder; MPN GRM1885C1H5R1CA01D; LCSC Part # C6955114
C78: 2.2nF; C_0603_1608Metric_Pad1.08x0.95mm_HandSolder; MPN GRM1885C1H222JA01J; LCSC Part # C2168957
C80: 47uF; CP-SMD_1206_L3.2-W1.6-FD; MPN TMCMA1A476MTRF; LCSC Part # C4984790
C81, C83: 0.1u/25V; C_0603_1608Metric; MPN GRM188R71H104KA93D; LCSC Part # C77055
D13: BAS116; SOT-23_L2.9-W1.3-P1.90-LS2.4-BR; MPN BAS116LT1G; LCSC Part # C232527
J8: RF_SMA; SMA_Amphenol_132134-11_Vertical; MPN 132289; LCSC Part # C3172723
J9: AudioJack; Jack_SJ-43617-SMT-TR; MPN SJ-43617-SMT-TR; Digikey CP-43617SJTR-ND
JP29: TX Watchdog Bypass; SolderJumper-2_P1.3mm_Open_TrianglePad1.0x1.5mm
L4: 43nH; L_0805_2012Metric_Pad1.05x1.20mm_HandSolder; MPN LQW2BAN43NG00L; LCSC Part # C1330253
L5: 30nH; L_0805_2012Metric_Pad1.05x1.20mm_HandSolder; MPN LQW2BAN30NG00L; LCSC Part # C3221803
L6: 27nH; L_0805_2012Metric_Pad1.05x1.20mm_HandSolder; MPN LQW2BAN27NJ00L; LCSC Part # C1330812
L7, L8, L9: L_0603_1608Metric; not fitted
Q12, Q13, Q14: BSS138; SOT-23
R54, R59, R61, R62, R63, R64, R65, R66, R67: 10k; R_0603_1608Metric; MPN RT0603BRD0710KL; LCSC Part # C95204
R56, R57, R58: 0; R_0603_1608Metric; MPN RC0603JR-070RL; LCSC Part # C95177; not fitted
R60: 470k; R_0603_1608Metric; MPN RC0603FR-07470KL; LCSC Part # C114622
U20: SA818S-V; WIRELM-SMD_G-NICERF_SA818S-X; MPN SA818S-V; LCSC Part C51897911
U21: 74HC123; SOIC-16_3.9x9.9mm_P1.27mm; MPN 74HC123D,653; LCSC Part # C5597
U23, U24: 74LVC1G38; SOT-23-5; MPN SN74LVC1G38DBVR; LCSC Part # C2867613

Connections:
+3.3V: C79.1, C81.1, C82.1, D13.3, R54.2, R59.2, R60.1, R62.2, R63.2, R67.2, U21.16 (VCC), U23.5 (VCC), U24.5 (VCC); also elsewhere on the board
+5V: C69.1, C70.1, U20.8 (VBAT); also elsewhere on the board
/Audio/I2S_MIC_OUT: J9.T; also elsewhere on the board
/Peripherals/PERIPH_OUT_SA818_HILOW: Q12.1 (G), R64.2; also elsewhere on the board
/Peripherals/PERIPH_OUT_SA818_PD: Q13.1 (G), R66.2; also elsewhere on the board
/SA818S-V/EXT_RADIO: J9.SN; also elsewhere on the board
/SA818S-V/SA818_IN_PTT: JP29.2 (B), R61.2, U23.1, U23.2, U24.1; also elsewhere on the board
/SA818S-V/SA818_IN_PTT_HB: Q14.1 (G), R65.2; also elsewhere on the board
/SA818S-V/SA818_UART_RXD: U20.16 (RXD); also elsewhere on the board
/SA818S-V/SA818_UART_TXD: U20.17 (TXD); also elsewhere on the board
GND: C69.2, C70.2, C74.1, C75.1, C76.1, C77.1, C79.2, C80.2, C81.2, C82.2, C83.1, J8.2 (Ext), J9.S, Q12.2 (S), Q13.2 (S), Q14.2 (S), R61.1, R64.1, R65.1, R66.1, U20.9 (GND), U20.10 (GND), U20.19 (EP1), U20.20 (EP2), U21.6 (Cext), U21.8 (GND), U21.11 (Clr), U21.14 (Cext), U23.3 (GND), U24.3 (GND); also elsewhere on the board
unnamed: C71.2, C72.1, C75.2, L4.2, L5.1, L7.2, L8.1, R56.2, R57.1
unnamed: C72.2, C73.1, C76.2, L5.2, L6.1, L8.2, L9.1, R57.2, R58.1
unnamed: C73.2, C77.2, C78.1, L6.2, L9.2, R58.2
unnamed: C71.1, C74.2, J8.1 (In), L4.1, L7.1, R56.1
unnamed: J9.R2, U24.4
unnamed: JP29.1 (A), U21.13 (Q), U24.2
unnamed: Q12.3 (D), U20.7 (H/L)
unnamed: Q13.3 (D), R54.1, U20.6 (PD)
unnamed: Q14.3 (D), R63.1, U21.2 (B)
unnamed: C78.2, U20.12 (ANT)
unnamed: J9.TN, U20.18 (MIC_IN)
unnamed: J9.R2N, R59.1, U20.5 (PTT)
unnamed: R62.1, U21.1 (A), U23.4
unnamed: C83.2, D13.1, R67.1, U21.3 (Clr)
unnamed: C80.1, R60.2, U21.15 (RCext)

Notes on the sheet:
IN_PTT assert HI => Transmit
Tip = MIC Audio Ring 1 = Audio In (not used) Ring 2 = PTT Shield = GND TN = To SA818 MIC R1N = Not used R2N = To SA818 PTT SN = to Peripheral GPIO
EXTERNAL RADIO
Tpw = K * Cext * Rext = (0.45)(47uF)(470k) = 9.45sec
PTT_HB = 1Hz toggle
RADIO
PTT TX LOCKUP WATCHDOG
Concern: MCU lock up leads to TX being held on Theory of Op: - After asserting PTT the MCU starts to send a 1Hz heartbeat - PTT starts a monostable pulse ~9s long - Each heartbeat rising edge resets the timer to 0 - If PTT locks up and heartbeat stops, the timer will deassert after 10 sec - NAND ga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

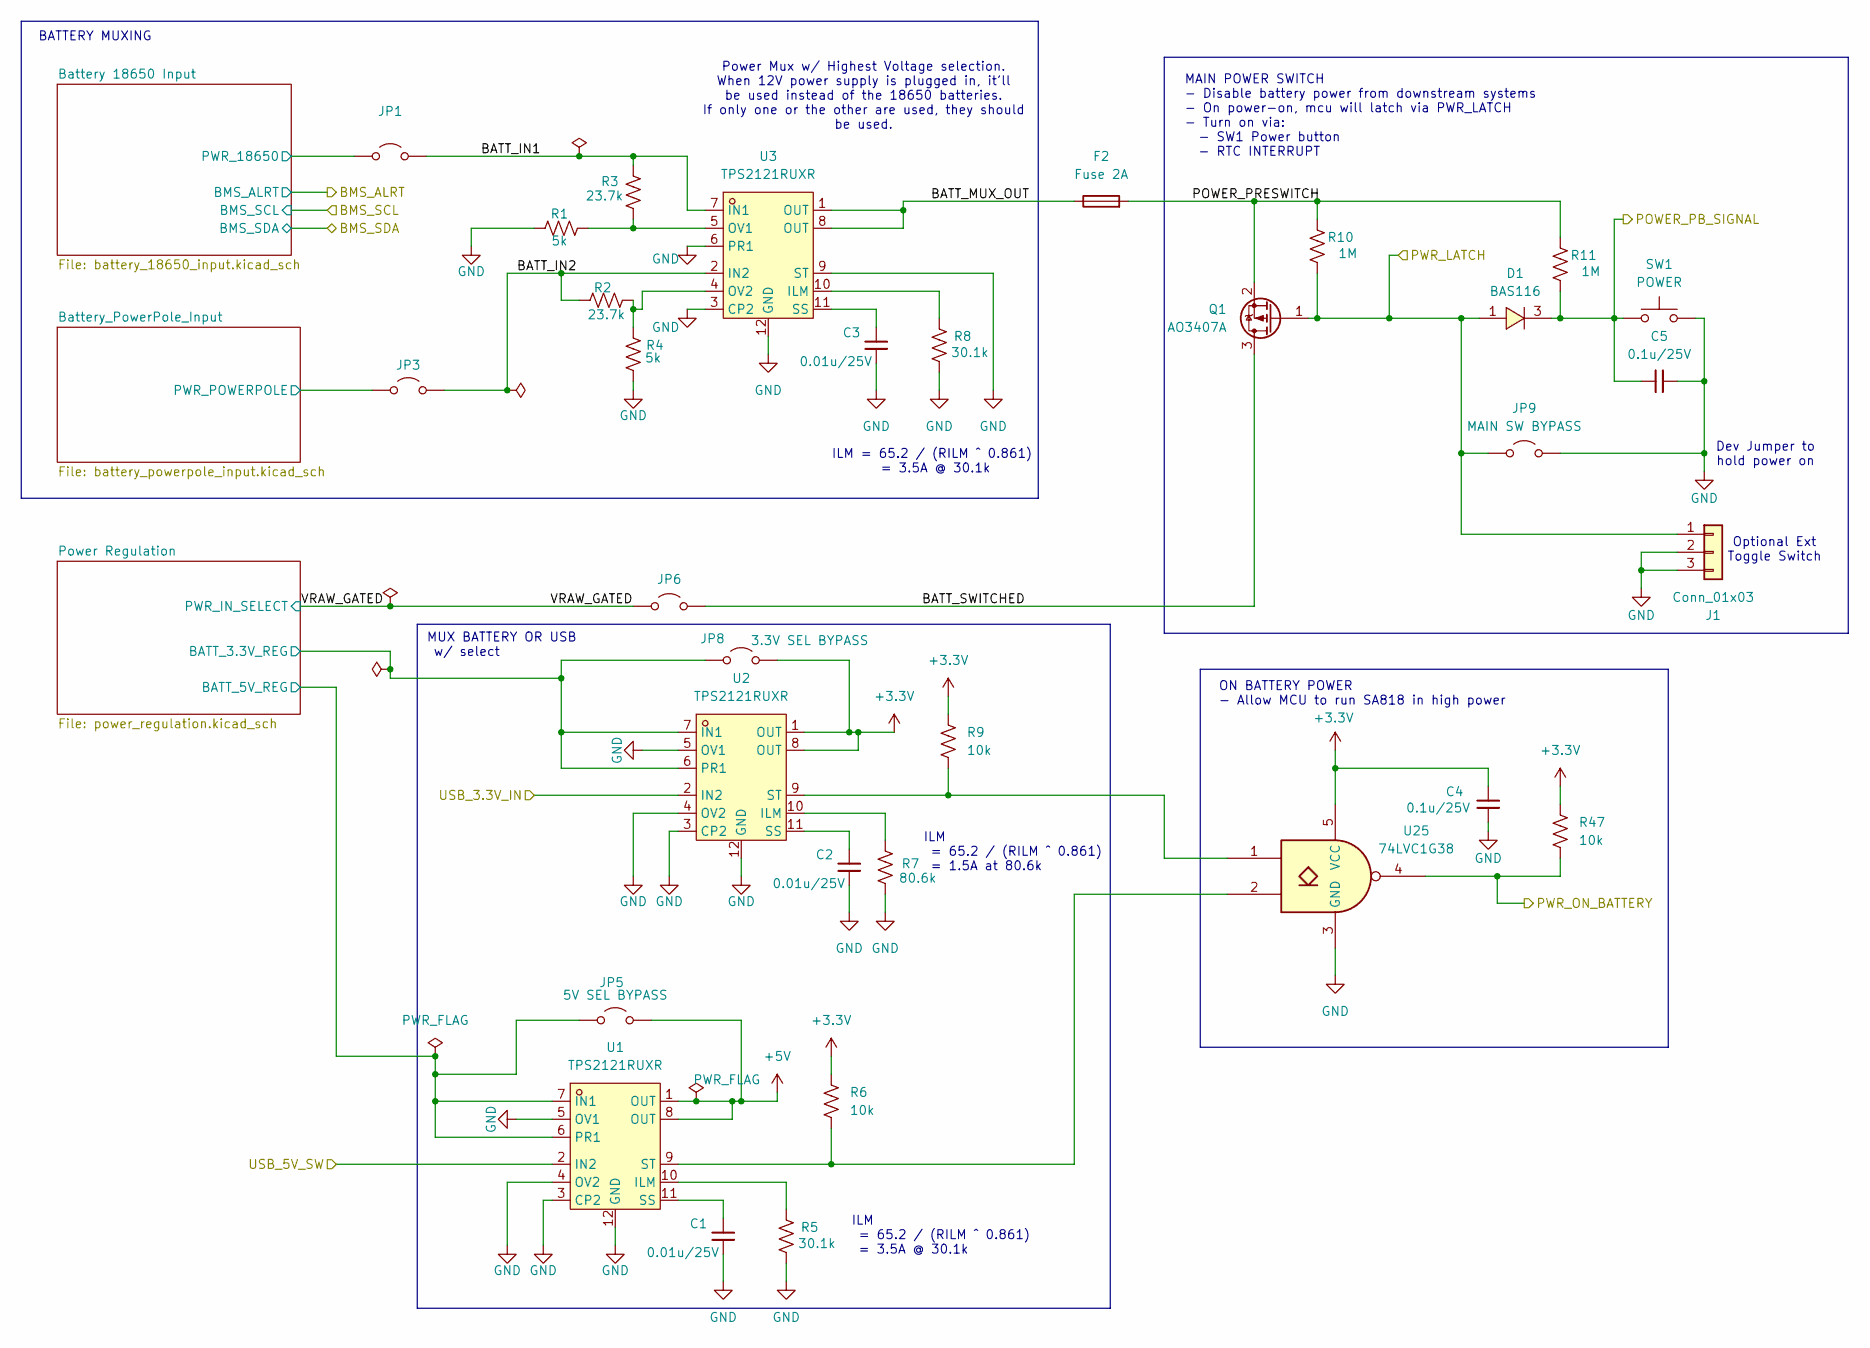
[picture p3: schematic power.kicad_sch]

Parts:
C1, C2, C3: 0.01u/25V; C_0603_1608Metric; MPN GRM1885C1H103JA01D; LCSC Part # C85973
C4, C5: 0.1u/25V; C_0603_1608Metric; MPN GRM188R71H104KA93D; LCSC Part # C77055
D1: BAS116; SOT-23_L2.9-W1.3-P1.90-LS2.4-BR; MPN BAS116LT1G; LCSC Part # C232527
F2: Fuse 2A; Fuse_MCCQ-122; MPN MCCQ-122
J1: Conn_01x03; JST_PH_B3B-PH-SM4-TB_1x03-1MP_P2.00mm_Vertical; MPN B3B-PH-SM4-TB(LF)(SN); LCSC Part # C160353
JP1: BATT IN ISO; TestPoint_2Pads_Pitch2.54mm_Drill0.8mm
JP3: 12V IN ISO; TestPoint_2Pads_Pitch2.54mm_Drill0.8mm
JP5: 5V SEL BYPASS; TestPoint_2Pads_Pitch2.54mm_Drill0.8mm
JP6: PWR ISO; TestPoint_2Pads_Pitch2.54mm_Drill0.8mm
JP8: 3.3V SEL BYPASS; TestPoint_2Pads_Pitch2.54mm_Drill0.8mm
JP9: MAIN SW BYPASS; TestPoint_2Pads_Pitch2.54mm_Drill0.8mm
Q1: AO3407A; SOT-23; MPN AO3407A; LCSC Part # C15155
R1, R4: 5k; R_0201_0603Metric; MPN RT0603BRE075KL; LCSC Part # C862232
R2, R3: 23.7k; R_0603_1608Metric; MPN 0603WAF2372T5E; LCSC Part # C22912
R5, R8: 30.1k; R_0603_1608Metric; MPN RC0603FR-0730K1L; LCSC Part # C137745
R6, R9, R47: 10k; R_0603_1608Metric; MPN RT0603BRD0710KL; LCSC Part # C95204
R7: 80.6k; R_0603_1608Metric; MPN RT0603BRE0780K6L; LCSC Part # C862291
R10: 1M; R_0603_1608Metric; MPN RC0603FR-071ML; LCSC Part # C105578
R11: 1M; R_0603_1608Metric; MPN RC0603JR-071ML; LCSC Part # C107698
SW1: POWER; SW_SPST_PTS645Sx43SMTR92; MPN K2-1102SP-A4SC-04; LCSC Part # C83916
U1, U2, U3: TPS2121RUXR; VQFN-HR-12_L2.5-W2.0-P0.50-BL; MPN TPS2121RUXR; LCSC Part # C485916
U25: 74LVC1G38; SOT-23-5; MPN SN74LVC1G38DBVR; LCSC Part # C2867613

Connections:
+3.3V: C4.1, JP8.2 (B), R6.2, R9.2, R47.2, U2.1 (OUT), U2.8 (OUT), U25.5 (VCC); also elsewhere on the board
+5V: JP5.2 (B), U1.1 (OUT), U1.8 (OUT); also elsewhere on the board
/Peripherals/RTC_OUT_INTERRUPT_LATCH: D1.1, J1.1, JP9.1 (A), Q1.1 (G), R10.1; also elsewhere on the board
/Power/BATT_IN1: JP1.2 (B), R3.2, U3.7 (IN1)
/Power/BATT_IN2: JP3.2 (B), R2.2, U3.2 (IN2)
/Power/BATT_MUX_OUT: F2.1, U3.1 (OUT), U3.8 (OUT)
/Power/BATT_SWITCHED: JP6.2 (B), Q1.3 (D)
/Power/Battery 18650 Input/PWR_18650: JP1.1 (A); also elsewhere on the board
/Power/Battery_PowerPole_Input/PWR_POWERPOLE: JP3.1 (A); also elsewhere on the board
/Power/POWER_PB_SIGNAL: C5.1, D1.3, R11.1, SW1.2; also elsewhere on the board
/Power/POWER_PRESWITCH: F2.2, Q1.2 (S), R10.2, R11.2
/Power/PWR_ON_BATTERY: R47.1, U25.4; also elsewhere on the board
/Power/Power Regulation/BATT_3.3V_REG: JP8.1 (A), U2.6 (PR1), U2.7 (IN1); also elsewhere on the board
/Power/Power Regulation/BATT_5V_REG: JP5.1 (A), U1.6 (PR1), U1.7 (IN1); also elsewhere on the board
/Power/USB_3.3V_IN: U2.2 (IN2); also elsewhere on the board
/Power/USB_5V_SW: U1.2 (IN2); also elsewhere on the board
/Power/VRAW_GATED: JP6.1 (A); also elsewhere on the board
GND: C1.2, C2.2, C3.2, C4.2, C5.2, J1.2, J1.3, JP9.2 (B), R1.1, R4.1, R5.1, R7.1, R8.1, SW1.1, U1.3 (CP2), U1.4 (OV2), U1.5 (OV1), U1.12 (GND), U2.3 (CP2), U2.4 (OV2), U2.5 (OV1), U2.12 (GND), U3.3 (CP2), U3.6 (PR1), U3.9 (ST), U3.12 (GND), U25.3 (GND); also elsewhere on the board
unnamed: R5.2, U1.10 (ILM)
unnamed: C1.1, U1.11 (SS)
unnamed: R6.1, U1.9 (ST), U25.2
unnamed: R7.2, U2.10 (ILM)
unnamed: C2.1, U2.11 (SS)
unnamed: R9.1, U2.9 (ST), U25.1
unnamed: R8.2, U3.10 (ILM)
unnamed: R1.2, R3.1, U3.5 (OV1)
unnamed: R2.1, R4.2, U3.4 (OV2)
unnamed: C3.1, U3.11 (SS)

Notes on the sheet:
ILM = 65.2 / (RILM ^ 0.861) = 1.5A at 80.6k
Optional Ext Toggle Switch
Dev Jumper to hold power on
Power Mux w/ Highest Voltage selection. When 12V power supply is plugged in, it'll be used instead of the 18650 batteries. If only one or the other are used, they should be used.
ON BATTERY POWER - Allow MCU to run SA818 in high power
ILM = 65.2 / (RILM ^ 0.861) = 3.5A @ 30.1k
MUX BATTERY OR USB w/ select
ILM = 65.2 / (RILM ^ 0.861) = 3.5A @ 30.1k
BATTERY MUXING
MAIN POWER SWITCH - Disable battery power from downstream systems - On power-on, mcu will latch via PWR_LATCH - Turn on via: - SW1 Power button - RTC INTERRUPT

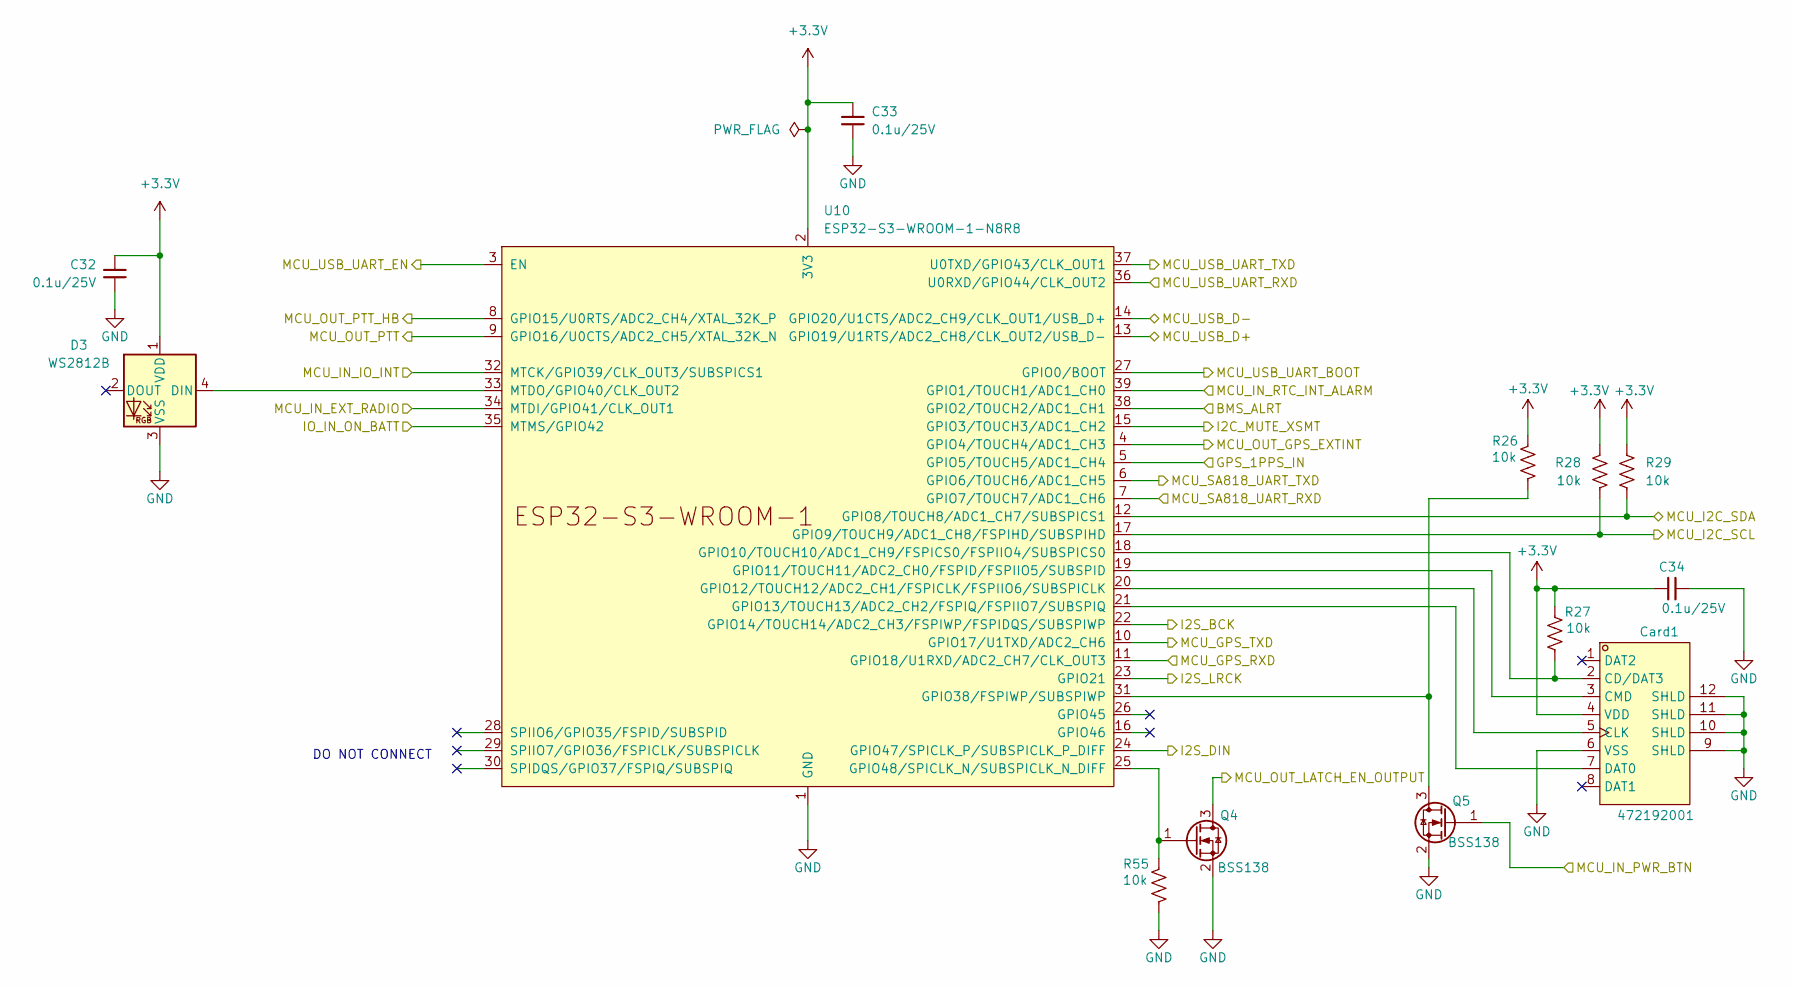
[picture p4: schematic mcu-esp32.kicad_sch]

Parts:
C32, C33, C34: 0.1u/25V; C_0603_1608Metric; MPN GRM188R71H104KA93D; LCSC Part # C77055
Card1: 472192001; TF-SMD_472192001; MPN 472192001; LCSC Part # C164170
D3: WS2812B; LED_WS2812B_PLCC4_5.0x5.0mm_P3.2mm; MPN WS2812B-B/W; LCSC Part # C114586
Q4, Q5: BSS138; SOT-23
R26, R27, R28, R29, R55: 10k; R_0603_1608Metric; MPN RT0603BRD0710KL; LCSC Part # C95204
U10: ESP32-S3-WROOM-1-N8R8; ESP32-S3-WROOM-1; MPN ESP32-S3-WROOM-1-N8R8; LCSC Part # C2913201

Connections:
+3.3V: C32.1, C33.1, C34.1, Card1.4 (VDD), D3.1 (VDD), R26.2, R27.2, R28.2, R29.2, U10.2 (3V3); also elsewhere on the board
/Audio/I2S_BCK: U10.22 (GPIO14/TOUCH14/ADC2_CH3/FSPIWP/FSPIDQS/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); also elsewhere on the board
/Audio/I2S_DIN: U10.24 (GPIO47/SPICLK_P/SUBSPICLK_P_DIFF); also elsewhere on the board
/Audio/I2S_LRCK: U10.23 (GPIO21); also elsewhere on the board
/Audio/I2S_XSMT: U10.15 (GPIO3/TOUCH3/ADC1_CH2); also elsewhere on the board
/GPS/GPS_1PPS: U10.5 (GPIO5/TOUCH5/ADC1_CH4); also elsewhere on the board
/GPS/GPS_IN_EXTINT: U10.4 (GPIO4/TOUCH4/ADC1_CH3); also elsewhere on the board
/GPS/GPS_UART_RXD: U10.10 (GPIO17/U1TXD/ADC2_CH6); also elsewhere on the board
/GPS/GPS_UART_TXD: U10.11 (GPIO18/U1RXD/ADC2_CH7/CLK_OUT3); also elsewhere on the board
/Peripherals/PERIPH_IO_INT: U10.32 (MTCK/GPIO39/CLK_OUT3/SUBSPICS1); also elsewhere on the board
/Peripherals/PERIPH_SCL: R28.1, U10.17 (GPIO9/TOUCH9/ADC1_CH8/FSPIHD/SUBSPIHD); also elsewhere on the board
/Peripherals/PERIPH_SDA: R29.1, U10.12 (GPIO8/TOUCH8/ADC1_CH7/SUBSPICS1); also elsewhere on the board
/Peripherals/RTC_OUT_INTERRUPT_LATCH: Q4.3 (D); also elsewhere on the board
/Peripherals/RTC_OUT_MCU_INT_ALRM: U10.39 (GPIO1/TOUCH1/ADC1_CH0); also elsewhere on the board
/Power/BMS_ALRT: U10.38 (GPIO2/TOUCH2/ADC1_CH1); also elsewhere on the board
/Power/POWER_PB_SIGNAL: Q5.1 (G); also elsewhere on the board
/Power/PWR_ON_BATTERY: U10.35 (MTMS/GPIO42); also elsewhere on the board
/SA818S-V/EXT_RADIO: U10.34 (MTDI/GPIO41/CLK_OUT1); also elsewhere on the board
/SA818S-V/SA818_IN_PTT: U10.9 (GPIO16/U0CTS/ADC2_CH5/XTAL_32K_N); also elsewhere on the board
/SA818S-V/SA818_IN_PTT_HB: U10.8 (GPIO15/U0RTS/ADC2_CH4/XTAL_32K_P); also elsewhere on the board
/SA818S-V/SA818_UART_RXD: U10.6 (GPIO6/TOUCH6/ADC1_CH5); also elsewhere on the board
/SA818S-V/SA818_UART_TXD: U10.7 (GPIO7/TOUCH7/ADC1_CH6); also elsewhere on the board
/USB-C/MCU_EN_RESET: U10.3 (EN); also elsewhere on the board
/USB-C/MCU_IO0_BOOT: U10.27 (GPIO0/BOOT); also elsewhere on the board
/USB-C/USB_MCU_D+: U10.13 (GPIO19/U1RTS/ADC2_CH8/CLK_OUT2/USB_D-); also elsewhere on the board
/USB-C/USB_MCU_D-: U10.14 (GPIO20/U1CTS/ADC2_CH9/CLK_OUT1/USB_D+); also elsewhere on the board
/USB-C/USB_UART_RXD: U10.37 (U0TXD/GPIO43/CLK_OUT1); also elsewhere on the board
/USB-C/USB_UART_TXD: U10.36 (U0RXD/GPIO44/CLK_OUT2); also elsewhere on the board
GND: C32.2, C33.2, C34.2, Card1.6 (VSS), Card1.9 (SHLD), Card1.10 (SHLD), Card1.11 (SHLD), Card1.12 (SHLD), D3.3 (VSS), Q4.2 (S), Q5.2 (S), R55.1, U10.1 (GND), U10.40 (GND), U10.41 (GND); also elsewhere on the board
unnamed: Card1.2 (CD/DAT3), R27.1, U10.18 (GPIO10/TOUCH10/ADC1_CH9/FSPICS0/FSPIIO4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)
unnamed: Card1.5 (CLK), U10.20 (GPIO12/TOUCH12/ADC2_CH1/FSPICLK/FSPIIO6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)
unnamed: Card1.3 (CMD), U10.19 (GPIO11/TOUCH11/ADC2_CH0/FSPID/FSPIIO5/S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)
unnamed: Card1.7 (DAT0), U10.21 (GPIO13/TOUCH13/ADC2_CH2/FSPIQ/FSPIIO7/S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)
unnamed: D3.4 (DIN), U10.33 (MTDO/GPIO40/CLK_OUT2)
unnamed: Q4.1 (G), R55.2, U10.25 (GPIO48/SPICLK_N/SUBSPICLK_N_DIFF)
unnamed: Q5.3 (D), R26.1, U10.31 (GPIO38/FSPIWP/SUBSPIWP)

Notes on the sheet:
DO NOT CONNECT

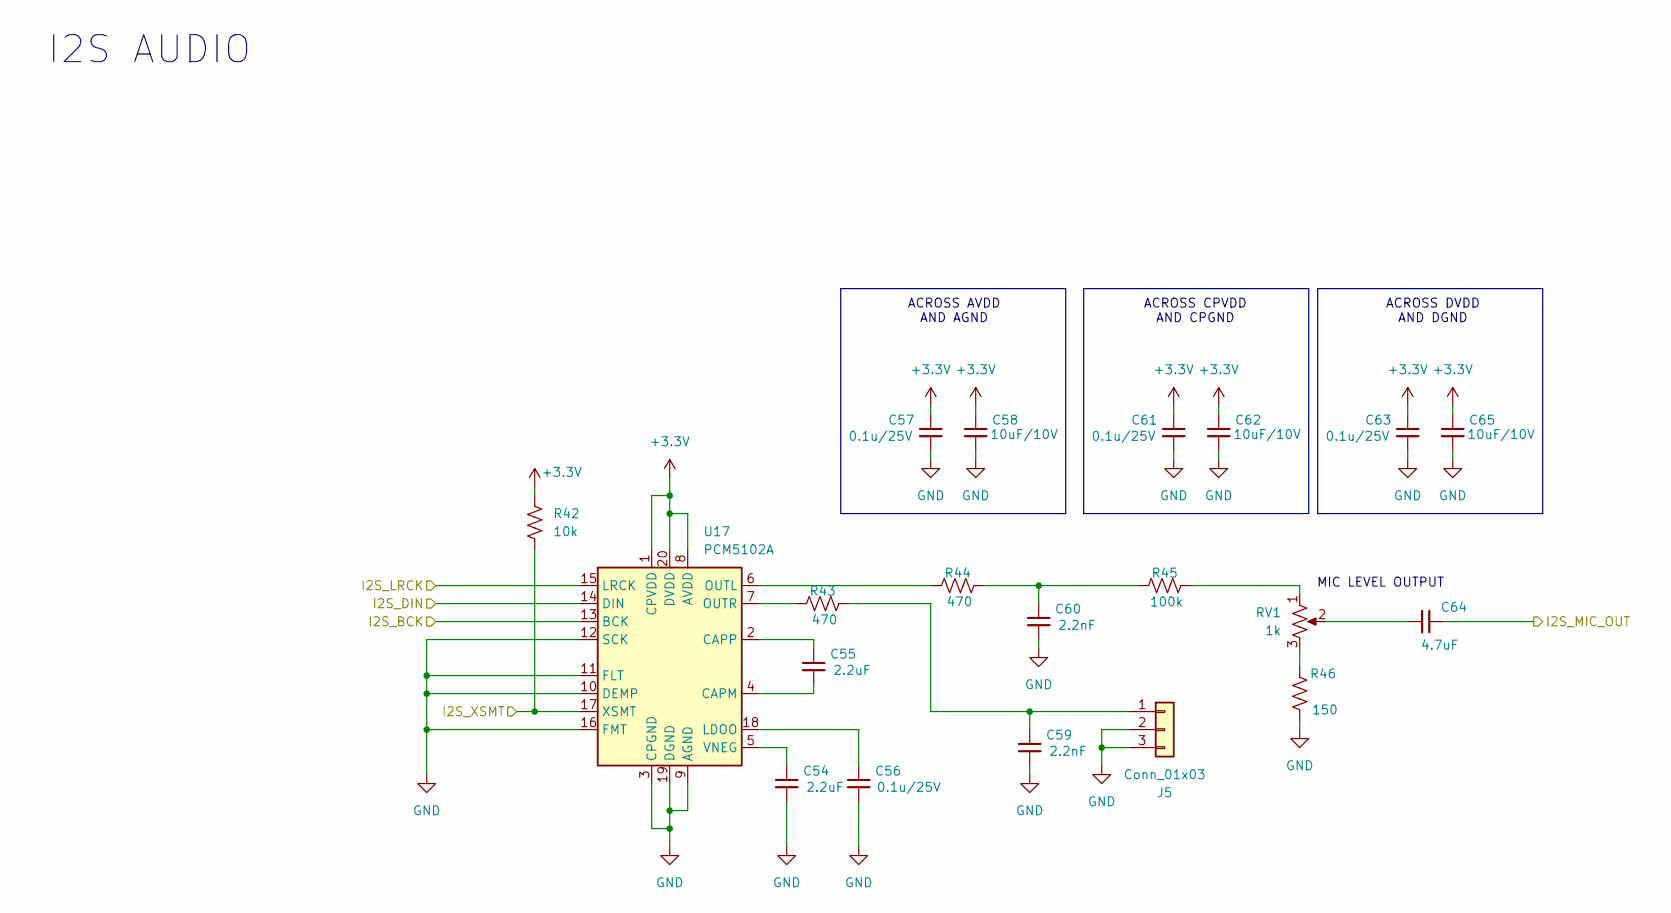
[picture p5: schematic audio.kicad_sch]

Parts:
C54, C55: 2.2uF; C_0603_1608Metric; MPN GRM188Z71E225KE43D; LCSC Part # C415535
C56, C57, C61, C63: 0.1u/25V; C_0603_1608Metric; MPN GRM188R71H104KA93D; LCSC Part # C77055
C58, C62, C65: 10uF/10V; C_0603_1608Metric; MPN GRM188Z71A106KA73D; LCSC Part # C2959727
C59, C60: 2.2nF; C_0603_1608Metric; MPN GCM188R71H104KA57D; LCSC Part # C85864
C64: 4.7uF; C_0603_1608Metric; MPN GRM188Z71A475KE15D; LCSC Part # C913474
J5: Conn_01x03; JST_PH_B3B-PH-SM4-TB_1x03-1MP_P2.00mm_Vertical; MPN B3B-PH-SM4-TB(LF)(SN); LCSC Part # C160353
R42: 10k; R_0603_1608Metric; MPN RT0603BRD0710KL; LCSC Part # C95204
R43, R44: 470; R_0603_1608Metric; MPN RT0603BRD07470RL; LCSC Part # C705779
R45: 100k; R_0603_1608Metric; MPN RC0603FR-07100KL; LCSC Part # C14675
R46: 150; R_0603_1608Metric; MPN RC0603JR-07150RL; LCSC Part # C126805
RV1: 1k; Potentiometer_Bourns_3314G_Vertical; MPN 3314G-1-102E; LCSC Part # C780221
U17: PCM5102A; TSSOP-20_4.4x6.5mm_P0.65mm; MPN PCM5102APWR; LCSC Part # C107671

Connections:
+3.3V: C57.1, C58.1, C61.1, C62.1, C63.1, C65.1, R42.2, U17.1 (CPVDD), U17.8 (AVDD), U17.20 (DVDD); also elsewhere on the board
/Audio/I2S_BCK: U17.13 (BCK); also elsewhere on the board
/Audio/I2S_DIN: U17.14 (DIN); also elsewhere on the board
/Audio/I2S_LRCK: U17.15 (LRCK); also elsewhere on the board
/Audio/I2S_MIC_OUT: C64.1; also elsewhere on the board
/Audio/I2S_XSMT: R42.1, U17.17 (XSMT); also elsewhere on the board
GND: C54.2, C56.2, C57.2, C58.2, C59.2, C60.2, C61.2, C62.2, C63.2, C65.2, J5.2, J5.3, R46.1, U17.3 (CPGND), U17.9 (AGND), U17.10 (DEMP), U17.11 (FLT), U17.12 (SCK), U17.16 (FMT), U17.19 (DGND); also elsewhere on the board
unnamed: C60.1, R44.1, R45.2
unnamed: C64.2, RV1.2
unnamed: C59.1, J5.1, R43.1
unnamed: R45.1, RV1.1
unnamed: R46.2, RV1.3
unnamed: C55.2, U17.4 (CAPM)
unnamed: C55.1, U17.2 (CAPP)
unnamed: C56.1, U17.18 (LDOO)
unnamed: R44.2, U17.6 (OUTL)
unnamed: R43.2, U17.7 (OUTR)
unnamed: C54.1, U17.5 (VNEG)

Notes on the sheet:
ACROSS AVDD AND AGND
ACROSS CPVDD AND CPGND
MIC LEVEL OUTPUT
ACROSS DVDD AND DGND
I2S AUDIO

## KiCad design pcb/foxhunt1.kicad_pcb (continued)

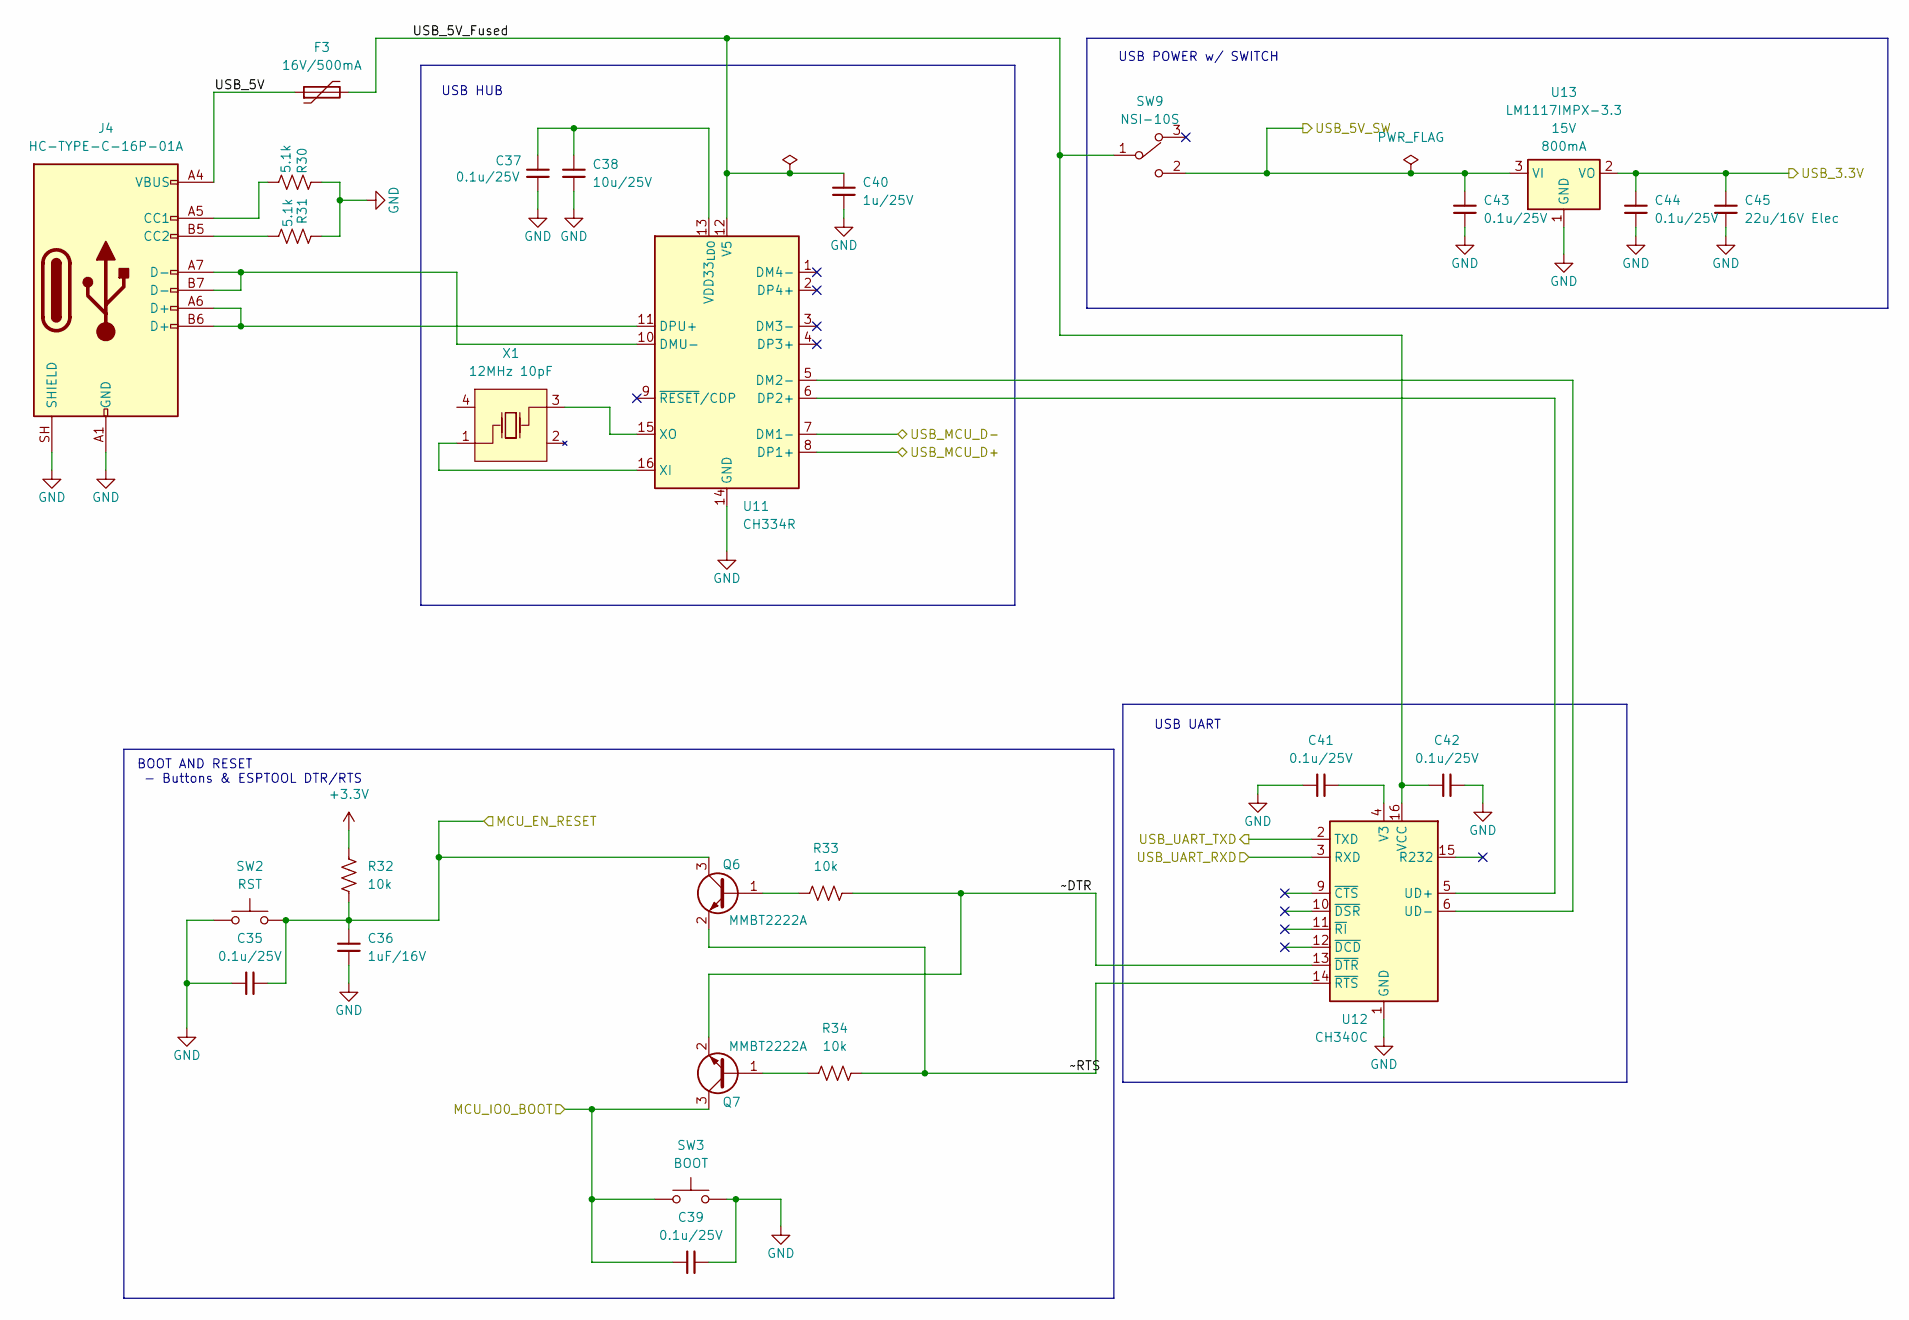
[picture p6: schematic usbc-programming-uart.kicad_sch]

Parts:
C35, C37, C39, C41, C42, C43, C44: 0.1u/25V; C_0603_1608Metric; MPN GRM188R71H104KA93D; LCSC Part # C77055
C36: 1uF/16V; C_0805_2012Metric; MPN GRM21BR71H105KA12L; LCSC Part # C77083
C38: 10u/25V; C_0805_2012Metric; MPN GRM21BZ71E106KE15L; LCSC Part # C237493
C40: 1u/25V; C_0805_2012Metric; MPN GRM21BR71H105KA12L; LCSC Part # C77083
C45: 22u/16V Elec; C_Elec_5x5.8; MPN XT1C220M0506; LCSC Part # C5260805
F3: 16V/500mA; Fuse_0805_2012Metric; MPN 0805L050/16XR; LCSC Part # C22435898
J4: HC-TYPE-C-16P-01A; USB_C_Receptacle_HCTL_HC-TYPE-C-16P-01A; MPN HC-TYPE-C-16P-01A; LCSC Part # C2894897
Q6, Q7: MMBT2222A; SOT-23; MPN MMBT2222ALT1G; LCSC Part # C82460
R30, R31: 5.1k; R_0603_1608Metric; MPN RC0603JR-075K1L; LCSC Part # C14677
R32, R33, R34: 10k; R_0603_1608Metric; MPN RT0603BRD0710KL; LCSC Part # C95204
SW2: RST; SW_SPST_PTS645Sx43SMTR92; MPN K2-1102SP-A4SC-04; LCSC Part # C83916
SW3: BOOT; SW_SPST_PTS645Sx43SMTR92; MPN K2-1102SP-A4SC-04; LCSC Part # C83916
SW9: NSI-10S; SW-SMD_NSI-10S; MPN NSI-10S; LCSC Part C515802
U11: CH334R; QSOP-16_3.9x4.9mm_P0.635mm; MPN CH334R; LCSC Part # C4154405
U12: CH340C; SOIC-16_3.9x9.9mm_P1.27mm; MPN CH340C; LCSC Part # C84681
U13: LM1117IMPX-3.3; SOT-223-3_TabPin2; MPN LM1117IMPX-3.3/NOPB; LCSC Part # C23984
X1: 12MHz 10pF; CRYSTAL-SMD_4P-L2.5-W2.0-BL; MPN TXM12M0004252DBCEO00T; LCSC Part # C284154

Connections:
+3.3V: R32.2; also elsewhere on the board
/Power/USB_3.3V_IN: C44.1, C45.1, U13.2 (VO); also elsewhere on the board
/Power/USB_5V_SW: C43.1, SW9.2, U13.3 (VI); also elsewhere on the board
/USB-C/MCU_EN_RESET: C35.1, C36.1, Q6.3 (C), R32.1, SW2.2; also elsewhere on the board
/USB-C/MCU_IO0_BOOT: C39.1, Q7.3 (C), SW3.2; also elsewhere on the board
/USB-C/USB_5V: F3.1, J4.A4 (VBUS), J4.A9 (VBUS), J4.B4 (VBUS), J4.B9 (VBUS)
/USB-C/USB_5V_Fused: C40.1, C42.1, F3.2, SW9.1, U11.12 (V5), U12.16 (VCC)
/USB-C/USB_MCU_D+: U11.8 (DP1+); also elsewhere on the board
/USB-C/USB_MCU_D-: U11.7 (DM1-); also elsewhere on the board
/USB-C/USB_UART_RXD: U12.3 (RXD); also elsewhere on the board
/USB-C/USB_UART_TXD: U12.2 (TXD); also elsewhere on the board
/USB-C/~DTR: Q7.2 (E), R33.1, U12.13 (~DTR)
/USB-C/~RTS: Q6.2 (E), R34.1, U12.14 (~RTS)
GND: C35.2, C36.2, C37.2, C38.2, C39.2, C40.2, C41.1, C42.2, C43.2, C44.2, C45.2, J4.A1 (GND), J4.A12 (GND), J4.B1 (GND), J4.B12 (GND), J4.SH (SHIELD), R30.1, R31.1, SW2.1, SW3.1, U11.14 (GND), U12.1 (GND), U13.1 (GND); also elsewhere on the board
unnamed: J4.A5 (CC1), R30.2
unnamed: J4.B5 (CC2), R31.2
unnamed: Q6.1 (B), R33.2
unnamed: Q7.1 (B), R34.2
unnamed: U11.5 (DM2-), U12.6 (UD-)
unnamed: J4.A7 (D-), J4.B7 (D-), U11.10 (DMU-)
unnamed: U11.6 (DP2+), U12.5 (UD+)
unnamed: J4.A6 (D+), J4.B6 (D+), U11.11 (DPU+)
unnamed: C37.1, C38.1, U11.13 (VDD33_{LDO})
unnamed: U11.16 (XI), X1.1
unnamed: U11.15 (XO), X1.3
unnamed: C41.2, U12.4 (V3)

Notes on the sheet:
USB UART
BOOT AND RESET - Buttons & ESPTOOL DTR/RTS
USB HUB
USB POWER w/ SWITCH

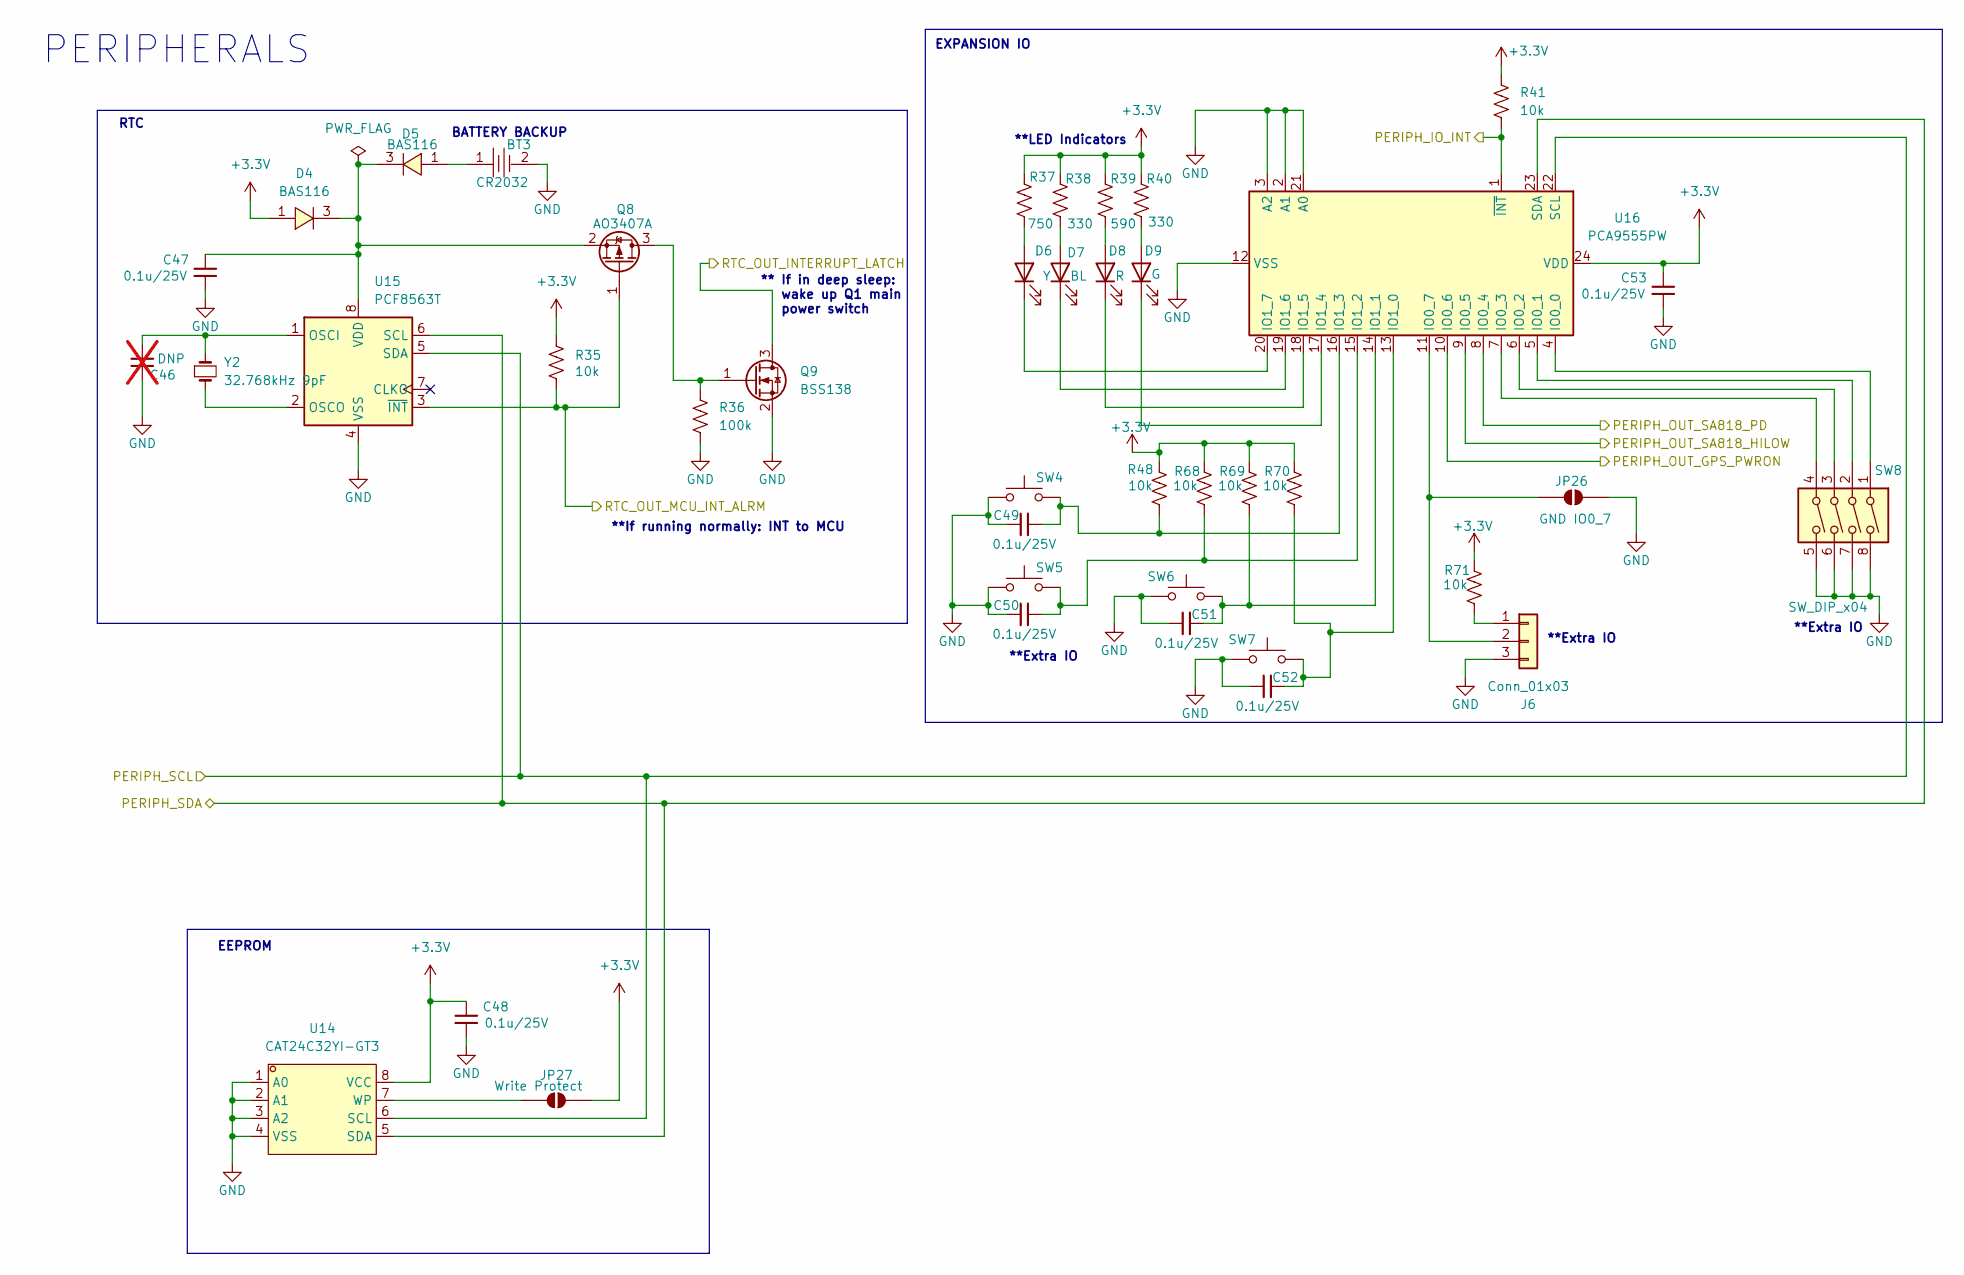
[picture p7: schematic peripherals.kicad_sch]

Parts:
BT3: CR2032; BAT-SMD_BS-08-B2AA016; MPN BS-08-B2AA020-R; LCSC Part C964787
C46: DNP; C_0603_1608Metric; not fitted
C47, C48, C49, C50, C51, C52, C53: 0.1u/25V; C_0603_1608Metric; MPN GRM188R71H104KA93D; LCSC Part # C77055
D4, D5: BAS116; SOT-23_L2.9-W1.3-P1.90-LS2.4-BR; MPN BAS116LT1G; LCSC Part # C232527
D6: Y; LED_0805_2012Metric; MPN APTD2012LSYCK; LCSC Part # C5588998
D7: BL; LED_0805_2012Metric; MPN APTD2012LQBC/D; LCSC Part # C5879058
D8: R; LED_0805_2012Metric; MPN APTD2012LSURCK; LCSC Part # C5366382
D9: G; LED_0805_2012Metric; MPN APT2012LZGCK; LCSC Part # C5569446
J6: Conn_01x03; JST_PH_B3B-PH-SM4-TB_1x03-1MP_P2.00mm_Vertical; MPN B3B-PH-SM4-TB(LF)(SN); LCSC Part # C160353
JP26: GND IO0_7; SolderJumper-2_P1.3mm_Open_TrianglePad1.0x1.5mm
JP27: Write Protect; SolderJumper-2_P1.3mm_Open_TrianglePad1.0x1.5mm
Q8: AO3407A; SOT-23; MPN AO3407A; LCSC Part # C15155
Q9: BSS138; SOT-23
R35, R41, R48, R68, R69, R70, R71: 10k; R_0603_1608Metric; MPN RT0603BRD0710KL; LCSC Part # C95204
R36: 100k; R_0603_1608Metric; MPN RC0603FR-07100KL; LCSC Part # C14675
R37: 750; R_0603_1608Metric; MPN RC0603FR-07750RL; LCSC Part # C114635
R38, R40: 330; R_0603_1608Metric; MPN RC0603FR-07330RL; LCSC Part # C105881
R39: 590; R_0603_1608Metric; MPN RC0603DR-07590RL; LCSC Part # C859077
SW4, SW5, SW6, SW7: GENERAL; SW_SPST_PTS645Sx43SMTR92; MPN K2-1102SP-A4SC-04; LCSC Part # C83916
SW8: SW_DIP_x04; SW_DIP_SPSTx04_Slide_KingTek_DSHP04TS_W7.62mm_P1.27mm; MPN DSHP04TS-S; LCSC Part # C319050
U14: CAT24C32YI-GT3; TSSOP-8_L4.4-W3.0-P0.65-LS6.4-BL; MPN CAT24C32YI-GT3; LCSC Part # C94264
U15: PCF8563T; SOIC-8_3.9x4.9mm_P1.27mm; MPN PCF8563T/5,518; LCSC Part # C7440
U16: PCA9555PW; TSSOP-24_4.4x7.8mm_P0.65mm; MPN PCA9555PWR; LCSC Part # C2864778
Y2: 32.768kHz 9pF; Crystal_SMD_3215-2Pin_3.2x1.5mm; MPN NX3215SA-32.768K-STD-MUA-9; LCSC Part # C519280

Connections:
+3.3V: C48.1, C53.1, D4.1, JP27.2 (B), R35.2, R37.1, R38.2, R39.1, R40.1, R41.2, R48.1, R68.1, R69.1, R70.1, R71.1, U14.8 (VCC), U16.24 (VDD); also elsewhere on the board
/GPS/GPS_IN_PWRON: U16.10 (IO0_6); also elsewhere on the board
/Peripherals/PERIPH_IO_INT: R41.1, U16.1 (~INT); also elsewhere on the board
/Peripherals/PERIPH_OUT_SA818_HILOW: U16.9 (IO0_5); also elsewhere on the board
/Peripherals/PERIPH_OUT_SA818_PD: U16.8 (IO0_4); also elsewhere on the board
/Peripherals/PERIPH_SCL: U14.6 (SCL), U15.5 (SDA), U16.22 (SCL); also elsewhere on the board
/Peripherals/PERIPH_SDA: U14.5 (SDA), U15.6 (SCL), U16.23 (SDA); also elsewhere on the board
/Peripherals/RTC_OUT_INTERRUPT_LATCH: Q9.3 (D); also elsewhere on the board
/Peripherals/RTC_OUT_MCU_INT_ALRM: Q8.1 (G), R35.1, U15.3 (~INT); also elsewhere on the board
GND: BT3.2, C46.1, C47.2, C48.2, C49.1, C50.1, C51.2, C52.2, C53.2, J6.3, JP26.2 (B), Q9.2 (S), R36.1, SW4.2, SW5.2, SW6.1, SW7.1, SW8.5, SW8.6, SW8.7, SW8.8, U14.1 (A0), U14.2 (A1), U14.3 (A2), U14.4 (VSS), U15.4 (VSS), U16.2 (A1), U16.3 (A2), U16.12 (VSS), U16.21 (A0); also elsewhere on the board
unnamed: BT3.1, D5.1
unnamed: D6.2 (A), R37.2
unnamed: D6.1 (K), U16.20 (IO1_7)
unnamed: D7.2 (A), R38.1
unnamed: D7.1 (K), U16.19 (IO1_6)
unnamed: D8.2 (A), R39.2
unnamed: D8.1 (K), U16.18 (IO1_5)
unnamed: D9.2 (A), R40.2
unnamed: D9.1 (K), U16.17 (IO1_4)
unnamed: J6.1, R71.2
unnamed: J6.2, JP26.1 (A), U16.11 (IO0_7)
unnamed: JP27.1 (A), U14.7 (WP)
unnamed: Q8.3 (D), Q9.1 (G), R36.2
unnamed: C47.1, D4.3, D5.3, Q8.2 (S), U15.8 (VDD)
unnamed: C46.2, U15.1 (OSCI), Y2.1
unnamed: U15.2 (OSCO), Y2.2
unnamed: SW8.1, U16.4 (IO0_0)
unnamed: SW8.2, U16.5 (IO0_1)
unnamed: SW8.3, U16.6 (IO0_2)
unnamed: SW8.4, U16.7 (IO0_3)
unnamed: C52.1, R70.2, SW7.2, U16.13 (IO1_0)
unnamed: C51.1, R69.2, SW6.2, U16.14 (IO1_1)
unnamed: C50.2, R68.2, SW5.1, U16.15 (IO1_2)
unnamed: C49.2, R48.2, SW4.1, U16.16 (IO1_3)

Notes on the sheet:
BATTERY BACKUP
**Extra IO
** If in deep sleep: wake up Q1 main power switch
EEPROM
**If running normally: INT to MCU
**LED Indicators
PERIPHERALS
RTC
EXPANSION IO

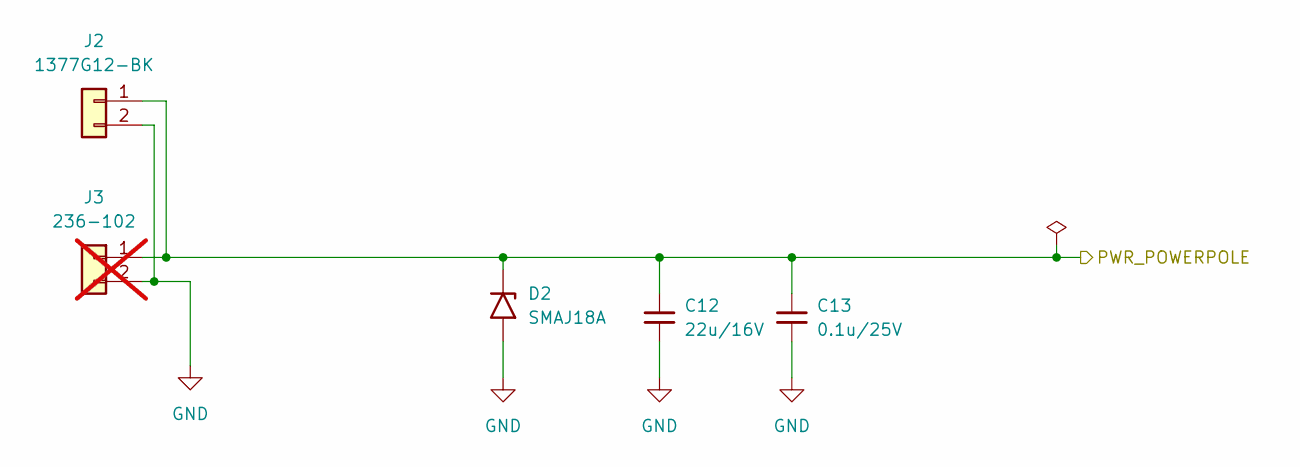
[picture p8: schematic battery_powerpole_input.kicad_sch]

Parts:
C12: 22u/16V; C_1206_3216Metric; MPN GRM31CZ71C226ME15L; LCSC Part # C909845
C13: 0.1u/25V; C_0603_1608Metric; MPN GRM188R71H104KA93D; LCSC Part # C77055
D2: SMAJ18A; D_SMA; MPN SMAJ18A; LCSC Part # C148219
J2: 1377G12-BK; Connector_Anderson_PP25_RA_1377g12-bk; MPN 1377G12-BK; Digikey PN 2243-1377G12-BK-ND
J3: 236-102; TerminalBlock_WAGO_236-102_1x02_P5.00mm_45Degree; MPN 236-102; not fitted

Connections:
/Power/Battery_PowerPole_Input/PWR_POWERPOLE: C12.1, C13.1, D2.1 (A1), J2.1, J3.1; also elsewhere on the board
GND: C12.2, C13.2, D2.2 (A2), J2.2, J3.2; also elsewhere on the board

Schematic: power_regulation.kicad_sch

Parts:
C14, C15, C20, C21, C26, C27, C28, C29: 0.1u/25V; C_0603_1608Metric; MPN GRM188R71H104KA93D; LCSC Part # C77055
C16, C17, C18, C19: 10u/25V; C_0603_1608Metric; MPN GRM188R61E106KA73D; LCSC Part # C344022
C22, C23, C24, C25: 22u/16V; C_1206_3216Metric; MPN GRM31CZ71C226ME15L; LCSC Part # C909845
C30, C31: 22u/16V Elec; C_Elec_5x5.8; MPN XT1C220M0506; LCSC Part # C5260805
JP12, JP14, JP16, JP18, JP22, JP24: Jumper_2_Open; TestPoint_2Pads_Pitch2.54mm_Drill0.8mm
JP20: 5V TEST LOAD; TestPoint_2Pads_Pitch2.54mm_Drill0.8mm
JP21: 3.3V TEST LOAD; TestPoint_2Pads_Pitch2.54mm_Drill0.8mm
L1, L2: 3.3uH; L_Chilisin_MHCI06030; MPN MHCI06030-3R3M-R8; LCSC Part # C108294
R18, R19, R20, R21: 10k; R_0603_1608Metric; MPN RT0603BRD0710KL; LCSC Part # C95204
R22: 76.8k; R_0603_1608Metric; MPN RT0603BRD0776K8L; LCSC Part # C705795
R23: 52.3k; R_0603_1608Metric; MPN RT0603BRD0752K3L; LCSC Part # C861462
R24: 24.9 2W; R_Axial_Power_L20.0mm_W6.4mm_P5.08mm_Vertical; not fitted
R25: 16.5 2W; R_Axial_Power_L20.0mm_W6.4mm_P5.08mm_Vertical; not fitted
U6, U7: TPS563201; SOT-23-6; MPN TPS563201DDCR; LCSC Part # C116592
U8: LM1085-5.0; TO-263-3_TabPin2; MPN LM1085IS-5.0RG; LCSC Part # C2865978
U9: LM1117IMPX-3.3; SOT-223-3_TabPin2; MPN LM1117IMPX-3.3/NOPB; LCSC Part # C23984

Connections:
/Power/Power Regulation/3V3_BUCK_OUT: C23.1, C25.1, JP18.1 (A), L2.2, R23.1
/Power/Power Regulation/3V3_BUCK_VIN: C15.1, C17.1, C19.1, JP14.2 (B), R19.2, U7.3 (VIN)
/Power/Power Regulation/3V3_LDO_OUT: C29.1, C31.1, JP21.2 (B), JP24.1 (A), U9.2 (VO)
/Power/Power Regulation/3V3_LDO_VIN: C27.1, JP18.2 (B), U9.3 (VI)
/Power/Power Regulation/4.8V_Intermediate: C21.1, L2.1, U7.2 (SW)
/Power/Power Regulation/5V_BUCK_OUT: C22.1, C24.1, JP16.1 (A), L1.2, R22.1
/Power/Power Regulation/5V_BUCK_VIN: C14.1, C16.1, C18.1, JP12.2 (B), R18.2, U6.3 (VIN)
/Power/Power Regulation/5V_LDO_OUT: C28.1, C30.1, JP20.2 (B), JP22.1 (A), U8.2 (VO)
/Power/Power Regulation/5V_LDO_VIN: C26.1, JP16.2 (B), U8.3 (VI)
/Power/Power Regulation/6V_intermediate: C20.1, L1.1, U6.2 (SW)
/Power/Power Regulation/BATT_3.3V_REG: JP24.2 (B); also elsewhere on the board
/Power/Power Regulation/BATT_5V_REG: JP22.2 (B); also elsewhere on the board
/Power/VRAW_GATED: JP12.1 (A), JP14.1 (A); also elsewhere on the board
GND: C14.2, C15.2, C16.2, C17.2, C18.2, C19.2, C22.2, C23.2, C24.2, C25.2, C26.2, C27.2, C28.2, C29.2, C30.2, C31.2, R20.1, R21.1, R24.2, R25.2, U6.1 (GND), U7.1 (GND), U8.1 (GND), U9.1 (GND); also elsewhere on the board
unnamed: JP20.1 (A), R24.1
unnamed: JP21.1 (A), R25.1
unnamed: R18.1, U6.5 (EN)
unnamed: C20.2, U6.6 (VBST)
unnamed: R20.2, R22.2, U6.4 (VFB)
unnamed: R19.1, U7.5 (EN)
unnamed: C21.2, U7.6 (VBST)
unnamed: R21.2, R23.2, U7.4 (VFB)

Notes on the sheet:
6V Intermediate Power
(Ref C1)
(Ref R1)
4.78V Intermediate Power
(Ref R2)
Vout = 0.768 (1 + R1/R2) <= R2=10k 4.7 = 0.768(1+R1/10k) => R1 = 51.2k => 52.3k => R2 = 10k = 4.78V L = 3.3uH typ from Table 7-2
6.6V Calculations ----------------
(Ref C9)
7.4V Nominal for 2x 18650 12-14V Nominal for Anderson Powerpole
5V rail: Buck pre-regulator: TPS563201 (4.5-17V in, 2A, synchronous), set to ~6V @ 2A intermediate output LDO cleanup stage: LM1085-5.0 (fixed 5V, 3A rated, ~1V dropout at 2A), taking the 6V intermediate down to a clean 5V
(Ref C2)
(Ref C8)
Icorms = (Vout * (Vin - Vout)) / (sqrt(12) * Vin * Lo * fsw) = 6.6 * (14.4 - 6.6) / (3.464 * 14.4 * 3.3e-6 * 588e3) = 0.531A
**6.6V**
4.7V Calculations ----------------
(Ref C3)
(Ref C7)
fsw = 588kHz from Section 5-5 or ~600kHz from Tables 5-6 IIp-p = (Vout/Vinmax) * ((Vinmax - Vout) / (Lo * fSw)) = (6.6/14.4) * ((14.4 -6.6) / (3.3e-6 * 588e3)) = 0.458 * (7.8 / 1.9404) = 1.84A IIpk = Io + IIp-p/2 = 2 + (1.84/2) = 2.92A ILO = sqrt(Io^2 + (1/12)(IIp-p)^2) = 2.07
Vout = 0.768 (1 + R1/R2) <= R2=10k 6.6 = 0.768(1+R1/10k) => R1 = 76k -> 76.8k => R2 = 10k L = 3.3uH typ from Table 7-2
3.3V rail: Buck pre-regulator: second TPS563201, set to ~4.3V @ 1A intermediate output LDO cleanup stage: LM1085-3.3 (fixed 3.3V, 3A rated), taking the 4.3V intermediate down to a clean 3.3V
**4.78V**

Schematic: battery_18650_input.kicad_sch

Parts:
BT1, BT2: Battery_Cell; BatteryHolder_MPD_BH-18650-PC; MPN BH-18650-PC; LCSC Part # C5339083; not fitted
C6, C7: 0.1u/25V; C_0603_1608Metric; MPN GRM188R71H104KA93D; LCSC Part # C77055
C8: 0.47u/25V; C_0805_2012Metric; MPN GCM219R71E474KA55D; LCSC Part # C437481
C9, C10, C11: 0.47u/10V; C_0603_1608Metric; MPN GRM188R71A474KA61D; LCSC Part # C435402
F1: CLM1612P1412; Fuse_PTCC_CLM1612; MPN CLM1612P1412; LCSC Part # C5353611
Q2: AO3400A; SOT-23; MPN AO3400A; LCSC Part # C20917
Q3: 8205A; SOT23-6L; MPN 8205A; LCSC Part # C22458966
R12: 10; R_0805_2012Metric; MPN RC0805FR-0710RL; LCSC Part # C96347
R13, R14: 150; R_1206_3216Metric; MPN RT1206BRD07150RL; LCSC Part # C870430
R15: 0.0025; RES-SMD_L6.4-W3.2-R2512_Sense4Pin; MPN HoJLR2512-3W-2.5mR-1%; LCSC Part # C2904234
R16: 1k; R_0805_2012Metric; MPN RC0805FR-071KL; LCSC Part # C95781
R17: 820; R_0805_2012Metric; MPN RC0805FR-07820RL; LCSC Part # C114544
TH1: NCP15XH103F03RC; R_0402_1005Metric; MPN NCP15XH103F03RC; LCSC Part # C77131
U5: MAX17320; TQFN-24-1EP_4x4mm_P0.5mm_EP2.1x2.1mm; MPN MAX17320G22+; LCSC Part # C2914309

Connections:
/Peripherals/PERIPH_SCL: U5.8 (SCL/OD); also elsewhere on the board
/Peripherals/PERIPH_SDA: U5.9 (SDA/DQ); also elsewhere on the board
/Power/BMS_ALRT: U5.7 (ALRT); also elsewhere on the board
/Power/Battery 18650 Input/BATT+: BT1.1 (+), F1.1, R12.1, R13.1
/Power/Battery 18650 Input/BATT_Plus_to_Minus: BT1.2 (-), BT2.1 (+), R14.1
/Power/Battery 18650 Input/PWR_18650: Q3.3 (S2), R16.2, R17.2; also elsewhere on the board
/Power/Battery 18650 Input/PolyFuseOut: F1.3, Q3.1 (S1)
GND: R15.4; also elsewhere on the board
GNDREF: BT2.2 (-), C6.2, C7.2, C9.2, C10.2, C11.2, Q2.2 (S), R15.1, TH1.2, U5.20 (GND), U5.25 (GND)
unnamed: F1.2, Q2.3 (D)
unnamed: Q2.1 (G), U5.11 (PFAIL)
unnamed: Q3.6 (G1), U5.3 (CHG)
unnamed: Q3.4 (G2), U5.4 (DIS)
unnamed: C11.1, U5.12 (AOLDO)
unnamed: R13.2, U5.24 (BATTS)
unnamed: C6.1, R14.2, U5.21 (CELL1), U5.22 (CELL2), U5.23 (CELL3)
unnamed: C8.1, U5.2 (CP)
unnamed: R15.3, U5.14 (CSN)
unnamed: R15.2, U5.15 (CSP)
unnamed: C7.1, C8.2, R12.2, U5.1 (IN)
unnamed: R16.1, U5.6 (PCKP)
unnamed: C10.1, U5.17 (REG2)
unnamed: C9.1, U5.13 (REG3)
unnamed: TH1.1, U5.10 (TH1)
unnamed: R17.1, U5.5 (ZVC)

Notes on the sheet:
18650s
R13: intentional GND/GNDREF split for current sensing — do not bridge elsewhere
BATTS: RBAL4 => IBALMAX = VCELLMAX / (2 x RBAL+ RSWITCH) CELL1: RBAL1 => IBALMAX = VCELLMAX / (RBAL+ RSWITCH) RSWITCH = 9ohm typ VCELLMAX = 4.2V for 18650 IBALMAX = 100mA => 50mA RBAL1 = 150ohm IBALMAX = 26mA = 105mW = use 1/4W 0805 minimum

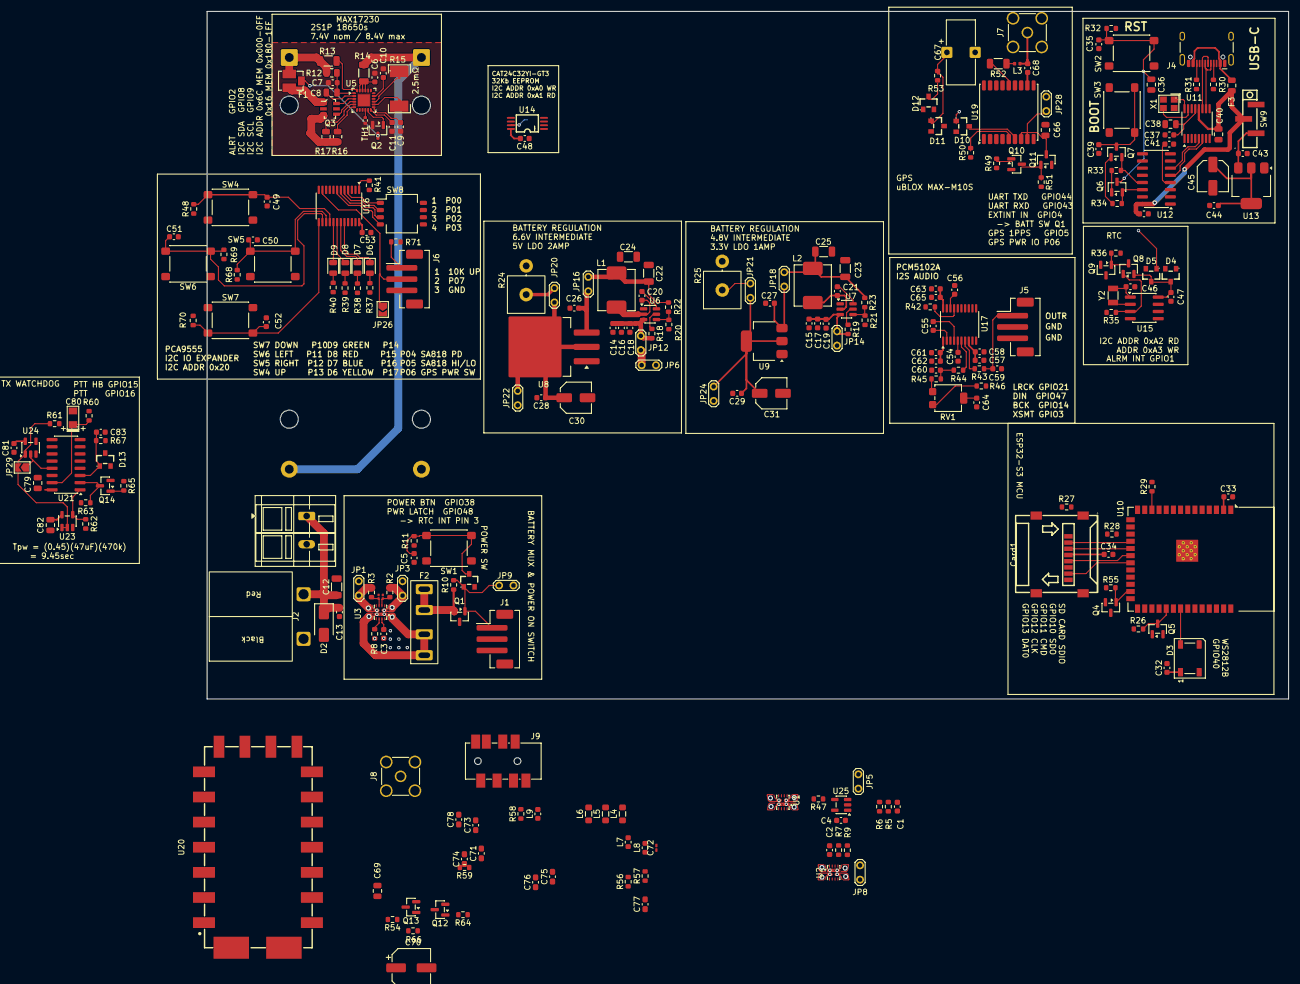
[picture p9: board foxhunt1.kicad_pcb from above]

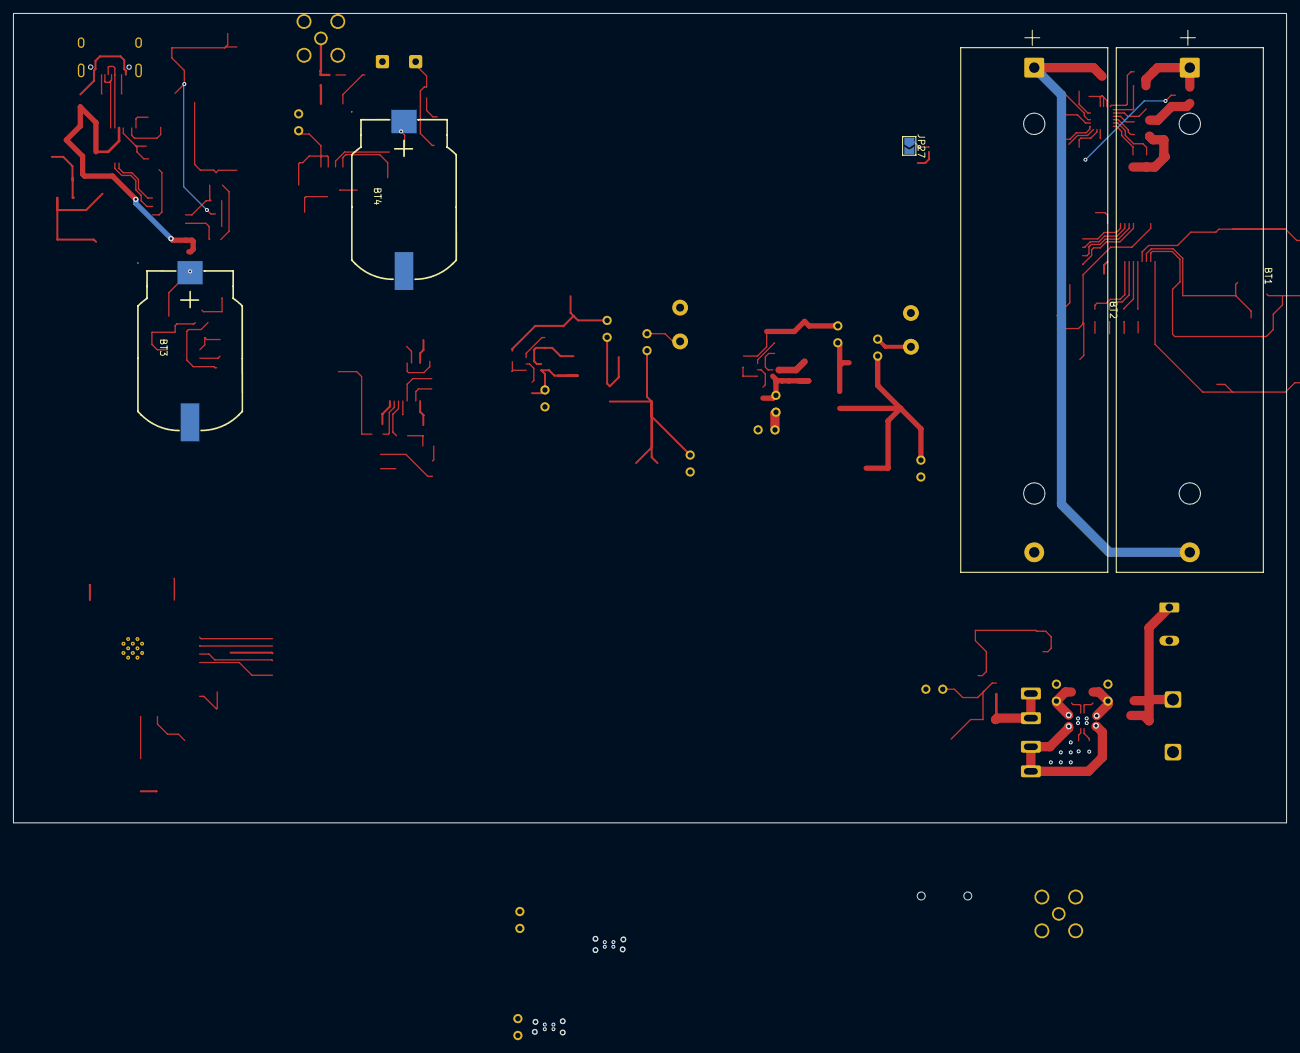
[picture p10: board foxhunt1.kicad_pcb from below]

Board: 4 copper layers, 191.5 x 121.8 mm, 260 parts (5 on the bottom side), 177 nets.

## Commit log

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2026-09-18 Make project library-portable; fix Q2 footprint reference
    Vendor the three non-standard libraries (kicad_gx_library,
    digikey-kicad-library, SparkFun-KiCad-Libraries) as git submodules
    under libs/, and add project-level sym-lib-table/fp-lib-table entries
    that resolve them via ${KIPRJMOD}, so the project no longer depends on
    this machine's global KiCad library setup.
    Also fixes Q2's footprint reference, which pointed at an unregistered
    "DigikeyGithub" library nickname left over from a prior library setup;
    it now correctly resolves to digikey-kicad-library:SOT23-6L.
    [foxhunt1.kicad_pcb, foxhunt1.kicad_sch]
2026-09-18 Clean up schematic wiring style across all sheets
    Remove 4-way branch junctions and component pins landed directly on
    a passing wire without an explicit stub/junction, across foxhunt1,
    anderson_pp_input, and power_regulation sheets. Verified with a
    branch-weight and pin-on-wire sweep after the fixes: 0 flagged points
    remaining on all three sheets.
    [anderson_pp_input.kicad_sch, foxhunt1.kicad_sch, power_regulation.kicad_sch]
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2026-09-18 Restore root schematic naming convention, fix stale symbol warnings
    Rename power_input.kicad_sch back to foxhunt1.kicad_sch (matching the
    project name) so Konnect's project-ownership resolution can find the
    root — it doesn't yet support KiCad 10's top_level_sheets feature and
    assumes <project>.kicad_sch is always the root. Hierarchy content and
    UUIDs are unchanged.
    Also runs Update Symbols from Library on battery_18650_input.kicad_sch
    and power_regulation.kicad_sch to clear 13 stale lib_symbol_mismatch
    ERC warnings (no pins moved). Full hierarchy ERC now passes clean:
    0 errors, 0 warnings.
    [battery_18650_input.kicad_sch, foxhunt1.kicad_pcb, foxhunt1.kicad_sch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]
2026-09-18 Bump kicad_gx_library submodule for footprint filename fix
    Picks up the Fuse_/Connector_ prefix restoration, resolving the
    footprint-not-found DRC errors flagged in the earlier PCB review.
2026-09-18 Label fragile jumper-hop nets and wire up power netclasses
    Add real net labels (5V_BUCK_VIN/OUT, 5V_LDO_VIN/OUT, 3V3_BUCK_VIN/OUT,
    3V3_LDO_VIN/OUT, BATT_PCKP, 12V_RAW) at points that previously relied on
    KiCad's auto-generated Net-(JPxx-x) names, which silently stop matching
    netclass patterns whenever a nearby component or jumper changes.
    Extend the three power netclasses (Power_Combined_3A/Power_5V_2A/
    Power_3V3_1A) to cover every jumper-isolated hop in the power path, not
    just the globally-named rails, and set board-wide DRC floors (0.15mm
    clearance/trace, 0.3mm via drill, 0.5mm via size) matching the
    configured JLCPCB fab constraints.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
    [battery_18650_input.kicad_sch, battery_powerpole_input.kicad_sch, power_regulation.kicad_sch]
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2026-09-18 Document the net_settings GUI-clobber failure mode
    Just hit this in practice: KiCad's GUI held a stale in-memory copy of
    foxhunt1.kicad_pro from before the netclasses existed, and overwrote
    Konnect's on-disk edits when it saved. Also corrects update_pcb_from_schematic's
    documented behavior — it's live-IPC-only with no closed-file fallback,
    unlike the other board tools.
2026-09-18 Document controller-platform decisions and ESP32-S3 pinout plan
    README §4: full writeup of the 13-topic planning discussion covering
    power sequencing (discrete soft-latch, RTC+button wake-OR), PCF8563
    RTC selection, MAX-M10S GPS with independent backup domain, ESP32-S3
    module choice, shared audio/PTT path for SA818S + external HT, SD/EEPROM
    storage, no onboard charging, forward-power sensing, LED placement
    strategy, hardware PTT-timeout safety circuit, frequency/tone plan,
    and skipping LoRa for this revision. Also refreshes stale ESP32-C3
    references and the downstream-loads table.
    _docs/esp32s3_pinout.md: full reference pin table transcribed from the
    actual Espressif datasheet PDF (not mem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
2026-09-18 Add forward-power comparator path, drop JTAG header, isolate USB power
    README §4.8 / pinout: the forward-power detector now feeds two paths
    instead of one — ADC1 (IO4) for calibrated level readback, plus a
    comparator (e.g. LM393-class) into a digital GPIO (IO41) for a fast,
    noise-immune antenna-fault flag that doesn't depend on ADC averaging
    near an active RF PA.
    Pinout: drop the JTAG-header option on pins 32/33 — ESP32-S3's native
    USB already includes a built-in USB Serial/JTAG peripheral, so full
    OpenOCD debug access comes for free over the same USB-C connector with
    no separate header needed. BOOT/RESET buttons stay regardless, since
    that's a different capability (auto-reset-into-boo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
2026-09-18 Migrate design-decision content from README into _docs/, add TOC strategy
    Moves the bulk of README.md (battery protection, power combining,
    regulation, the whole planned controller/peripheral platform, downstream
    loads, open items — over half the document) into _docs/hardware/ as
    separate topic files, so README stays a short front door instead of
    growing without bound as design work continues.
    Adds a two-tier TOC: README gets a small hand-curated list of just
    Setup/architecture-diagram/docs-index-link (stays small by construction,
    detail never lives here); _docs/README.md becomes the real index,
    grouped into hardware/ (design docs) and sourcing/ (BOM/datasheet/3D-model
    records, the 5 exis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
2026-09-18 Plan a dedicated USB-UART bridge alongside native USB, not a hub chip
    Adds a second USB connector for a CP2102N-class bridge with standard
    DTR/RTS auto-reset into EN/IO0, instead of Espressif's newer hub-chip
    reference pattern (single connector -> USB hub -> bridge + native).
    That pattern solves a connector-count problem retail dev boards have;
    this board doesn't, so two simple connectors beat adding a hub IC.
    Native USB keeps JTAG/CDC/flashing as before. Solves two real
    annoyances with native-USB-only during active dev: CDC re-enumerating
    on every reset (dropping/delaying the serial monitor), and native
    auto-reset's known version-dependent quirks.
    Planning-only — no schematic capture yet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
2026-09-19 Add ESP32-S3 MCU sheet and CH340C USB-UART programming bridge
    Restructures the schematic hierarchy: root sheet now hosts three
    top-level sheets (Power, mcu-esp32, USB-C Programming UART) instead of
    the old flat layout, with the battery/12V ORing-FET merge circuit
    moved into its own dedicated Power sheet. Adds the ESP32-S3-WROOM-1
    MCU sheet (native USB-C connector stubbed in but not yet wired) and a
    CH340C-based USB-UART bridge with auto-reset/bootloader transistor
    circuit for programming.
    This is a work-in-progress checkpoint — several nets in the new sheets
    (MCU decoupling, CH340C power, auto-reset routing, ORing FET gate
    drive) still need wiring before ERC will be clean; see prior revie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
    [battery_18650_input.kicad_sch, battery_powerpole_input.kicad_sch, foxhunt1.kicad_sch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]
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2026-09-19 Replace battery/PowerPole ORing FETs with TPS2121 in VCOMP mode
    power.kicad_sch: U12 (TPS2121RUXR) replaces the two LM74610+AO3400A ideal-
    diode branches, configured per TI's "Highest Voltage Operation" (VCOMP,
    Fig 10-15): PR1/CP2 tied to GND, OV1/OV2 resistor dividers (23.7k/5k) off
    IN1 (PWR_18650) and IN2 (PWR_POWERPOLE), ILM set via R24 (51.1k), SS
    ramped through C39 (0.01uF), ST tied directly to GND (unused). Divider
    topology, ILM, and SS/ST wiring were each wrong on the first pass and
    have been traced pin-by-pin and verified correct against the reference
    schematic.
    usbc-programming-uart.kicad_sch: CH340C VCC/V3 pin fix (VCC now correctly
    powered from VBUS, V3 no longer driven externall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
    [battery_18650_input.kicad_sch, power.kicad_sch, usbc-programming-uart.kicad_sch]
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2026-09-20 Full re-annotation, BOM audit fixes, Stage-1 ILM resize, and PCB reset
    Schematic: re-annotated reference designators project-wide (3rd pass) --
    every real component's designator has shifted since the last commit.
    Fixed BOM gaps found by the fresh audit: U13 (CH340C) sourcing fields,
    R7's Manf typo (YAGE -> YAGEO), R5/R8/R14 missing LCSC Part#s, and
    normalized U1/U2/U3 (TPS2121RUXR) field names from easyeda2kicad's
    defaults (Manufacturer/LCSC Part) to this project's convention
    (Manf/LCSC Part #). Resized Stage 1's ILM resistor (R8) from 51.1k to
    30.1k -- the prior value undersized the current limit for carrying both
    downstream rails' combined battery-side current.
    pcb/foxhunt1.kicad_pcb: cle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
    [battery_18650_input.kicad_sch, battery_powerpole_input.kicad_sch, foxhunt1.kicad_pcb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]
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2026-09-20 Update docs to match as-built VRAW latch, RTC, and TPS2121 combining
    - power_input_combining.md: replace stale LM74610-Q1/AO3400A description
    with the actual TPS2121 VCOMP-mode combiner
    - power_architecture.md, README.md: fix diagrams (ORing FETs -> TPS2121,
    add the missing VRAW soft-latch stage)
    - controller_platform.md: mark Power sequencing and Timekeeping as
    implemented with as-built detail (AO3407A latch, Q8/Q7 inverter/
    level-shift chain for RTC INT, coin-cell diode-OR, CLKOUT firmware
    note, I2C pull-up placement); rest of doc still planning-only
    - battery_protection.md: fix stale shunt designator (R3 -> R13)
    - open_items.md, _docs/README.md: reflect partial controller-platfo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
2026-09-20 Add I2C bus doc; move LEDs to a GPIO expander; fix pinout doc drift
    - New i2c_bus.md: device addresses (RTC 0x51, fuel gauge 0x36/0x0B,
    EEPROM 0x50, GPIO expander 0x20-0x27), verified against real
    datasheets/driver source rather than assumed
    - esp32s3_pinout.md: TX-active/heartbeat LEDs moved to an I2C GPIO
    expander, freeing IO3/IO39; IO38 now concretely assigned to the
    power button's second pole; fixed IO42's stale "spare" claim (it's
    actually IO_IN_ON_BATT, already wired) found by cross-checking the
    live schematic instead of trusting the doc
    - controller_platform.md: document the LED/expander decision
    - open_items.md: add the GPIO expander as a peripheral to implement,
    update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
2026-09-20 Add IC inventory doc; RTC VDD bypass cap, CR2032 holder, SD holder note
    - New _docs/ic_inventory.md: every IC/module placed or planned, LCSC
    MPN/price/stock/brand for each, real parts chosen for not-yet-placed
    items per stated price/stock/brand-reputation preference
    - peripherals.kicad_sch: VDD/VSS bypass cap (C44) on U14, and the
    physical CR2032 holder footprint in place of the bare cell symbol
    - controller_platform.md: record the Molex 472192001 (LCSC C164170)
    flip-top microSD holder choice
    - Bump kicad_gx_library for the battery holder and microSD socket parts
    [peripherals.kicad_sch]
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2026-09-20 Wire up PCA9555 expansion IO section, source LEDs/resistors, swap 3.3V LDO to LM1117
    - PCA9555PW expansion IO: DIP switch (SW4, IO0_0-3), onboard buttons
    (SW7-10), status LEDs (D7-10) with sourced series resistors, external
    JST breakouts (J4-7/R39-42) for IO0_4-7, INT pull-up (R34), VDD bypass
    (C49), address pins grounded (addr 0x20)
    - Route PCA9555 INT (PERIPH_IO_INT) across the Power/mcu-esp32 top-level
    sheets to the ESP32-S3 (MCU_IN_IO_INT)
    - Source real YAGEO MPN/LCSC part numbers for R30/R31/R34-R42
    - Fix D10 LED (was orange 0603 with an LCSC part# that resolved to a
    different, wrong part) -> yellow 0805 APTD2012LSYCK, verified Vf/LCSC
    match, matching D7-9's package family
    -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
    [foxhunt1.kicad_sch, mcu-esp32.kicad_sch, peripherals.kicad_sch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]
2026-09-20 Bump kicad_gx_library submodule pointer
    Picks up BAS116LT1G's pin 2 electrical-type fix (unspecified -> no_connect).
    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
2026-09-20 Fix DRC/ERC issues: PWR_FLAG on USB-C UART VBUS net, BAS116 NC pin resync
    - Add PWR_FLAG to the unpowered net on usbc-programming-uart.kicad_sch
    to resolve an ERC power-pin-not-driven error
    - Re-sync D2/D3 (BAS116LT1G) in peripherals.kicad_sch from the library
    to pick up the corrected pin 2 electrical type
    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
    [peripherals.kicad_sch, usbc-programming-uart.kicad_sch]
2026-09-20 fix some drc issues
    [foxhunt1.kicad_sch, peripherals.kicad_sch, power.kicad_sch]
2026-09-20 Add U4 decoupling cap, source U15 MPN, improve GND/GNDREF visual distinction
    - Add local decoupling capacitor to U4 (74LVC1G08) VCC/GND
    - Add missing Manf/MPN/LCSC Part# to U15 (PCA9555PWR, TI, C2864778) found
    during a full net-trace design review
    - Color all GNDREF net wires in battery_18650_input.kicad_sch orange to
    make the intentional GND/GNDREF current-sense split (bridged only by
    R13) visually obvious on the canvas, not just from the net name
    - Add a schematic text note at R13 documenting the split for reviewers
    without access to CLAUDE.md
    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
    [battery_18650_input.kicad_sch, peripherals.kicad_sch, power.kicad_sch]
2026-09-21 Bump kicad_gx_library submodule pointer
    Picks up localized datasheets for BAS116LT1G, BS-08-B2AA020-R,
    CAT24C32YI-GT3, and TPS2121RUXR, plus the previously-missing
    CAT24C32YI-GT3 footprint file.
    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
2026-09-21 Document SD card wiring, footprint-verification task, and recurring-task updates
    - Add SD card (Molex 472192001, SPI mode) as implemented across
    controller_platform.md, esp32s3_pinout.md (pins 18/19/20/21 now wired),
    open_items.md, and the top-level docs index; note the FSPI D/Q naming
    convention and the still-missing CS pull-up (10k recommended)
    - Add two new recurring agent tasks: datasheet_localization.md and
    footprint_verification.md, plus footprint_verification.md's first-run
    output log
    - Fold in the BOM property audit's fixes (R29 was silently a 10k part under
    a 1M designator, Q6/Q7 sourcing gaps, BT2 exception wording) and the
    datasheet-localization pass results into the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
2026-09-21 Wire SD card interface, fix R29/Q6/Q7 sourcing, localize datasheets project-wide
    - SD card (Card1, Molex 472192001) wired to the FSPI (SPI2) peripheral:
    IO10/FSPICS0->CS, IO11/FSPID->MOSI, IO12/FSPICLK->SCLK, IO13/FSPIQ->MISO;
    shield/mounting tabs renamed SHLD and grounded; local decoupling cap added
    - R29 was silently a 10k YAGEO part (RC0603FR-0710KL/C98220) sitting under a
    1M designator -- corrected to the real 1M part (RC0603FR-071ML/C105578),
    matching this rail's documented VRAW soft-latch bleed design intent
    - Q6, Q7 (BSS138): added missing Manf/MPN/LCSC Part# (onsemi BSS138LT1G,
    C82045)
    - C32/C36: normalized Value strings; fixed C36's Datasheet, which pointed to
    a differen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
    [battery_18650_input.kicad_sch, battery_powerpole_input.kicad_sch, mcu-esp32.kicad_sch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]
2026-09-21 Fix remaining mass-symbol-update reversions (67 Datasheet + 5 Footprint fields)
    The project-wide "Update Symbols from Library" run reverted far more than
    the 4 caught in the previous commit -- most of that commit's own claimed
    "localized project-wide" state was actually already the reverted state,
    since the mass update happened before that commit and git history alone
    couldn't detect it. Cross-referenced every component's Datasheet/Footprint
    against the independent tracking docs (project_library_datasheets.md,
    kicad_gx_library_datasheets.md, footprint_verification_log.md) instead.
    - 67 components: Datasheet reverted from a localized ${KIPRJMOD} path back
    to a remote URL, across all 8 sche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
    [battery_18650_input.kicad_sch, mcu-esp32.kicad_sch, peripherals.kicad_sch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]
2026-09-21 Document hold-to-power-off isolation and mass-update lesson learned
    - controller_platform.md, esp32s3_pinout.md, open_items.md: replace the
    stale "DPST second pole" plan with what actually got built -- SW3's own
    isolated node (R45 pull-up + D5 diode-OR into PWR_LATCH), level-shifted
    via Q9 into GPIO38 (active-high). Split remaining open work into
    firmware (poll/time/release) and the still-unbuilt hardware-independent
    force-off (spare 74HC123 half)
    - CLAUDE.md: record the mass "Update Symbols from Library" reversion
    incident and how to detect/avoid it next time
    Claude-Session: https://claude.ai/code/session_01LhLkuH6sQ5GbUZ6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
2026-09-21 Fix second mass-symbol-update reversion (recurred at same scale)
    Same class of damage as the previous fix (commit 4ab9510) -- another
    project-wide symbol resync reverted ~65 Datasheet fields and 5 Footprints
    (Y2 crystal back to the wrong 5.0x3.2mm package again, U9/U12/U10/Y1
    footprints back to non-stock equivalents) across all 7 schematic files.
    Restored every field to its previously-verified value.
    Also caught two real, independent bugs surfaced while re-checking (not
    caused by this reversion, pre-existing): R32/R33/R43/R18 (10k YAGEO
    RT0603BRD0710KL pull-ups, C95204) all had a mismatched Datasheet pointing
    to a different resistor's PDF (RC0805FR-0710KL, wrong package family);
    C36's Datas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
    [foxhunt1.kicad_sch, mcu-esp32.kicad_sch, power.kicad_sch]
2026-09-21 Add I2S audio (PCM5102A) and GPS (MAX-M10S) schematic sheets
    Audio: PCM5102A DAC with charge-pump network, per-channel output
    filters, OUTL mic-level attenuator (divider + DC-block cap) for
    SA818S/HT feed, OUTR spare-channel JST breakout, XSMT wired to the
    board's last spare GPIO (GPIO3) for MCU-controlled muting.
    GPS: MAX-M10S module, UART+PPS to ESP32-S3 (IO17/IO18/IO5), SMA RF
    input with active-antenna bias-tee (bench through-hole SMA connector
    for now, SMD swap planned), CR2032 holder placed (backup diode-OR
    network not yet wired in).
    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
    [audio.kicad_sch, foxhunt1.kicad_sch, gps.kicad_sch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]
2026-09-21 Document audio/GPS interconnect plans and correct backup-power design
    - audio_ptt_path.md: new doc, PCM5102A pin table, OUTL attenuator math
    (100k/1k trimmer/150R + 4.7uF DC-block, verified against placed
    parts), OUTR spare-channel breakout, XSMT->GPIO3 wiring documented
    (GPIO3 strapping-pin pull-up direction flagged for verification).
    - gps_path.md: new doc, MAX-M10S pin table, corrected bias-tee
    topology (C67 is a series DC-block, not a shunt filter, per real
    wiring + physics check), corrected backup-power diode topology
    (supercap must charge from V_BCKP so can't share the coin cell's
    blocking diode), real V_BCKP abs-max (3.6V, zero margin) sourced
    from the datasheet, Eaton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
2026-09-21 Reconcile documentation with live schematic state
    Full audit of all hardware/sourcing docs against the actual placed
    schematic, ahead of the next round of circuit additions:
    - usb_battery_power_mux.md: flip from "planning only" to
    implemented — all three TPS2121s (U1/U2/U3) and the ST-combiner
    AND gate (U4, 74LVC1G08) are placed in power.kicad_sch.
    - power_architecture.md: top-level diagram only showed 2 power
    sources; added USB as the third, with the Stage 2/3 TPS2121 muxes
    now built downstream of regulation.
    - controller_platform.md, README.md, open_items.md: GPS and the
    audio/PTT DAC path were still marked planning-only; both are
    placed (gps.kicad_sch, audio.kicad_sch). Upd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
2026-09-21 Add external HT jack (J11) and PTT keying FET (Q10)
    J11 (CUI/Same Sky SJ2-3593D-SMT-TR, switched TRS): tip and ring
    switches auto-disconnect the onboard SA818S audio/PTT feeds the
    instant something is plugged in. Q10 (BSS138) keys the shared PTT
    node from GPIO16, with R53 (10k) pull-up holding it released by
    default. Reviewed: T/TN and R/RN wiring both verified correct
    against the jack's normalling behavior.
    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
    [audio.kicad_sch, foxhunt1.kicad_sch, mcu-esp32.kicad_sch]
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2026-09-21 Add SA818S-V sheet, update GPS antenna connector, MCU GPIO reassignments
    - New SA818S-V sheet (U19): UART/PTT/MIC_IN wired; VBAT, ANT, PD, H/L
    still open (see sa818_pinout.md).
    - gps.kicad_sch: J10 swapped to Amphenol 132289 edge-launch SMD SMA
    (same part planned for the SA818 antenna connector).
    - mcu-esp32.kicad_sch: SA818 UART on IO6/IO7, PTT on IO16 (direct FET
    drive via Q10, not the originally-planned AND-gate scheme).
    - peripherals.kicad_sch: in-progress PCA9555 channel changes.
    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
    [SA818V.kicad_sch, foxhunt1.kicad_sch, gps.kicad_sch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]
2026-09-21 Add SA818S-V pinout doc, reconcile esp32s3_pinout.md with live schematic
    New sa818_pinout.md: full real pin table for U19, what's wired
    (UART/PTT/MIC_IN) vs. still open (VBAT, ANT, PD, H/L, EP1/EP2).
    esp32s3_pinout.md: fresh ERC-verified audit confirms exactly 4
    unconnected pins (IO15 spare, IO46 strapping, IO4/IO41 forward-power
    pair still planning). Corrected 6 stale rows that were actually wired
    but still shown blank (IO5, IO17, IO18, IO14, IO21, IO47). Added
    judgment-call notes for the SA818 PD/H-L-via-PCA9555 plan and the GPS
    hardware-backup-mode power-gating idea.
    Claude-Session: https://claude.ai/code/session_01LhLkuH6sQ5GbUZ61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
2026-09-21 Wire SA818 PD/H-L and PTT opto, GPS power gating with bench bypass, RF detector groundwork
    - SA818S-V: wire PD/H-L to PCA9555 expander outputs; swap PTT-keying FET
    for PC817 optocoupler isolation on the shared SA818S/external-HT PTT line
    - GPS: add Q10 (AO3407A) high-side P-FET gating VCC+VCC_IO together for
    genuine hardware backup mode, driven via Q13 level-shifter from a new
    PCA9555 output (PERIPH_OUT_GPS_PWRON); add JP28 as a source-to-drain
    bench bypass across Q10 for unconditional power during bring-up; wire
    EXTINT to another PCA9555 output (PERIPH_OUT_GPS_EXTINT, pulled low by
    R57) to experiment with UART software-standby + external wake
    - peripherals: reassign PCA9555 chan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
    [SA818V.kicad_sch, audio.kicad_sch, foxhunt1.kicad_sch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]
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2026-09-23 Move audio jack (J6) into SA818V sheet, rename nets/jumpers for clarity
    Relocates the switched TRS jack from audio.kicad_sch into SA818V.kicad_sch
    and updates the root sheet's pin interface to match (SA818_IN_MIC,
    SA818_IN_PTT, new SA818_IN_PTT_HB), fixing an I2C_MIC_OUT/I2S_MIC_OUT
    naming typo along the way. Ring/ring-switch/sleeve are wired; tip and
    tip-switch (mic audio leg) are still open, per audio_ptt_path.md.
    Also: renames GPS hierarchical labels and several power/regulation/
    peripheral jumper values from generic (Jumper_2_Open, SolderJumper_2_Open)
    to descriptive names, wires MCU_OUT_PTT_HB, and removes now-unused test
    points/jumpers from the battery input sheets. Adds 74hc123_pinou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
    [SA818V.kicad_sch, audio.kicad_sch, battery_18650_input.kicad_sch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]
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2026-09-23 Add power-up glitch guard (R67/C83/D13) on U21A's 1R̄D, doc + submodule bump
    Implements Nexperia's Fig. 12 power-up circuit on U21 (74HC123) pin 3
    (1R̄D), which was previously hard-tied to +3.3V: R67 (10k) charges C83
    (0.1uF/25V) to hold reset briefly after power-up and block a spurious
    TX-safety pulse from rail noise, and D13 (BAS116, reusing the same
    part as D2/D3/D5) fast-discharges C83 on power-down so the guard is
    reliable across quick power-cycles, not just cold boot.
    Bumps the kicad_gx_library submodule pointer for the newly-imported
    Vishay TMCMA1A476MTRF (47uF tantalum, C80's real sourced part) symbol/
    footprint/3D model, committed and pushed there separately.
    74hc123_pinout.md u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
    [SA818V.kicad_sch]
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
